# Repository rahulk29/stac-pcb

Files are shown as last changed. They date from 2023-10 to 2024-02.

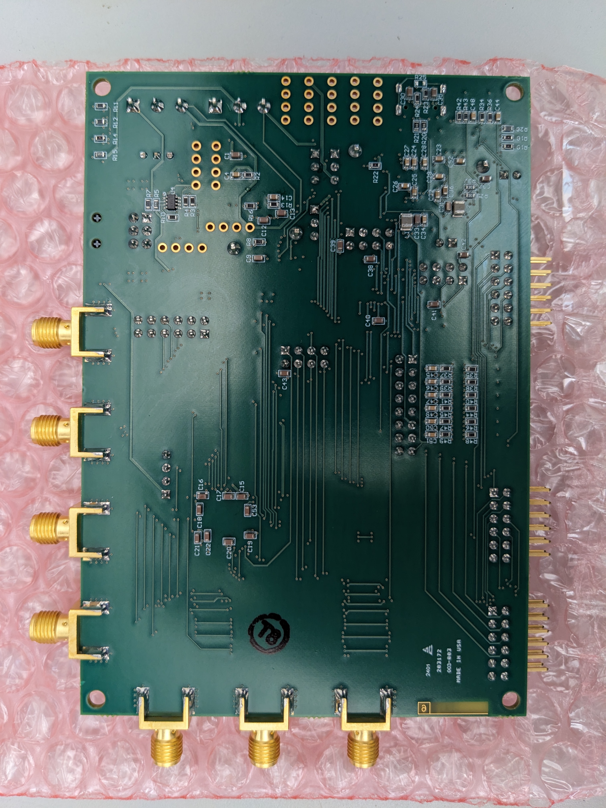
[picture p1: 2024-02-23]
photos/stac_back.jpg

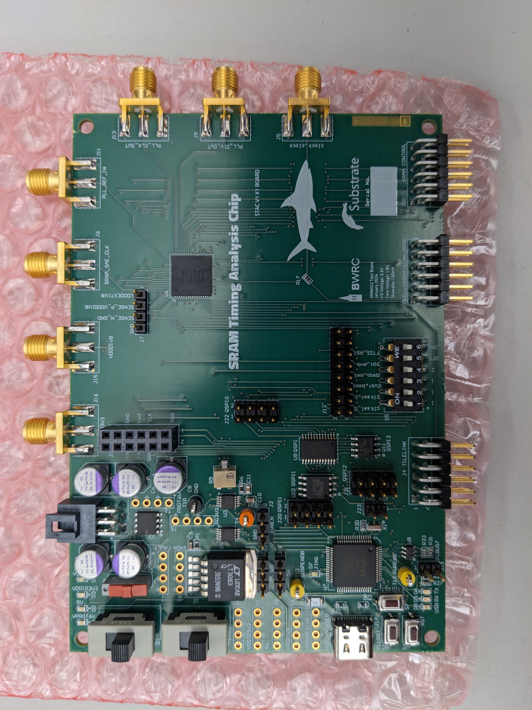
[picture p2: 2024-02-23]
photos/stac_front.jpg

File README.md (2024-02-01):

# STAC PCB

This repo contains the PCB for the SRAM Timing Analysis Chip (STAC).

See the [STAC repo](https://github.com/ucb-bar/stac-top) for more information on STAC.
In short: the STAC chip contains several test SRAM instances generated by SRAM22,
along with circuitry for measuring SRAM correctness and access time.

Also see the [STAC test plan](https://github.com/ucb-bar/stac-top/blob/stac-master/docs/test_plan.md).

## Contributing

Contributions can be submitted by opening a pull request against the `main` branch
of this repository.

Unless you explicitly state otherwise, any contribution intentionally submitted for inclusion
in the work by you shall be licensed under the BSD 3-Clause license, without any additional terms or conditions.

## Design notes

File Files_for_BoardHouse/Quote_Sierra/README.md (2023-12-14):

We received two quotes from Sierra:
* Q1594905-1.doc, which is for 5 day turnaround with blue soldermask.
* Q1594905-2.doc, which is for 10 day turnaround with green soldermask.

Switching to green + 10 days saves over $1,000.

To use an LPI soldermask process, the min pad to pad clearance / soldermask sliver is:
* 8 mils pad to pad (1.5 mil clearance min and 5 mil min web) if the color is not green
* 1.5 mil clearance and 4 mil min web so 7 mils if the color is green

If we are below these thresholds, the soldermask process gets bumped up to LDI-LPI.
Non-green soldermask is expensive because STAC/PROPEL's min soldermask sliver is 7.7 mils,
which requires LDI-LPI. Sierra also seems to charge more for colors other than green, even if
the soldermask process were to be LPI.

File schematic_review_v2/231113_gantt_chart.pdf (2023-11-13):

1 | Summary Test Board Design & Fab | 41 days? | 10/26/23 8:00 AM | 12/21/23 5:00 PM
2 | Create Test Plan doc | 0 days? | 10/26/23 8:00 AM | 10/26/23 8:00 AM
3 | Read wiki PCB Tool Ch01 | 0 days? | 10/26/23 8:00 AM | 10/26/23 8:00 AM
4 | Create new board repo, Test Plan folder | 0 days? | 10/26/23 8:00 AM | 10/26/23 8:00 AM
5 | Designate Chief & First Mate for board | 0 days? | 10/26/23 8:00 AM | 10/26/23 8:00 AM
6 | Create Altium schematic symbol for chip | 0 days? | 10/26/23 8:00 AM | 10/26/23 8:00 AM
7 | Paste chip/pkg schematic symbol into Test Plan doc | 0 days? | 10/26/23 8:00 AM | 10/26/23 8:00 AM
8 | Make decisions about #boards to fab/stuff | 0 days? | 10/26/23 8:00 AM | 10/26/23 8:00 AM
9 | Create Altium schematic for test board | 2 days? | 10/26/23 8:00 AM | 10/27/23 5:00 PM
10 | Make decisions on connector part numbers | 0 days | 10/26/23 8:00 AM | 10/26/23 8:00 AM
11 | Make decisions on reset switches, voltage domains | 0 days | 10/26/23 8:00 AM | 10/26/23 8:00 AM
12 | Add part records to PartSync if new parts | 0 days | 10/26/23 8:00 AM | 10/26/23 8:00 AM
13 | Create new Altium pcb project | 0 days | 10/26/23 8:00 AM | 10/26/23 8:00 AM
14 | Set Altium hierarchical project options | 0 days | 10/26/23 8:00 AM | 10/26/23 8:00 AM
15 | Make power domains global variables | 1 day? | 10/26/23 8:00 AM | 10/26/23 5:00 PM
16 | Put sheet symbols on top-level schematic | 0 days | 10/26/23 5:00 PM | 10/26/23 5:00 PM
17 | Place schematic symbols f/BWRC.SchLib not web | 0 days | 10/26/23 5:00 PM | 10/26/23 5:00 PM
18 | Add manufacturer's part number to all ICs, conns | 0 days? | 10/26/23 5:00 PM | 10/26/23 5:00 PM
19 | Check Altium project's Parameter Manager | 1 day | 10/27/23 8:00 AM | 10/27/23 5:00 PM
20 | Wire up schematic | 0 days | 10/27/23 5:00 PM | 10/27/23 5:00 PM
21 | Re-set reference designators and re-annotate | 0 days | 10/27/23 5:00 PM | 10/27/23 5:00 PM
22 | Compile Altium project, check erro Messages | 0 days | 10/27/23 5:00 PM | 10/27/23 5:00 PM
23 | Fill in title block for each schematic sheet | 0 days | 10/27/23 5:00 PM | 10/27/23 5:00 PM
24 | Create Altium output files for hand-off | 1 day? | 10/27/23 5:00 PM | 10/30/23 5:00 PM
25 | Read wiki PCB Tool Ch10d first half | 1 day | 10/30/23 8:00 AM | 10/30/23 5:00 PM
26 | Add Outjob file to Altium pcb project | 0 days | 10/27/23 5:00 PM | 10/27/23 5:00 PM
27 | Generate pick-and-place file from Outjob window | 1 day? | 10/30/23 8:00 AM | 10/30/23 5:00 PM
28 | Generate schematic pdf from Outjob window | 0 days | 10/30/23 5:00 PM | 10/30/23 5:00 PM
29 | Create folder in board repo for Schematics_pdf | 0 days | 10/30/23 5:00 PM | 10/30/23 5:00 PM
30 | Store latest pdf of schematics there with date/time | 0 days | 10/30/23 5:00 PM | 10/30/23 5:00 PM
31 | Create Bill of Materials in BOM Builder | 1 day? | 10/27/23 5:00 PM | 10/30/23 5:00 PM
32 | Read wiki Ch10d second half | 1 day? | 10/30/23 8:00 AM | 10/30/23 5:00 PM
33 | Configure BOM Builder options | 0 days | 10/27/23 5:00 PM | 10/27/23 5:00 PM
34 | Configure RefDesMapping file for BOM Builder | 0 days | 10/27/23 5:00 PM | 10/27/23 5:00 PM
Name | Duration | Start | Finish

Test Board Design - page1

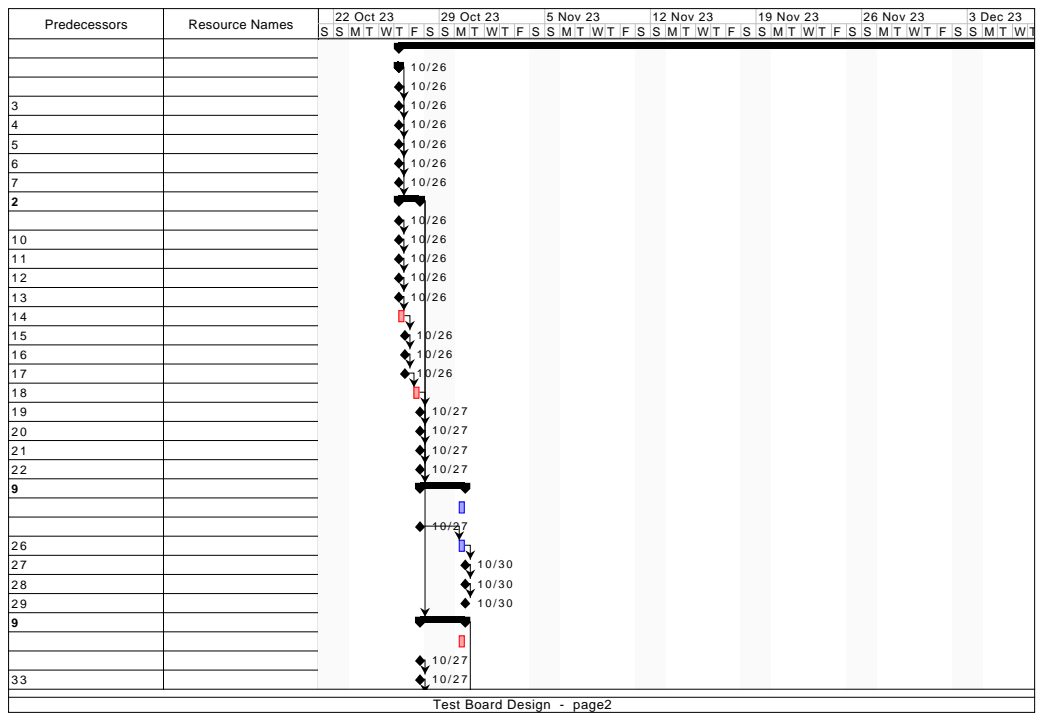
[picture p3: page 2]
22 Oct 23; 29 Oct 23; 5 Nov 23; 12 Nov 23; 19 Nov 23; 26 Nov 23; 3 Dec 23; Predecessors; Resource Names

7 Jan 24

14 Jan 24
M | T | W T | F | S

35 | Configure inpul list processor .dll for importing parts | 0 days | 10/27/23 5:00 PM | 10/27/23 5:00 PM
36 | Import Pick-and-Place file into BOM Builder | 0 days | 10/27/23 5:00 PM | 10/27/23 5:00 PM
37 | Match each line item to real PartSync part | 1 day? | 10/30/23 8:00 AM | 10/30/23 5:00 PM
38 | Create Job directory on G: shared drive for .bmb | 0 days | 10/30/23 5:00 PM | 10/30/23 5:00 PM
39 | Save .bmb file to Job directory | 0 days | 10/30/23 5:00 PM | 10/30/23 5:00 PM
40 | Add Bill of Materials to PartSync | 1 day? | 10/30/23 5:00 PM | 10/31/23 5:00 PM
41 | Read wiki Ch10e | 1 day? | 10/31/23 8:00 AM | 10/31/23 5:00 PM
42 | Import .bmb into PartSync as part list record | 0 days | 10/30/23 5:00 PM | 10/30/23 5:00 PM
43 | Create purchase lilst for build of desired number + spares | 1 day? | 10/31/23 8:00 AM | 10/31/23 5:00 PM
44 | Create folder in repo Files_for_AssemblyHouse | 0 days | 10/31/23 5:00 PM | 10/31/23 5:00 PM
45 | Save purchase list pdf to Files_for_AssemblyHouse | 0 days | 10/31/23 5:00 PM | 10/31/23 5:00 PM
46 | Check schematics & parts | 2 days | 11/1/23 8:00 AM | 11/2/23 5:00 PM
47 | Check schematic pdfs, parts list and fix errors | 1 day | 11/1/23 8:00 AM | 11/1/23 5:00 PM
48 | Iterate and communicate amongst designers | 1 day | 11/2/23 8:00 AM | 11/2/23 5:00 PM
49 | Update personal Gantt chart | 1 day? | 11/3/23 8:00 AM | 11/3/23 5:00 PM
50 | Estimate timelines for post Test Plan Review design changes | 1 day? | 11/3/23 8:00 AM | 11/3/23 5:00 PM
51 | Estimate timelines for ordering parts and/or pastemask stencils | 1 day? | 11/3/23 8:00 AM | 11/3/23 5:00 PM
52 | Estimate timelines for layout tasks post Test Plan Review | 1 day? | 11/3/23 8:00 AM | 11/3/23 5:00 PM
53 | Estimate timeline for checking layout for correctness | 1 day? | 11/3/23 8:00 AM | 11/3/23 5:00 PM
54 | Estimate timelines for comms with vendors | 1 day? | 11/3/23 8:00 AM | 11/3/23 5:00 PM
55 | Estimate timelines for BearBuy orders to vendors | 1 day? | 11/3/23 8:00 AM | 11/3/23 5:00 PM
56 | Estimate timelines for vendor manufacturing & shipping | 1 day? | 11/3/23 8:00 AM | 11/3/23 5:00 PM
57 | Add all steps for testing procedures | 1 day? | 11/3/23 8:00 AM | 11/3/23 5:00 PM
58 | Designers Review | 1 day? | 11/3/23 8:00 AM | 11/3/23 5:00 PM
59 | Chief and First mate and any other designers of the test board meet | 1 day? | 11/3/23 8:00 AM | 11/3/23 5:00 PM
60 | Compare each others Gantt charts and estimates | 1 day? | 11/3/23 8:00 AM | 11/3/23 5:00 PM
61 | Review schematics, test plan and final parts list together | 1 day? | 11/3/23 8:00 AM | 11/3/23 5:00 PM
62 | Correct any errors, make changes to hand-off docs | 1 day? | 11/3/23 8:00 AM | 11/3/23 5:00 PM
63 | Store corrected hand-off docs to git | 1 day? | 11/3/23 8:00 AM | 11/3/23 5:00 PM
64 | Test Plan Review | 2 days? | 11/6/23 8:00 AM | 11/7/23 5:00 PM
65 | Invite 2 outside students | 1 day? | 11/6/23 8:00 AM | 11/6/23 5:00 PM
66 | Send them schematics, parts list, Gantt chart & Test Plan doc 2 days ... | 0 days | 11/6/23 5:00 PM | 11/6/23 5:00 PM
67 | Meet in person or zoom, walk through test plan & these docs | 1 day? | 11/7/23 8:00 AM | 11/7/23 5:00 PM
68 | Post Test Plan Review updates | 1 day? | 11/7/23 5:00 PM | 11/8/23 5:00 PM
Name | Duration | Start | Finish

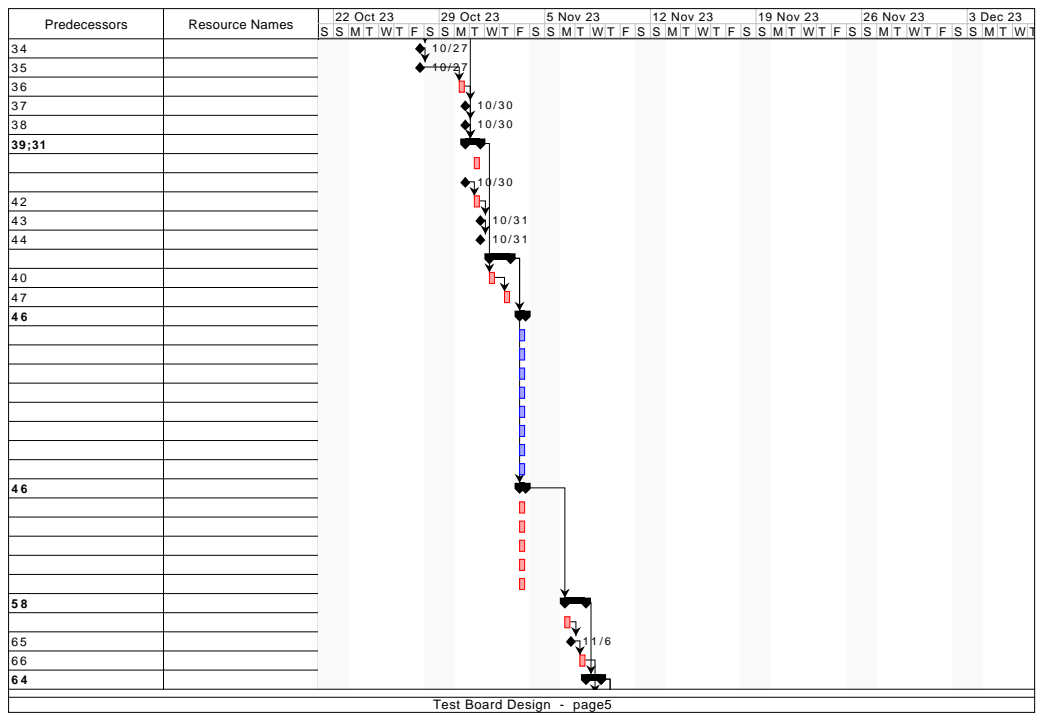
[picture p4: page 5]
22 Oct 23; 29 Oct 23; 5 Nov 23; 12 Nov 23; 19 Nov 23; 26 Nov 23; Predecessors; Resource Names

7 Jan 24

14 Jan 24
M | T | W T | F | S

69 | Update schematics, parts list, Gantt chart and Test Plan | 1 day? | 11/8/23 8:00 AM | 11/8/23 5:00 PM
70 | Add reviewer names & review date to Test Plan doc | 0 days | 11/7/23 5:00 PM | 11/7/23 5:00 PM
71 | Create final set of hand-off documents (for advisor, layout person) | 0 days | 11/8/23 5:00 PM | 11/8/23 5:00 PM
72 | Second schematic review | 1 day? | 11/8/23 8:00 AM | 11/8/23 5:00 PM
73 | Contact reviewers to schedule review time | 1 day? | 11/8/23 8:00 AM | 11/8/23 5:00 PM
74 | Send schematics, test plan, physical plan to reviewers | 1 day? | 11/8/23 8:00 AM | 11/8/23 5:00 PM
75 | Hold review | 1 day? | 11/8/23 8:00 AM | 11/8/23 5:00 PM
76 | Email advisor to notify re hand-off to layout person | 1 day? | 11/9/23 8:00 AM | 11/9/23 5:00 PM
77 | Send email to your advisor | 1 day? | 11/9/23 8:00 AM | 11/9/23 5:00 PM
78 | Attach Test Plan doc | 1 day? | 11/9/23 8:00 AM | 11/9/23 5:00 PM
79 | Attach pdf of schematics | 1 day? | 11/9/23 8:00 AM | 11/9/23 5:00 PM
80 | Attach pdf of Gantt chart | 1 day? | 11/9/23 8:00 AM | 11/9/23 5:00 PM
81 | Attach pdf of purchasing list | 1 day? | 11/9/23 8:00 AM | 11/9/23 5:00 PM
82 | Don't expect your advisor to read these. | 1 day? | 11/9/23 8:00 AM | 11/9/23 5:00 PM
83 | Simply ensure that he/she understands this is the time of handoff | 1 day? | 11/9/23 8:00 AM | 11/9/23 5:00 PM
84 | Email layout person to notify about hand-off to layout | 1 day? | 11/9/23 8:00 AM | 11/9/23 5:00 PM
85 | List in email where hand-off docs are (git etc.) | 1 day? | 11/9/23 8:00 AM | 11/9/23 5:00 PM
86 | Chief student orders parts | 3 days? | 11/9/23 8:00 AM | 11/13/23 5:00 PM
87 | If some boards will assembled in house, assembly house should not or... | 1 day? | 11/9/23 8:00 AM | 11/9/23 5:00 PM
88 | Parts should be ordered through BearBuy and shipped to BWRC | 1 day? | 11/10/23 8:00 AM | 11/10/23 5:00 PM
89 | Parts should be ordered early enough, checked for in stock | 1 day? | 11/9/23 8:00 AM | 11/9/23 5:00 PM
90 | Purchase list should be generated from PartSync part record | 1 day? | 11/9/23 8:00 AM | 11/9/23 5:00 PM
91 | Ensure that any non-board parts are added to part list, if needed (ca... | 1 day? | 11/9/23 8:00 AM | 11/9/23 5:00 PM
92 | Notify advisor of total cost | 1 day? | 11/10/23 8:00 AM | 11/10/23 5:00 PM
93 | Get advisor to tell Candy/Mikaela what chartstring to use | 1 day? | 11/13/23 8:00 AM | 11/13/23 5:00 PM
94 | Submit BearBuy requisition, mark as urgent, note shipping type | 1 day? | 11/13/23 8:00 AM | 11/13/23 5:00 PM
95 | Mouser can ship 2nd day, but Digikey screws up and ships ground | 1 day? | 11/13/23 8:00 AM | 11/13/23 5:00 PM
96 | Assign cart to Candy/Mikaela and talk to them personally to alert them | 1 day? | 11/13/23 8:00 AM | 11/13/23 5:00 PM
97 | After Candy/Mikaela push requisition, check your BearBuy for PO gene... | 1 day? | 11/13/23 8:00 AM | 11/13/23 5:00 PM
98 | Layout person kickoff | 1 day? | 11/9/23 8:00 AM | 11/9/23 5:00 PM
99 | Layout person checks Test Plan for completeness | 1 day? | 11/9/23 8:00 AM | 11/9/23 5:00 PM
100 | Notify designers of schematic errors, missing info. Iterate. | 1 day? | 11/9/23 8:00 AM | 11/9/23 5:00 PM
101 | Request prelimary stackup from board house | 1 day? | 11/9/23 8:00 AM | 11/9/23 5:00 PM
102 | Rough out board size | 8 days? | 11/10/23 8:00 AM | 11/21/23 5:00 PM
Name | Duration | Start | Finish

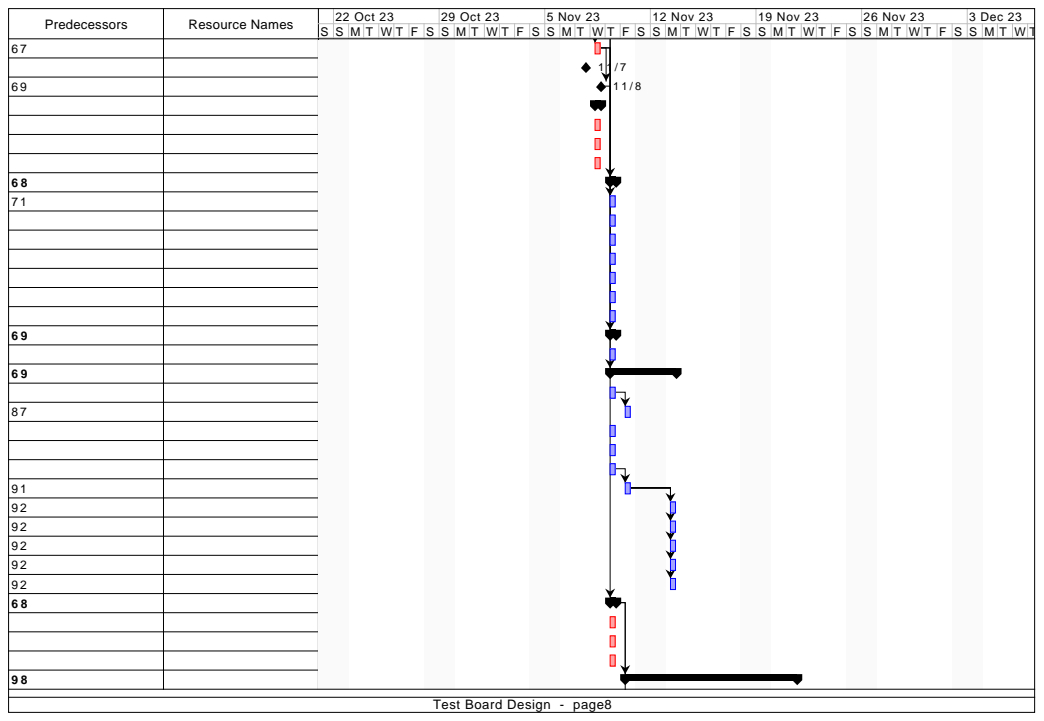
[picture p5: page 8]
22 Oct 23; 29 Oct 23; 5 Nov 23; 12 Nov 23; 19 Nov 23; 26 Nov 23; Predecessors; Resource Names

7 Jan 24

14 Jan 24
M | T | W T | F | S

103 | Get footprint names from PartSync | 1 day? | 11/10/23 8:00 AM | 11/10/23 5:00 PM
104 | Add footprint names to schematic sheets | 1 day? | 11/13/23 8:00 AM | 11/13/23 5:00 PM
105 | Compile schematic and push to PCB side | 1 day? | 11/14/23 8:00 AM | 11/14/23 5:00 PM
106 | Place connectors and large components roughly | 1 day? | 11/15/23 8:00 AM | 11/15/23 5:00 PM
107 | Learn SolidWorks basics | 1 day? | 11/16/23 8:00 AM | 11/16/23 5:00 PM
108 | Read wiki PCB Tool Ch08, overview & SMA spacing | 1 day? | 11/17/23 8:00 AM | 11/17/23 5:00 PM
109 | Look at panel in SolidWorks and determine # per panel | 1 day? | 11/20/23 8:00 AM | 11/20/23 5:00 PM
110 | Update Test Plan doc with screenshots of board & panel | 1 day? | 11/21/23 8:00 AM | 11/21/23 5:00 PM
111 | Board layout | 7 days? | 11/10/23 8:00 AM | 11/20/23 5:00 PM
112 | Add/create package models in PackEdit | 7 days | 11/10/23 8:00 AM | 11/20/23 5:00 PM
113 | Add/edit footprints to BWRC.PcbLib and/or schematics | 1 day | 11/10/23 8:00 AM | 11/10/23 5:00 PM
114 | Order a few parts if necessary to check parts to 1:1 printed footprints | 1 day | 11/10/23 8:00 AM | 11/10/23 5:00 PM
115 | Create board outline | 1 day | 11/10/23 8:00 AM | 11/10/23 5:00 PM
116 | Create board statckup as all signal layers | 1 day | 11/10/23 8:00 AM | 11/10/23 5:00 PM
117 | Create edge keepouts for polygon pours for pwd, gnd layers | 1 day | 11/10/23 8:00 AM | 11/10/23 5:00 PM
118 | Modify placement of parts | 1 day | 11/10/23 8:00 AM | 11/10/23 5:00 PM
119 | Create all DRC rules in Altium's rule editor | 1 day | 11/10/23 8:00 AM | 11/10/23 5:00 PM
120 | Set Altium project options for net colors, rooms, comparator | 1 day | 11/10/23 8:00 AM | 11/10/23 5:00 PM
121 | Update schematics with net names for every net | 1 day | 11/10/23 8:00 AM | 11/10/23 5:00 PM
122 | Update schematics with net classes for controlled impedance traces | 1 day | 11/10/23 8:00 AM | 11/10/23 5:00 PM
123 | Create mounting holes and keepouts for screw heads, standoffs | 1 day | 11/10/23 8:00 AM | 11/10/23 5:00 PM
124 | Create SolidWorks assembly of test setup | 1 day | 11/10/23 8:00 AM | 11/10/23 5:00 PM
125 | Set placement of board-to-board connectors | 1 day? | 11/10/23 8:00 AM | 11/10/23 5:00 PM
126 | Select mechanical parts & order from McMaster | 1 day? | 11/10/23 8:00 AM | 11/10/23 5:00 PM
127 | Buy new parts not previously used to check footprints | 1 day? | 11/10/23 8:00 AM | 11/10/23 5:00 PM
128 | Check vacation schedule for anyone in Bear Buy approval path | 1 day? | 11/10/23 8:00 AM | 11/10/23 5:00 PM
129 | Check with Purchasing if Digikey 2nd day is still screwed up | 1 day? | 11/10/23 8:00 AM | 11/10/23 5:00 PM
130 | Double-check all bypass caps and polarized caps | 1 day? | 11/10/23 8:00 AM | 11/10/23 5:00 PM
131 | Determine if board can fit within Beam On jig for in-house assembly | 1 day? | 11/10/23 8:00 AM | 11/10/23 5:00 PM
132 | Add ficucials for assembly | 1 day? | 11/10/23 8:00 AM | 11/10/23 5:00 PM
133 | Add layer numbering test structure | 1 day? | 11/10/23 8:00 AM | 11/10/23 5:00 PM
134 | Check tented vs. untented vias | 1 day? | 11/10/23 8:00 AM | 11/10/23 5:00 PM
135 | Remove internal pads | 1 day? | 11/10/23 8:00 AM | 11/10/23 5:00 PM
136 | Set line width for controlled impedance traces | 1 day? | 11/10/23 8:00 AM | 11/10/23 5:00 PM
Name | Duration | Start | Finish

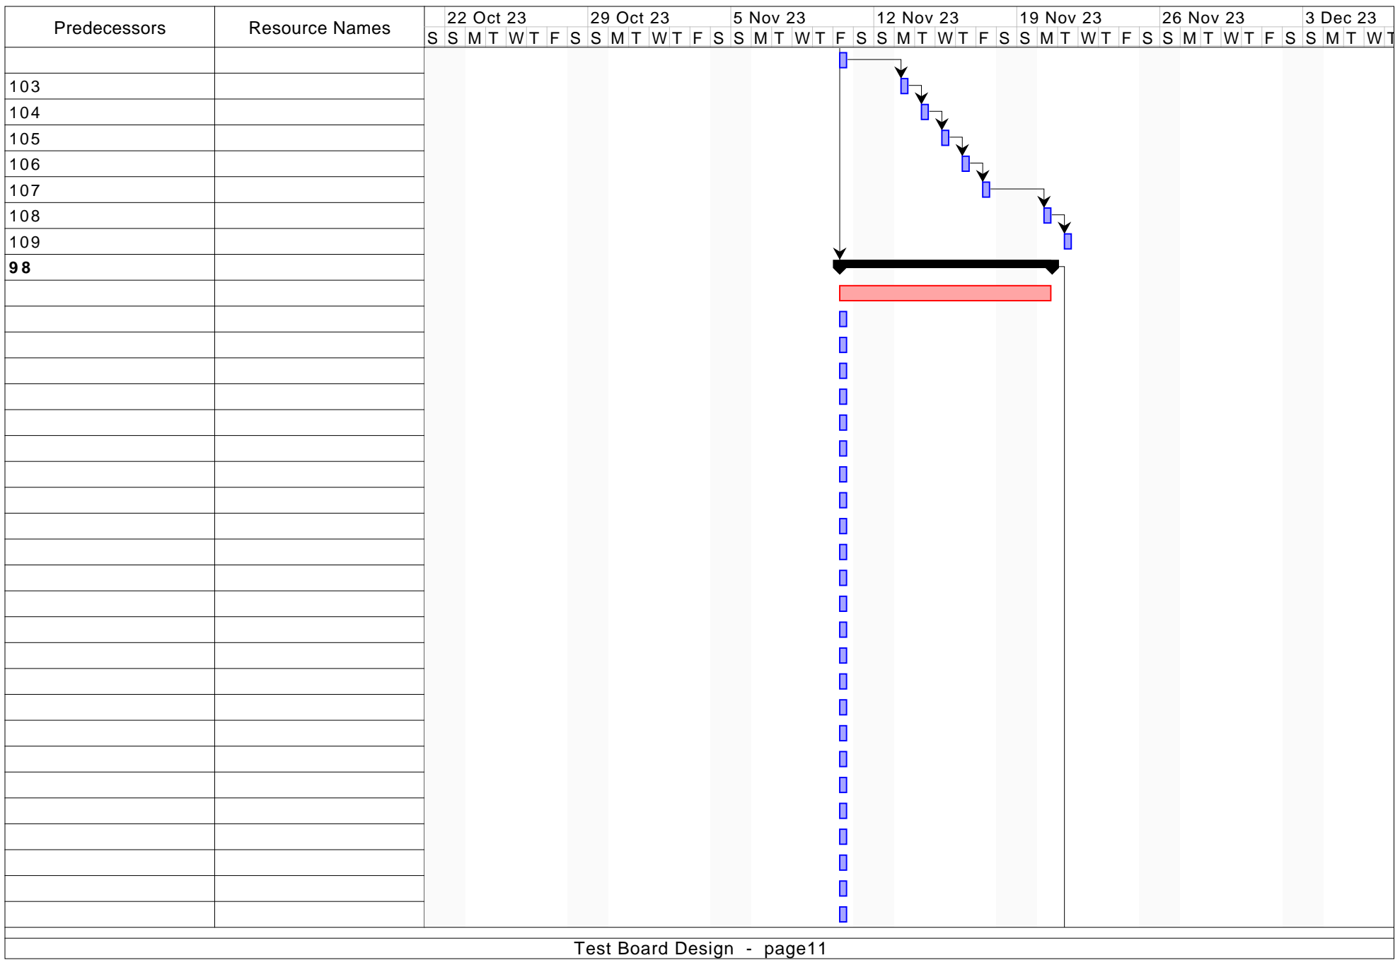
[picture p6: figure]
22 Oct 23; 29 Oct 23; 5 Nov 23; 12 Nov 23; 19 Nov 23; 26 Nov 23; Predecessors; Resource Names

7 Jan 24

14 Jan 24
M | T | W T | F | S

137 | Create fab drawing and add to Altium project | 1 day? | 11/10/23 8:00 AM | 11/10/23 5:00 PM
138 | Note controlled impedance trace widths in fab drawing | 1 day? | 11/10/23 8:00 AM | 11/10/23 5:00 PM
139 | Note mounted cross-sections on fab drawing | 1 day? | 11/10/23 8:00 AM | 11/10/23 5:00 PM
140 | Check fab drawing drill table for all hole tolerances | 1 day? | 11/10/23 8:00 AM | 11/10/23 5:00 PM
141 | Add free text to silkscreen layers | 1 day? | 11/10/23 8:00 AM | 11/10/23 5:00 PM
142 | Add BWRC logo, name, date and serial number block to silkscreen | 1 day? | 11/10/23 8:00 AM | 11/10/23 5:00 PM
143 | View bottom silkscreen from backside to check rotation of text | 1 day? | 11/10/23 8:00 AM | 11/10/23 5:00 PM
144 | Set up Outjob file for test point report, ODB, Gerbers, fab drawing | 1 day? | 11/10/23 8:00 AM | 11/10/23 5:00 PM
145 | Update the fab drawing with latest changes | 1 day? | 11/10/23 8:00 AM | 11/10/23 5:00 PM
146 | Check no stale via types are inadvertently added | 1 day? | 11/10/23 8:00 AM | 11/10/23 5:00 PM
147 | Add free ground vias for return currents crossing layers | 1 day? | 11/10/23 8:00 AM | 11/10/23 5:00 PM
148 | Create custom room on PCB side if needed. Adjust project options. | 1 day? | 11/10/23 8:00 AM | 11/10/23 5:00 PM
149 | Check necking and isolation settings in Polygon Manager | 1 day? | 11/10/23 8:00 AM | 11/10/23 5:00 PM
150 | Check thermal reliefs and via direct-connects | 1 day? | 11/10/23 8:00 AM | 11/10/23 5:00 PM
151 | In Rules editor, ensure all rules are enabled when DRC checking | 1 day? | 11/10/23 8:00 AM | 11/10/23 5:00 PM
152 | Set diff pair rules carefully | 1 day? | 11/10/23 8:00 AM | 11/10/23 5:00 PM
153 | Create polygon regions on pwer layers for voltage domains | 1 day? | 11/10/23 8:00 AM | 11/10/23 5:00 PM
154 | Layout out all traces after fanning out pwr, gnd | 1 day? | 11/10/23 8:00 AM | 11/10/23 5:00 PM
155 | Create board output files | 1 day? | 11/21/23 8:00 AM | 11/21/23 5:00 PM
156 | Generate Gerber files for BOM Builder checking | 1 day? | 11/21/23 8:00 AM | 11/21/23 5:00 PM
157 | Create folder in repo, Files_for_BoardHouse | 1 day? | 11/21/23 8:00 AM | 11/21/23 5:00 PM
158 | Generate ODB .zip file for board house | 1 day? | 11/21/23 8:00 AM | 11/21/23 5:00 PM
159 | Create pdf of fab drawing | 1 day? | 11/21/23 8:00 AM | 11/21/23 5:00 PM
160 | Create test point file for board house | 1 day? | 11/21/23 8:00 AM | 11/21/23 5:00 PM
161 | Save ODB, test pt repot, fab drawing to Files_for_BoardHouse | 1 day? | 11/21/23 8:00 AM | 11/21/23 5:00 PM
162 | Check package models to footprints with BOM Builder | 1 day? | 11/22/23 8:00 AM | 11/22/23 5:00 PM
163 | Use Outjob file to generate a new Pick-and-Place file after layout | 1 day? | 11/22/23 8:00 AM | 11/22/23 5:00 PM
164 | This generation of Pick-and-Place file now has XYRS layout info | 1 day? | 11/22/23 8:00 AM | 11/22/23 5:00 PM
165 | Import XYRS info into BOM Builder | 1 day? | 11/22/23 8:00 AM | 11/22/23 5:00 PM
166 | Import Gerber files of layout into BOM Builder | 1 day? | 11/22/23 8:00 AM | 11/22/23 5:00 PM
167 | Check each line item entry while zooming in Assembly view | 1 day? | 11/22/23 8:00 AM | 11/22/23 5:00 PM
168 | Ensure packages all match to footprints | 1 day? | 11/22/23 8:00 AM | 11/22/23 5:00 PM
169 | Ensure traces all exit footprints orthogonally | 1 day? | 11/22/23 8:00 AM | 11/22/23 5:00 PM
170 | Save out Smart PDF from BOM Builder | 1 day? | 11/22/23 8:00 AM | 11/22/23 5:00 PM
Name | Duration | Start | Finish

S S

22 Oct 23

29 Oct 23

5 Nov 23

12 Nov 23

19 Nov 23

26 Nov 23
M | T | W T

111

155

Predecessors | Resource Names

7 Jan 24

14 Jan 24
M | T | W T | F | S

171 | Save out Assembly BOM from BOM Builder | 1 day? | 11/22/23 8:00 AM | 11/22/23 5:00 PM
172 | In board repo, create Files_for_AssemblyHouse folder | 1 day? | 11/22/23 8:00 AM | 11/22/23 5:00 PM
173 | Prefix file names of Smart PDF and Assembly BOM with date | 1 day? | 11/22/23 8:00 AM | 11/22/23 5:00 PM
174 | Save both files to Files_for_AssemblyHouse folder | 1 day? | 11/22/23 8:00 AM | 11/22/23 5:00 PM
175 | Tell student designers to also do this check of package models to Ger... | 1 day? | 11/22/23 8:00 AM | 11/22/23 5:00 PM
176 | Prepare Request For Quote (RFQ) to board house | 1 day? | 11/22/23 8:00 AM | 11/22/23 5:00 PM
177 | Create RFQ sub-folder in Files_for_BoardHouse dir | 1 day? | 11/22/23 8:00 AM | 11/22/23 5:00 PM
178 | Check prev students' board repos for example RFQ pptx | 1 day? | 11/22/23 8:00 AM | 11/22/23 5:00 PM
179 | Make pptx file asking for what the quote should cover | 1 day? | 11/22/23 8:00 AM | 11/22/23 5:00 PM
180 | In pptx, ask for number of boards to be fabbed, dielectric mat & plati... | 1 day? | 11/22/23 8:00 AM | 11/22/23 5:00 PM
181 | In pptx, request quotes for both 5-day turn and 10-day turn | 1 day? | 11/22/23 8:00 AM | 11/22/23 5:00 PM
182 | In pptx, don't forget to ask for mounted cross-sections. | 1 day? | 11/22/23 8:00 AM | 11/22/23 5:00 PM
183 | Add dated ODB .zip file to this sub-folder | 1 day? | 11/22/23 8:00 AM | 11/22/23 5:00 PM
184 | Add preliminary stackup, fab drwg pdf, test point report, to this sub-f... | 1 day? | 11/22/23 8:00 AM | 11/22/23 5:00 PM
185 | Ensure to ask for specials: controlled impedance traces, vias in pads | 1 day? | 11/22/23 8:00 AM | 11/22/23 5:00 PM
186 | Organize & log communications with vendors | 1 day? | 11/23/23 8:00 AM | 11/23/23 5:00 PM
187 | Create communications_to_vendors txt file | 1 day? | 11/23/23 8:00 AM | 11/23/23 5:00 PM
188 | Look in prev students' repos' Test Plan folder for this txt file | 1 day? | 11/23/23 8:00 AM | 11/23/23 5:00 PM
189 | Format the text of an email to board house | 1 day? | 11/23/23 8:00 AM | 11/23/23 5:00 PM
190 | List the full name of each included file | 1 day? | 11/23/23 8:00 AM | 11/23/23 5:00 PM
191 | Make sure each file name starts with the date | 1 day? | 11/23/23 8:00 AM | 11/23/23 5:00 PM
192 | Save this communications_to_vendors.txt to Test Plan folder | 1 day? | 11/23/23 8:00 AM | 11/23/23 5:00 PM
193 | Chief student sends RFQ to board house | 1 day? | 11/24/23 8:00 AM | 11/24/23 5:00 PM
194 | Email designers to pull these files from the repo | 1 day? | 11/24/23 8:00 AM | 11/24/23 5:00 PM
195 | Have them double-check for errors | 1 day? | 11/24/23 8:00 AM | 11/24/23 5:00 PM
196 | Have them forward the email to the board house w/attachments | 1 day? | 11/24/23 8:00 AM | 11/24/23 5:00 PM
197 | Include attachments: prelim stackup, ODB, fab drwg, test point report... | 1 day? | 11/24/23 8:00 AM | 11/24/23 5:00 PM
198 | Tell students to cc layout person on this email to board house | 1 day? | 11/24/23 8:00 AM | 11/24/23 5:00 PM
199 | Tell students to alert advisor that quote is imminent | 1 day? | 11/24/23 8:00 AM | 11/24/23 5:00 PM
200 | Have students learn to how to create a BearBuy requisition | 1 day? | 11/24/23 8:00 AM | 11/24/23 5:00 PM
201 | Have students notify Candy/Mikaela that this requisition will come to th... | 1 day? | 11/24/23 8:00 AM | 11/24/23 5:00 PM
202 | Chief student submits BearBuy requisition after board quote arrives | 1 day? | 11/27/23 8:00 AM | 11/27/23 5:00 PM
203 | Notify advisor re amount of quote | 1 day? | 11/27/23 8:00 AM | 11/27/23 5:00 PM
204 | Get advisor to tell Candy/Mikaela what chartstring to use | 1 day? | 11/27/23 8:00 AM | 11/27/23 5:00 PM
Name | Duration | Start | Finish

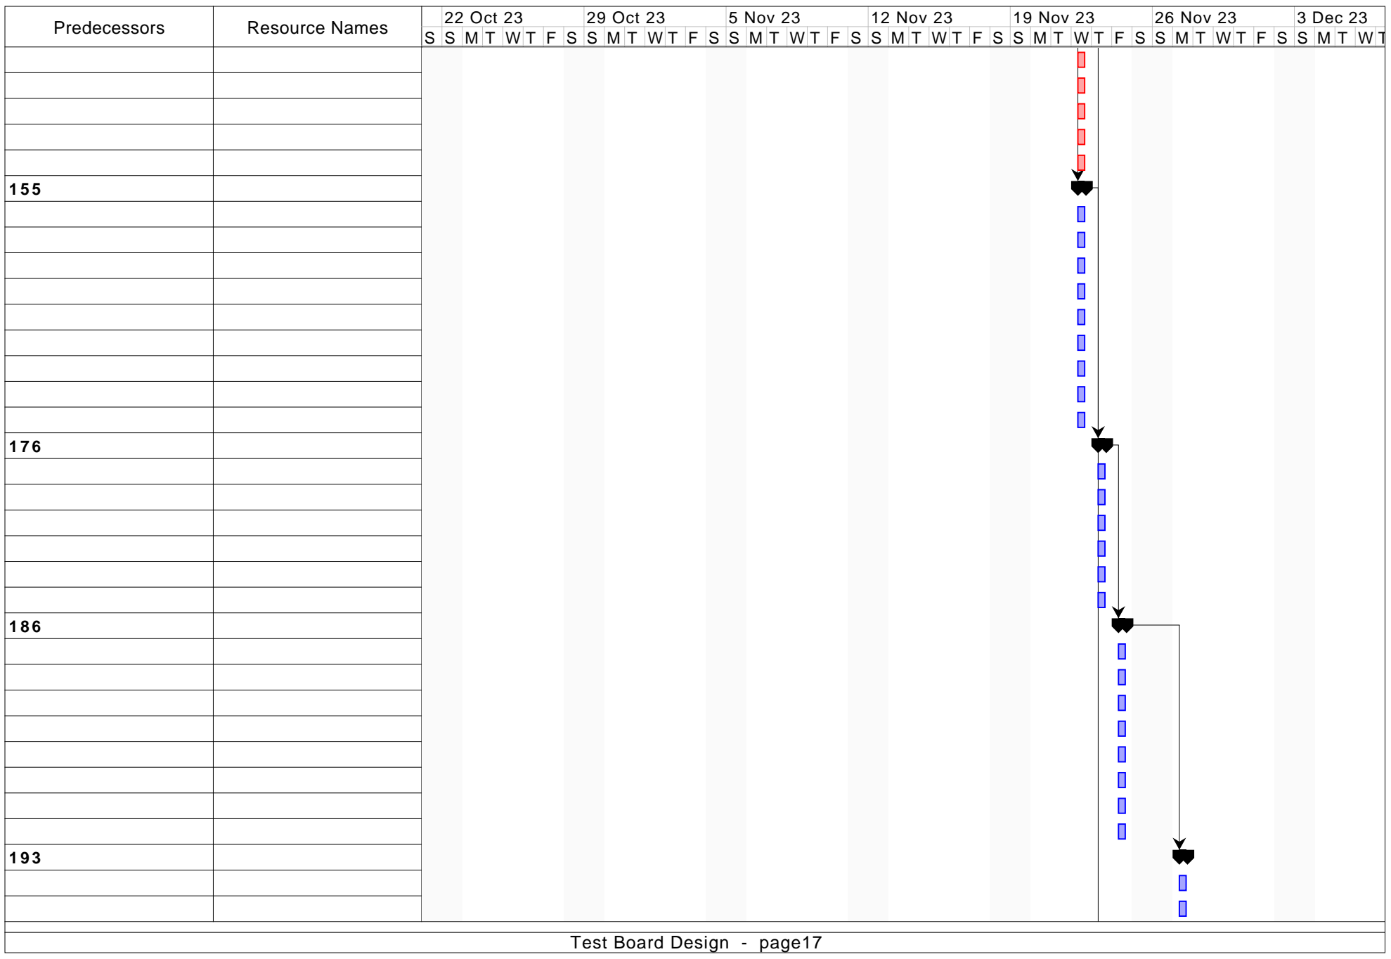
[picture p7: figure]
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

7 Jan 24

14 Jan 24
M | T | W T | F | S

205 | Submit BearBuy requisition, mark as urgent, note shipping type | 1 day? | 11/27/23 8:00 AM | 11/27/23 5:00 PM
206 | Shipping type: will you drive to pick up, or have boards sent to BWRC? | 1 day? | 11/27/23 8:00 AM | 11/27/23 5:00 PM
207 | Assign cart to Candy/Mikaela and talk to them personally to alert them | 1 day? | 11/27/23 8:00 AM | 11/27/23 5:00 PM
208 | Email board house that PO is in process | 1 day? | 11/27/23 8:00 AM | 11/27/23 5:00 PM
209 | Email board house if board house CAM shop should wait for updated f... | 1 day? | 11/27/23 8:00 AM | 11/27/23 5:00 PM
210 | After Candy/Mikaela push requisition, check your BearBuy for PO gene... | 1 day? | 11/27/23 8:00 AM | 11/27/23 5:00 PM
211 | Check ODB files with Viewmate Deluxe & EMS Magician | 1 day? | 11/23/23 8:00 AM | 11/23/23 5:00 PM
212 | Set up Viewmate Deluxe and read in ODB files | 1 day? | 11/23/23 8:00 AM | 11/23/23 5:00 PM
213 | Create rules to check in EMS Magician | 1 day? | 11/23/23 8:00 AM | 11/23/23 5:00 PM
214 | If errors, update design and re-generate all output files | 1 day? | 11/23/23 8:00 AM | 11/23/23 5:00 PM
215 | Tell student designers to also do this checking | 1 day? | 11/23/23 8:00 AM | 11/23/23 5:00 PM
216 | Chief student works with board house CAM shop | 1 day? | 11/24/23 8:00 AM | 11/24/23 5:00 PM
217 | Chief student monitors BearBuy for PO sent to board house | 1 day? | 11/24/23 8:00 AM | 11/24/23 5:00 PM
218 | Make any last minute changes, re-generate all output files | 1 day? | 11/24/23 8:00 AM | 11/24/23 5:00 PM
219 | If changes, create folder in repo, Final_files_to_BoardHouse | 1 day? | 11/24/23 8:00 AM | 11/24/23 5:00 PM
220 | Prefix all files with date and save complete set to that directory | 1 day? | 11/24/23 8:00 AM | 11/24/23 5:00 PM
221 | Compose text of email to board house, listing these files | 1 day? | 11/24/23 8:00 AM | 11/24/23 5:00 PM
222 | Save text to communications_to_vendors.txt, with date | 1 day? | 11/24/23 8:00 AM | 11/24/23 5:00 PM
223 | CAM shop at board house will create a ticket portal at their web site | 1 day? | 11/24/23 8:00 AM | 11/24/23 5:00 PM
224 | Fix any errors that the CAM shop requires | 1 day? | 11/24/23 8:00 AM | 11/24/23 5:00 PM
225 | Re-generate all files, prefix with date and save to folder | 1 day? | 11/24/23 8:00 AM | 11/24/23 5:00 PM
226 | Update communications_to_vendors.txt with any updates, for the record | 1 day? | 11/24/23 8:00 AM | 11/24/23 5:00 PM
227 | The 5-day or 10-day turn clock starts AFTER CAM agrees to go ahead | 1 day? | 11/24/23 8:00 AM | 11/24/23 5:00 PM
228 | Make sure to tell CAM shop how to ship or if you will pick up | 1 day? | 11/24/23 8:00 AM | 11/24/23 5:00 PM
229 | Prepare RFQ to stencil house for pastemask stencil & Durostone ho... | 1 day? | 11/24/23 8:00 AM | 11/24/23 5:00 PM
230 | Create folder in repo, Files_for_StencilHouse | 1 day? | 11/24/23 8:00 AM | 11/24/23 5:00 PM
231 | Store ODB file and fab drawing, with date prefixed to this folder | 1 day? | 11/24/23 8:00 AM | 11/24/23 5:00 PM
232 | Board size must be less than 5" x 3.5" for this in-house assembly | 1 day? | 11/24/23 8:00 AM | 11/24/23 5:00 PM
233 | Format text of email to Beam On for RFQ, store in comms_to_vendors | 1 day? | 11/24/23 8:00 AM | 11/24/23 5:00 PM
234 | Chief student sends RFQ to stencil house | 1 day? | 11/27/23 8:00 AM | 11/27/23 5:00 PM
235 | Have student forward the email w/attachments to stencil house, cc lay... | 1 day? | 11/27/23 8:00 AM | 11/27/23 5:00 PM
236 | Chief student submits BearBuy requisition after stencil quote arrives | 1 day? | 11/28/23 8:00 AM | 11/28/23 5:00 PM
237 | Notify advisor re amount of quote | 1 day? | 11/28/23 8:00 AM | 11/28/23 5:00 PM
238 | Get advisor to tell Candy/Mikaela what chartstring to use | 1 day? | 11/28/23 8:00 AM | 11/28/23 5:00 PM
Name | Duration | Start | Finish

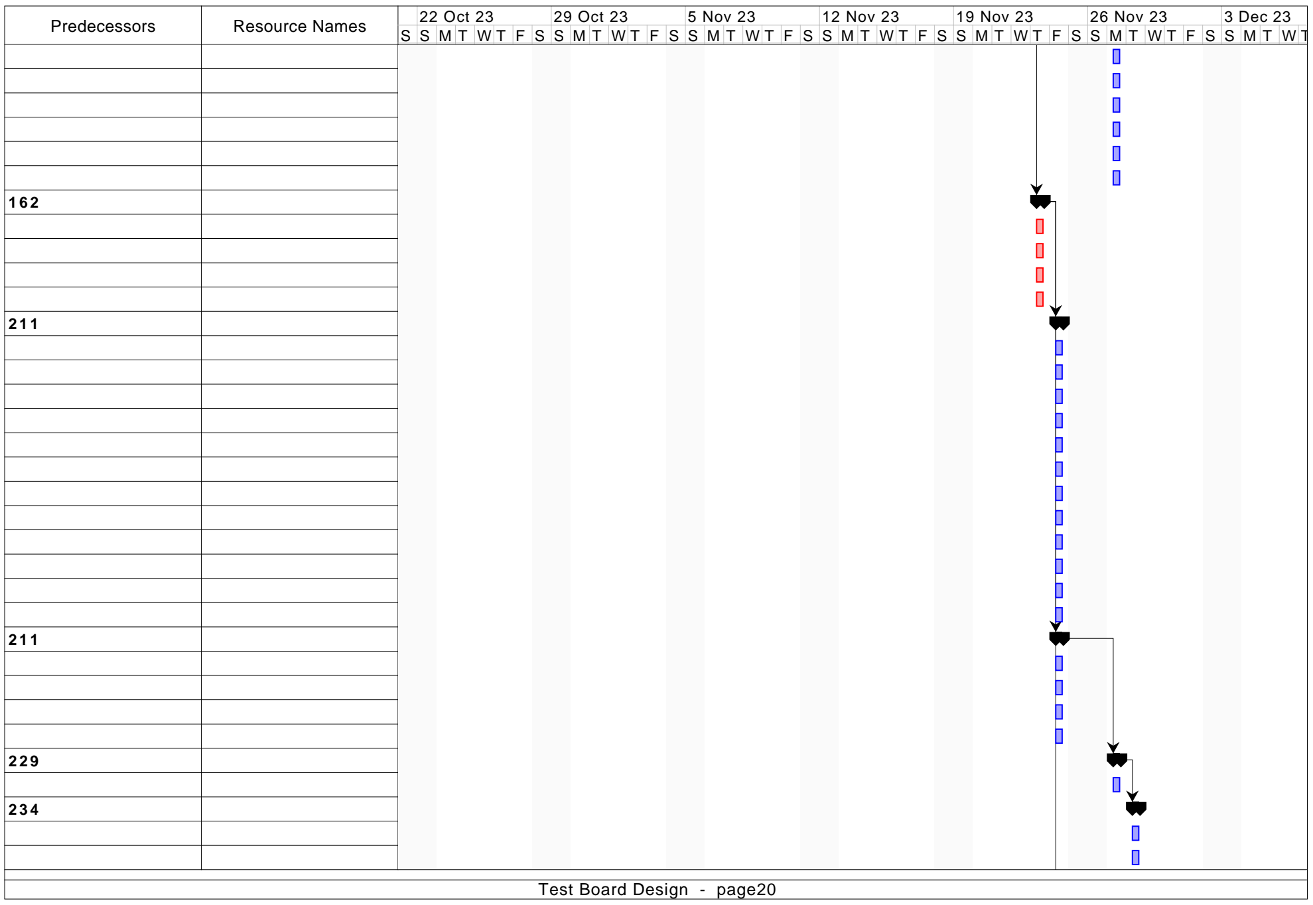
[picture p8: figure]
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

7 Jan 24

14 Jan 24
M | T | W T | F | S

239 | Submit BearBuy requisition, mark as urgent, note shipping type | 1 day? | 11/28/23 8:00 AM | 11/28/23 5:00 PM
240 | Email stencil house that PO is in process | 1 day? | 11/28/23 8:00 AM | 11/28/23 5:00 PM
241 | Watch BearBuy to see when PO goes through | 1 day? | 11/28/23 8:00 AM | 11/28/23 5:00 PM
242 | Beam On usually makes the stencil in one day and then ships it overnig... | 1 day? | 11/28/23 8:00 AM | 11/28/23 5:00 PM
243 | Prepare RFQ to assembly house | 1 day? | 11/24/23 8:00 AM | 11/24/23 5:00 PM
244 | Create sub-folder for RFQ_to_AssemblyHouse within Files_for_Assembl... | 1 day? | 11/24/23 8:00 AM | 11/24/23 5:00 PM
245 | Create pptx RFQ asking for # to stuff, instructions re SMA heat sinks, v... | 1 day? | 11/24/23 8:00 AM | 11/24/23 5:00 PM
246 | Specifiy parts you will supply, number of bare boards you will supply | 1 day? | 11/24/23 8:00 AM | 11/24/23 5:00 PM
247 | Specify number of SMA heat sinks you will supply, and if stencil jig and... | 1 day? | 11/24/23 8:00 AM | 11/24/23 5:00 PM
248 | Prefix with date, and store ODB, fab drwg, Smart PDF, Assembly BOM,... | 1 day? | 11/24/23 8:00 AM | 11/24/23 5:00 PM
249 | Prepare text of email to assembly house for RFQ, store in comms_to_v... | 1 day? | 11/24/23 8:00 AM | 11/24/23 5:00 PM
250 | Chief student sends RFQ to assembly house | 1 day? | 11/27/23 8:00 AM | 11/27/23 5:00 PM
251 | Have student forward the email w/attachments to assembly house, cc l... | 1 day? | 11/27/23 8:00 AM | 11/27/23 5:00 PM
252 | Chief student submits BearBuy requisition after assembly quote ar... | 1 day? | 11/28/23 8:00 AM | 11/28/23 5:00 PM
253 | Notify advisor re amount of quote | 1 day? | 11/28/23 8:00 AM | 11/28/23 5:00 PM
254 | Get advisor to tell Candy/Mikaela what chartstring to use | 1 day? | 11/28/23 8:00 AM | 11/28/23 5:00 PM
255 | Submit BearBuy requisition, note shipping type or if you will pick up | 1 day? | 11/28/23 8:00 AM | 11/28/23 5:00 PM
256 | Email assembly house that PO is in process | 1 day? | 11/28/23 8:00 AM | 11/28/23 5:00 PM
257 | Watch BearBuy to see when PO goes through | 1 day? | 11/28/23 8:00 AM | 11/28/23 5:00 PM
258 | Communicate with assembly house if boards should be sent to BWRC o... | 1 day? | 11/28/23 8:00 AM | 11/28/23 5:00 PM
259 | Board Sent for fabrication | 8 days? | 11/27/23 8:00 AM | 12/6/23 5:00 PM
260 | Fabrication | 7 days? | 11/27/23 8:00 AM | 12/5/23 5:00 PM
261 | Check boards upon return | 1 day? | 12/6/23 8:00 AM | 12/6/23 5:00 PM
262 | Chips Arrive at BWRC | 1 day? | 10/30/23 7:00 AM | 10/30/23 5:00 PM
263 | Board Sent for assembly | 7 days? | 12/7/23 8:00 AM | 12/15/23 5:00 PM
264 | Bringup | 18 days? | 11/28/23 8:00 AM | 12/21/23 5:00 PM
265 | Collect equipment | 1 day? | 11/28/23 8:00 AM | 11/28/23 5:00 PM
266 | Program Arty A7-100T | 7 days? | 11/28/23 8:00 AM | 12/6/23 5:00 PM
267 | Bring up scan chain | 7 days? | 11/28/23 8:00 AM | 12/6/23 5:00 PM
268 | Bring up Rocket | 7 days? | 12/7/23 8:00 AM | 12/15/23 5:00 PM
269 | Program SRAM BIST | 2 days? | 12/18/23 8:00 AM | 12/19/23 5:00 PM
270 | Prepare SRAM BIST patterns | 2 days? | 12/20/23 8:00 AM | 12/21/23 5:00 PM
271 | Test SRAMs with BIST, varying frequency and pattern | 4 days? | 11/28/23 8:00 AM | 12/1/23 5:00 PM
272 | Test SRAMs with varying supply voltage | 1 day? | 11/28/23 8:00 AM | 11/28/23 5:00 PM
Name | Duration | Start | Finish

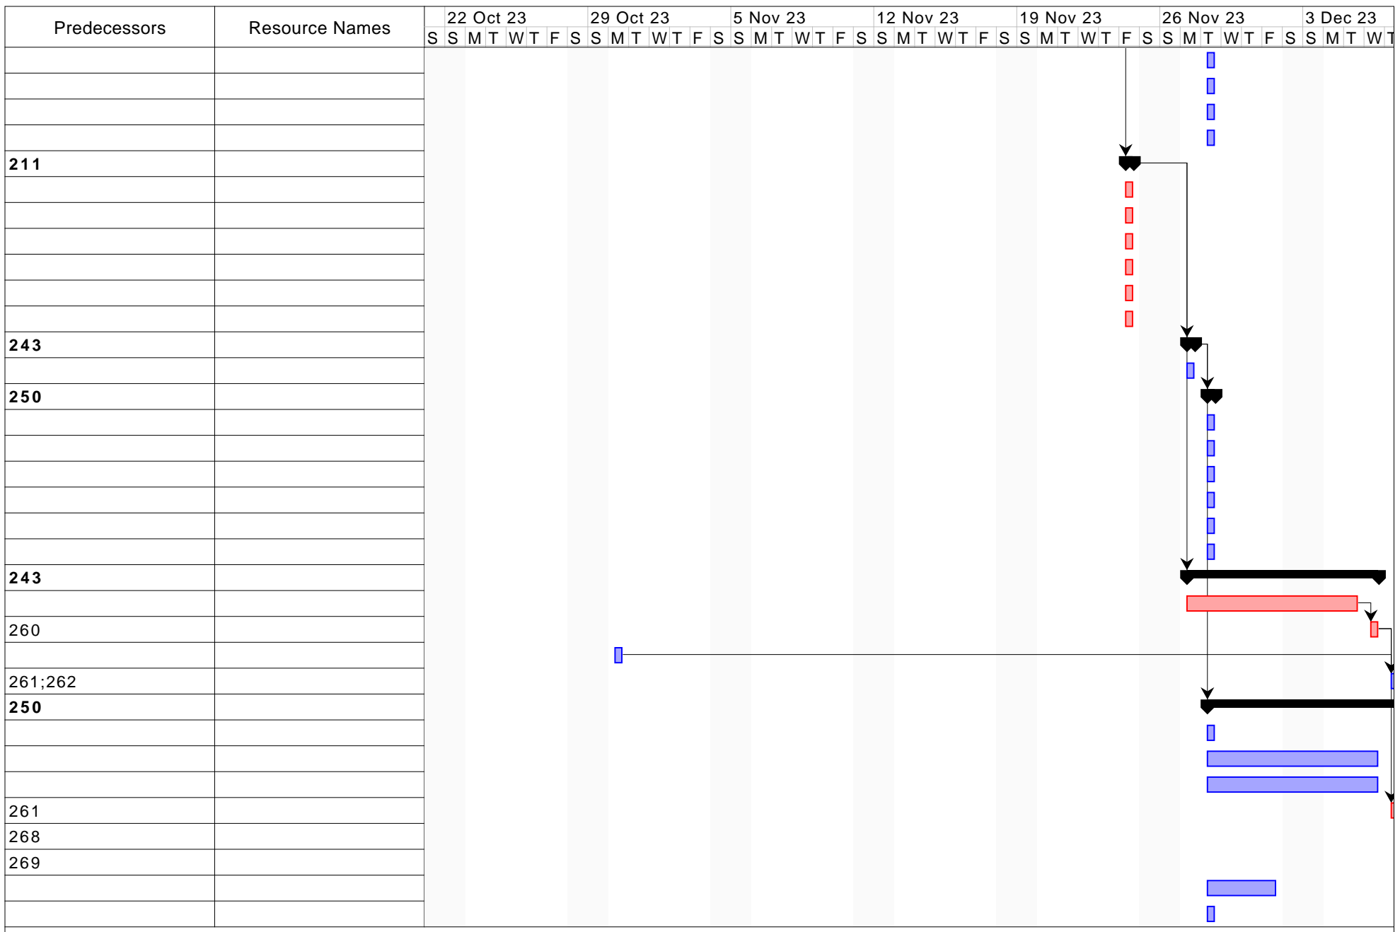
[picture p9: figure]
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

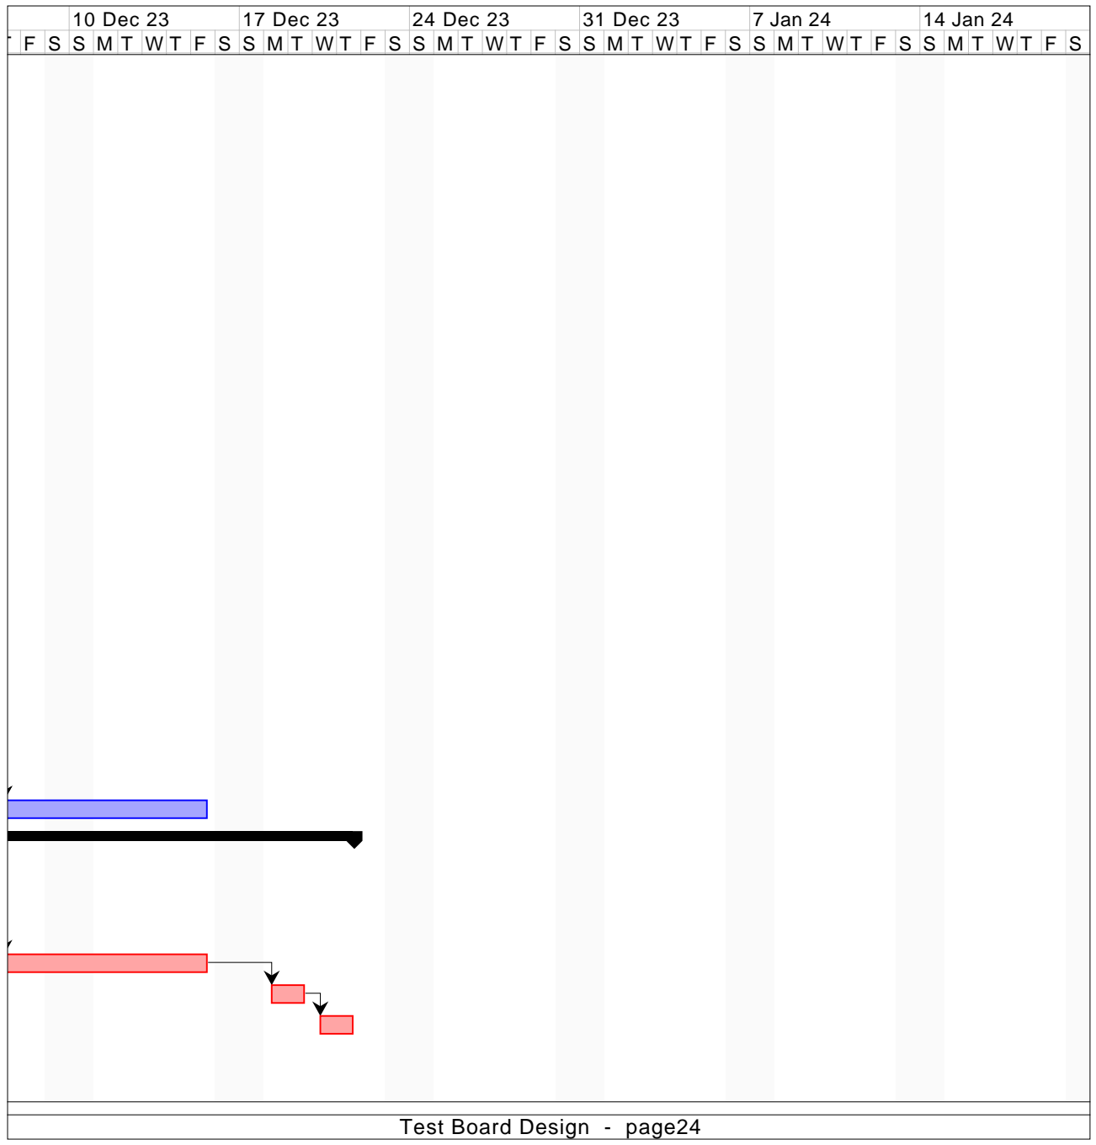
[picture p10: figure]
7 Jan 24; 14 Jan 24

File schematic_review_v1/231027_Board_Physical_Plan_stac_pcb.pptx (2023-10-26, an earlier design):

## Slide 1

10/24/23

Board Physical Plan
STAC-v1

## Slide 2

Fill in the following tables:

| Name | Email | Cell Number
Chief: | Rahul Kumar | rahulkumar@berkeley.edu | 408-702-5845

Test Board name(s): | STAC Test Board v1
Board repo name in bwrcrepo.eecs.berkeley.edu “BWRC Boards” group | stac-pcb
Will there be more than 1 board design per panel? | no
Chip name: | STAC V1
Is the chip package a BGA? QFN? | QFN-64
Does the package have a corner mark? | Yes
Will a socket be used for the packaged die? Describe on a later page. | No
How many packaged die to be assembled onto the board? | 1
BGA ball or QFN pin pitch? | QFN (0.5mm)

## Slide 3

How many boards to be fabricated? | 8
Do you want mounted cross-sections of your board? | yes
Surface finish required? ENIG, etc.? | ENIG
Preferred board house: | Sierra
How many boards do you want stuffed? | 7
Preferred assembly house: | Digicom
Do you want the assembly house to buy the parts? | No, purchase ourselves
Do you want the assembly house to buy the pastemask stencil? | Yes
Do you need a pastemask stencil for the BWRC custom jig? | No
Do you need any mechanical fixtures designed/machined? | No
Will you need to fit your test board on a probe station’s platen? | No

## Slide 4

What dielectric laminate do you want for your board? | Rogers RO4350B on top, other layers FR4
Do you have edge-launch SMAs? What size fixed wrench? | Yes, 3/8”
Do you want the assembly house to use SMA heat sinks? | Yes
Do you have controlled impedance traces? SE? Diff pairs? | Yes, single-ended
Do you require vias-in-pads? | No
How many power domains? Please list: | 2 supplies on chip (VDDD1V8, VDDIO3V3)
For testing, do you require test pads for active scope probes? | yes
Do you require test pads for scope probe springy loops? | yes
Do you want test loops for attaching passive probes? | Test loops for ohming resistance
Do you need coax connectors to measure noise on power domains? | Yes

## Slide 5

Please list/describe any other requirements for the test board:
Voltage Domains:
6V input
--> pass through power protection
-->pass through LDO (1st stage LDO, 4.66V output)
--> goes to 2 separate LDOs (2nd stage LDOs) , 1 for VDDD1V8, 1 for VDDIO3V3
Also have 2 points where we can bypass supplies directly to the chip (nets named *EXT*).
Switching controlled by jumper across two adjacent header pins.
No separate analog/digital supply voltages.

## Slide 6

Drawing of package: QFN-64 w/exposed pad, 9mm x 9mm, 0.5mm pitch

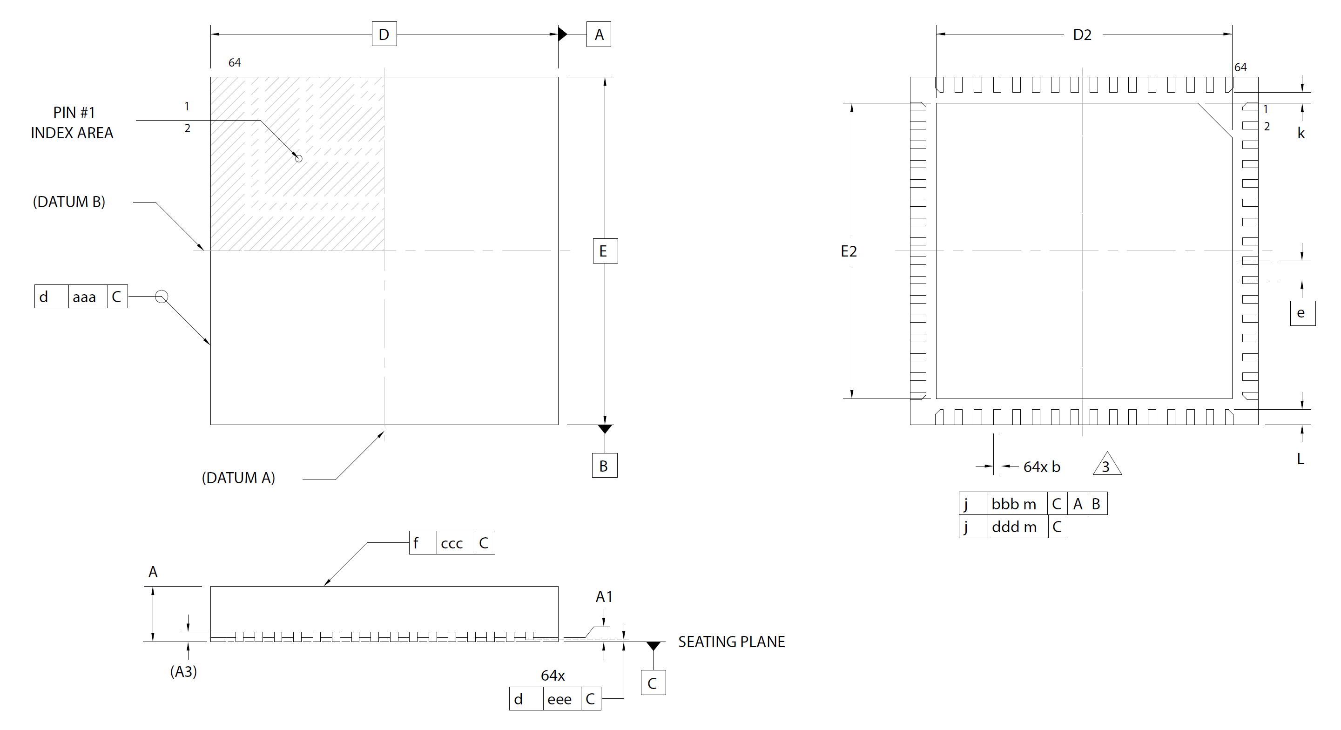
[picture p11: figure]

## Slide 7

Please paste a screenshot of the Altium schematic symbol you created for you die and saved to BWRC.SchLib:

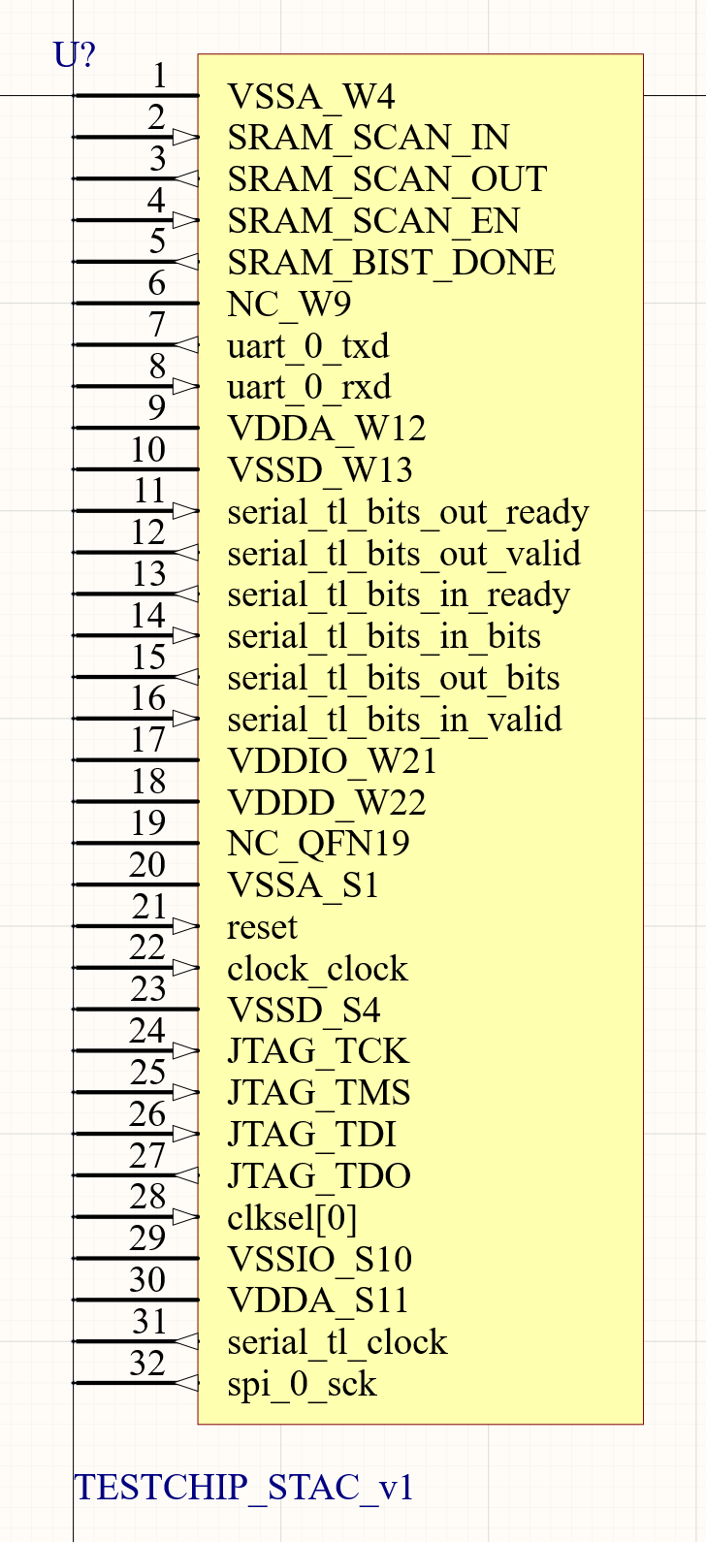
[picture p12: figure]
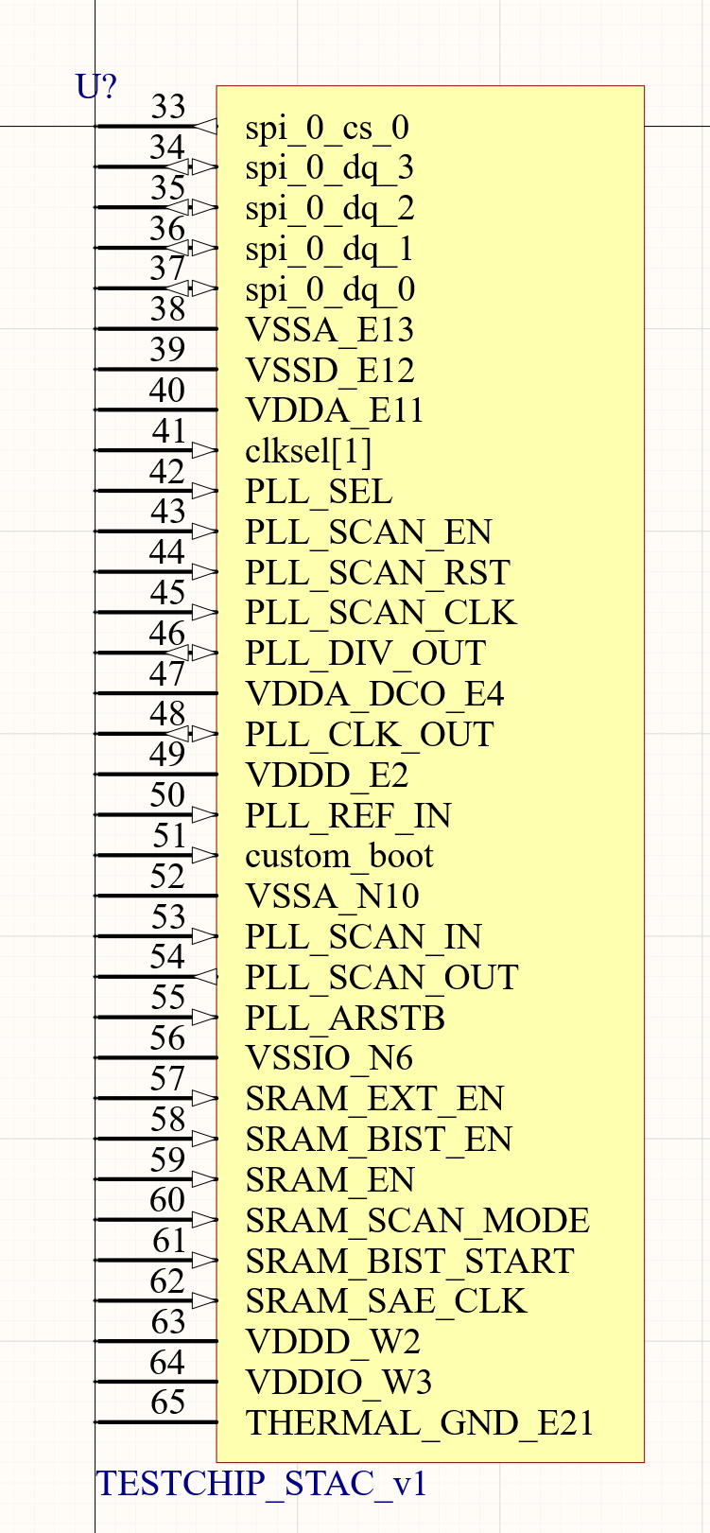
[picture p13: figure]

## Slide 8

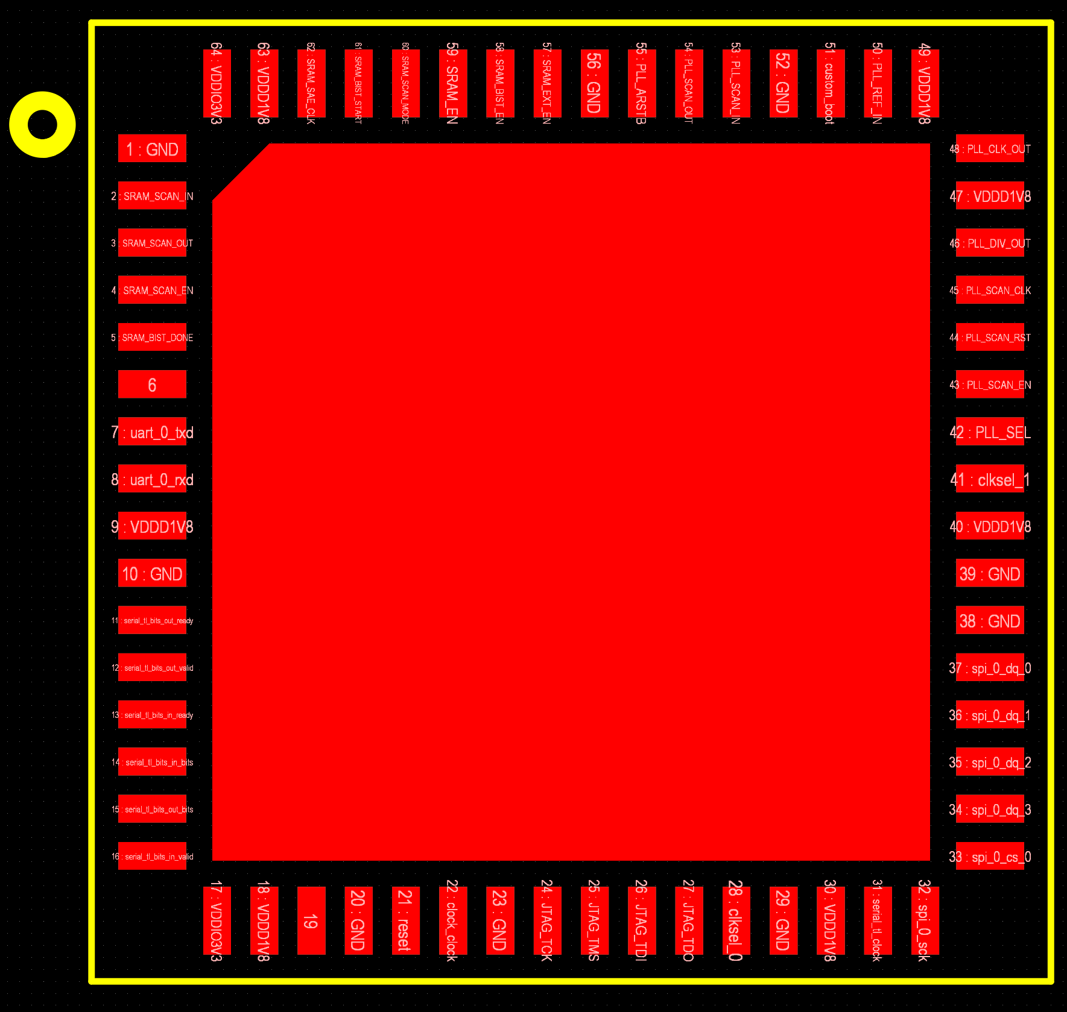
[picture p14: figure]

Pin 1

SRAM

PLL

Digital

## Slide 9

Physical constraints:

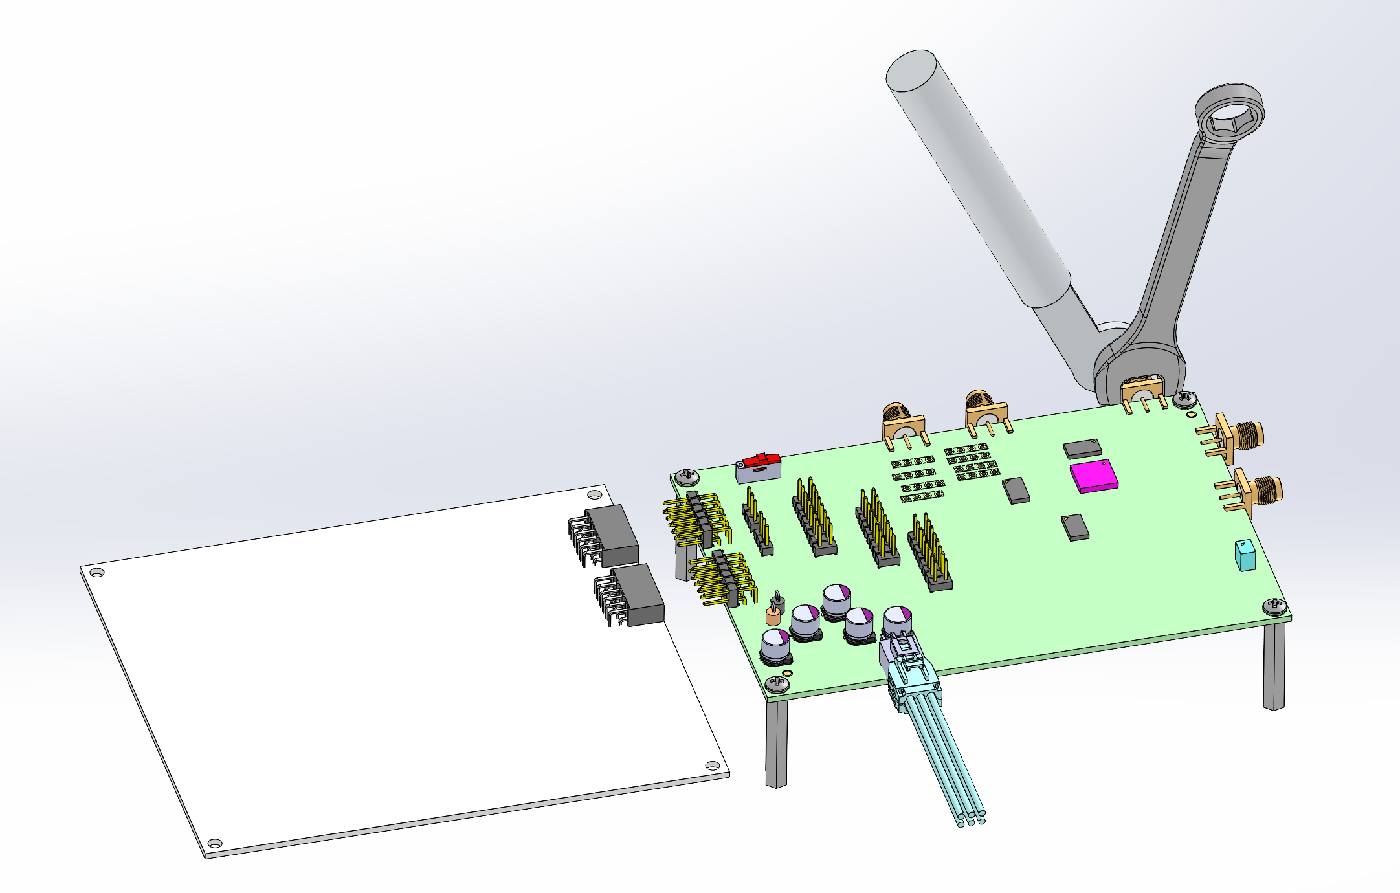
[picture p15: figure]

All controlled impedance traces can route on the top layer.

Main physical constraint: Have 2 PMOD headers (6x2 pins each) with a center-to-center pitch of 0.9”. These must be on one edge of the board and will directly plug in to an Arty A7-100T FPGA. First PMOD header is 9/16” from the Arty top edge.

Also have several SMA connectors.

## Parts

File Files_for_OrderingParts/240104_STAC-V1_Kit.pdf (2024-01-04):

Kit List: ASMPCB-STAC-V1 | Printed : 1/4/2024 10:48:41 AM

# ASMPCB-STAC-V1

ASMPCB-STAC-V1

Quantity to Build: | 7
Part List Revision: Kit Release Date: | A
| 12/15/2023
C:\Users\Rahul Kumar\Documents\work\partsync\BWRC.mdb | Kit Release Number: | 002
Item | Qty | Part Number | Description | Reference
Vendor Name | Vendor Part Number | Manf Name | Manf Part Number
Loc | Sort Code
300 | BW-663-053 | Cap ceramic 0.1uF 16V 5% X7R 0603 Kemet C0603C104J4RACTU

C4 C23 C24 C25 C26 C27 C28 C29 C32 C34 C44 C45 C46
CAPC-0603 0.1uF 16V D3 | C47 C48 C49 C50 C51 C52
Digi-Key 399-C0603C104J4RAC7867TR-ND | Kemet C0603C104J4RACTU

1

100 | BW-367-353 | Cap ceramic 0.47uF 10V 10% X7R 0603 Yageo CC0603KRX7R6BB474

C11 C14

| CAPC-0603 0.47uF 10V R5
| Digi-Key 311-1798-1-ND | Yageo CC0603KRX7R6BB474

2

100 | BW-183-150 | Cap ceramic 3.3uF 10V 10% X5R 0603 Samsung CL10A335KP8NNNC

C36

| CAPC-0603 3.3uF 10V H8
| Digi-Key 1276-1892-1-ND | Samsung CL10A335KP8NNNC

3

100 | BW-171-235 | Cap ceramic 4.7uF 35V 10% X5R 0603 Murata GRM188R6YA75KE15D

C9 C10 C12 C13 C31 C33

| CAPC-0603 4.7uF 35V L2
| Digi-Key 490-7205-1-ND | Murata GRM188R6YA75KE15D

4

140 | BW-224-068 | Cap ceramic 10uF 25V 20% X5R 0603 Murata GRM188R61E106MA73D

C1 C3 C15 C16 C17 C18 C19
C20 C21 C22 C30 C35 C37
CAPC-0603 10uF 25V U8 | C38 C39 C40 C41 C42 C43
| Digi-Key 490-7202-1-ND | Murata GRM188R61E106MA73D

5

35 | BW-998-821 | Cap aluminum polymer 220uF 16V 20% SMD, 6.3mm dia. Panasonic 16SVPK220M

C2 C5 C6 C7 C8

CAPE-AL-GP 220uF 16V W1

| Digi-Key P124158CT-ND | Panasonic 16SVPK220M

6

14 | BW-038-636 | Con 2 pin 100 mil pitch 1x2 TSW str male thru 0.230" post height Samtec TSW-102-07-G-S

J19 J23

| CON-100 TSW 2 A5
| Digi-Key SAM1029-02-ND | Samtec TSW-102-07-G-S

7

21 | BW-517-054 | Con 3 pin 100 mil pitch 1x3 TSW str male thru 0.230" post height Samtec TSW-103-07-G-S

J2 J3 J18

| CON-100 TSW 3 K6
| Digi-Key SAM1029-03-ND | Samtec TSW-103-07-G-S

8

7 | BW-491-171 | Con 4 pin 100 mil pitch 1x4 TSW str male thru 0.230" post height Samtec TSW-104-07-G-S

J7

| CON-100 TSW 4 K5
| Digi-Key SAM1029-04-ND | Samtec TSW-104-07-G-S

9

21 | BW-623-913 | Con 8 pin 100 mil pitch 2x4 TSW str male thru 0.230" post height Samtec TSW-104-07-L-D

J20 J21 J22

| CON-100 TSW 8 V2
| Digi-Key SAM1030-04-ND | Samtec TSW-104-07-L-D

10

21 | BW-220-198 | Con 12 pin 100 mil pitch 2x6 TSW RA male thru 0.230" post height Samtec TSW-106-08-L-D-RA J4 J8 J10
| CON-100 TSW 12 F3
| Digi-Key SAM1041-06-ND | Samtec TSW-106-08-L-D-RA

11

My Company www.myurl.com
123 Main Street MyTown MyState MyCntry 123-456-7890

ASMPCB-STAC-V1

Item | Qty | Part Number | Description | Reference
Vendor Name | Vendor Part Number | Manf Name | Manf Part Number
Loc | Sort Code
7 | BW-137-712 | Con 12 pin 100 mil pitch 2x6 SSW socket female thru 0.230" post height Samtec SSW-106-01-G-D J14
| CON-100 SSW 12 E6
| Digi-Key SAM1208-06-ND | Samtec SSW-106-01-G-D

12

7 | BW-510-530 | Con 16 pin 100 mil pitch 2x8 TSW str male thru Samtec TSW-108-07-L-D

J12

| CON-100 TSW 16 T5
| Digi-Key SAM1030-08-ND | Samtec TSW-108-07-L-D

13

7 | BW-350-204 | Con 6 pin 2.5mm pitch 2x3 Nano Fit RA male thru shrouded Molex 1053141106

J1

| CON-2.5MM Nano Fit 6 H7
| Digi-Key WM16908-ND | Molex 1053141106

14

49 | BW-867-891 | Con SMA female jack end launch 50 ohm 18GHz PCB long pin (f/62mil board) Cinch 142-0701-801 J5 J6 J9 J11 J13 J15 J16
| CON-RF SMA edge mnt D4
| Digi-Key J502-ND | Cinch 142-0701-801

15

7 | BW-536-719 | Con USB-C 2.0 recp R/A SMT Amphenol 12402012E212A

J17

| CON-USB C R1
Digi-Key 664-12402012E212ACT-ND | Amphenol Comme 12402012E212A

16

7 | BW-479-949 | Osc 12MHz with capacitors 3-pin Murata CSTNE12M0GH5L000R0

X1

| CRY-OSC 12MHz J3
| Digi-Key 490-17947-1-ND | Murata CSTNE12M0GH5L000R0

17

7 | BW-023-157 | IC custom STAC-V1 die 64 pins 0.5mm pitch QFN-64 w/EP BWRC

U6

### 18 DIE-CUSTOM STAC-V1 D1

100 | BW-633-217 | Fuse PTC reset 6V 1.5A 1206 Eaton PTSLR12066V150

F1

| FUSE 1.5A M7
Digi-Key 283-PTSLR12066V150CT-ND | Eaton PTSLR12066V150

19

7 | BW-674-698 | IC TS3A27518EPWR 6-ch analog mux TSSOP-24 TI TS3A27518EPWR

U9

| IC TS3A27518EPWR U7
| Digi-Key 296-24570-1-ND | Texas Instrume TS3A27518EPWR

20

7 | BW-250-920 | IC IS25LP128-JBLE 128Mbit QSPI flash SOIC-8 ISSI IS25LP128-JBLE

U10

| IC IS25LP128-JBLE K2
| Digi-Key 706-1341-ND | ISSI IS25LP128-JBLE

21

7 | BW-913-765 | IC 93LC56BT-I/OT 2K I2C EEPROM SOT23-6 Microchip 93LC56BT-I/OT

U8

| IC 93LC56BT-I/OT B2
Digi-Key 93LC56BT-I/OTCT-ND | Microchip 93LC56BT-I/OT

22

7 | BW-157-496 | IC FT2232HL USB to UART/FIFO LQFP-64 FTDI FT2232HL

U7

| IC FT2232HL M3
| Digi-Key 768-1024-1-ND | FTDI FT2232HL-REEL

23

14 | BW-746-991 | IC LT3042 adj LDO regulator 200mA MSOP-EP-10 Analog Devices LT3042IMSE#TRPBF

U3 U5

| IC LT3042 U8
Digi-Key LT3042IMSE#TRPBFCT-ND | Analog Devices LT3042IMSE#TRPBF

24

My Company www.myurl.com
ASMPCB-STAC-V1

Vendor Name | Vendor Part Number | Manf Name | Manf Part Number
Loc | Sort Code
7 | BW-849-997 | IC LT3083 LDO regulator 3A TAB pkg Analog Devices LT3083EQ#PBF

U1

| IC LT3083 D7
Digi-Key 505-LT3083EQ#PBF-ND | Analog Devices LT3083EQ#PBF

25

7 | BW-843-693 | IC LTC4365CTS8#TRMPBF Analog Devices LTC4365 Surge Surpressor

U4

IC LTC4365CTS8#TRMPBF H7

Digi-Key 505-LTC4365CTS8#TRMPBFCT-ND Analog Devices LTC4365CTS8#TRMPBF

26

7 | BW-818-101 | IC APS6404L-3SQR-SN PseudoSRAM PSRAM 8Mx8bits SPI/QSPI SOP-8 AP Memory APS6404L-3SQR-SN U11
| IC APS6404L-3SQR-SN G4
Mouser 878-APS6404L-3SQR-SN | AP Memory APS6404L-3SQR-SN

27

100 | BW-227-124 | Inductor 1uH 3.3A shielded 1008 pkg Murata DFE252012F-1R0M=P2

L1 L2

| IND-1008 1uH 3.3A K4
| Digi-Key 490-13053-1-ND | Murata DFE252012F-1R0M=P2

28

100 | BW-885-747 | LED 470nm (blue) 2.65V 2mA 0603 SMT Kingbright APT1608LVBC/D

D3 D5 D6

| LED blue P4
| Digi-Key 754-1933-1-ND | Kingbright APT1608LVBC/D

29

100 | BW-747-432 | LED 565nm (green) 2.2V 0603 surface-mount Lumex SML-LX0603GW-TR

D1 D2 D8

| LED green R5
| Digi-Key 67-1549-1-ND | Lumex SML-LX0603GW-TR

30

100 | BW-219-501 | LED 660nm (red) 1.7V 0603 SMT VCC 7017X1

D4

| LED red N8
| Digi-Key 7017X1CT-ND | VCC 7017X1

31

100 | BW-087-782 | LED 631nm (red) 2V 5mA 0603 SMT Lite-On LTST-C193KRKT-5A

D7

| LED red B8
| Digi-Key 160-1830-1-ND | Liteon LTST-C193KRKT-5A

32

7 | BW-471-924 | MOSFET N-CH dual 60V 35A SOT-1205 Nexperia BUK9K12-60EX

U2

| Q-NMOS BUK9K12-60EX J7
| Digi-Key 1727-1897-1-ND | Nexperia BUK9K12-60EX

33

100 | BW-528-389 | Res 12K 0.5% 1/10W 0603 Panasonic

R30

| R.5%-0603 12K D5
| Digi-Key P123739CT-ND | Panasonic ERA-3AED123V

34

100 | BW-708-683 | Res 10 1% 1/10W 0603 Stackpole RMCF0603FT10R0

R20 R21

| R1%-0603 10 C6
Digi-Key RMCF0603FT10R0CT-ND | Stackpole RMCF0603FT10R0

35

100 | BW-146-387 | Res 75 1% 1/10W 0603 Stackpole RMCF0603FT75R0

R15

| R1%-0603 75 V7
Digi-Key RMCF0603FT75R0CT-ND | Stackpole RMCF0603FT75R0

36

100 | BW-784-622 | Res 250 0.1% 1/10W 0603 Yageo RT0603BRE07250RL

R12 R28

| R1%-0603 250 K1
Digi-Key 13-RT0603BRE07250RLCT-ND | Yageo RT0603BRE07250RL

37

My Company www.myurl.com
ASMPCB-STAC-V1

Vendor Name | Vendor Part Number | Manf Name | Manf Part Number
Loc | Sort Code
100 | BW-354-763 | Res 301 1% 1/10W 0603 Panasonic ERA-3AEB3010V

R8 R11 R16

| R1%-0603 301 T8
| Digi-Key P301DBCT-ND | Panasonic ERA-3AEB3010V

38

100 | BW-457-217 | Res 330 1% 1/10W 0603 Panasonic ERJ-U03F3300V

R14 R18 R19 R22

| R1%-0603 330 R3
Digi-Key 10-ERJ-U03F3300VCT-ND | Panasonic ERJ-U03F3300V

39

100 | BW-812-714 | Res 909 1% 1/10W 0603 Panasonic ERJ-3EKF9090V

R1

| R1%-0603 909 E3
| Digi-Key P909HCT-ND | Panasonic ERJ-3EKF9090V

40

100 | BW-005-683 | Res 2.2K 1% 1/10W 0603 Yageo RC0603FR-132K2L

R33

| R1%-0603 2.2K P4
Digi-Key 13-RC0603FR-132K2LCT-ND | Yageo RC0603FR-132K2L

41

100 | BW-725-833 | Res 4.7K 1% 1/10W 0603 Panasonic ERJ-3EKF4701V

R26

| R1%-0603 4.7K W1
| Digi-Key P4.70KHCT-ND | Panasonic ERJ-3EKF4701V

42

126 | BW-200-113 | Res 5.1K 1% 1/10W 0603 Panasonic ERJ-3EKF5101V

R23 R24 R34 R35 R36 R37 R38 R39 R40 R41 R42 R43 R44 R45
R1%-0603 5.1K B6 | R46 R47 R48 R49
| Digi-Key P5.10KHCT-ND | Panasonic ERJ-3EKF5101V

43

100 | BW-038-468 | Res 10K 1% 1/10W 0603 Yageo RC0603FR-0710KL

R27 R29 R31 R32

| R1%-0603 10K C1
Digi-Key 311-10.0KHRCT-ND | Yageo RC0603FR-0710KL

44

100 | BW-446-612 | Res 15K 1% 1/10W 0603 Panasonic

R6

| R1%-0603 15K P8
| Digi-Key P15.0KHCT-ND | Panasonic ERJ-3EKF1502V

45

100 | BW-628-791 | Res 33.2K 1% 1/10W 0603 Panasonic ERJ-3EKF3322V

R13

| R1%-0603 33.2K R6
| Digi-Key P33.2KHCT-ND | Panasonic ERJ-3EKF3322V

46

100 | BW-131-959 | Res 82.5K 1% 1/10W 0603 Panasonic ERJ-3EKF8252V

R7

| R1%-0603 82.5K H6
| Digi-Key P82.5KHCT-ND | Panasonic ERJ-3EKF8252V

47

100 | BW-303-795 | Res 100K 1% 1/10W 0603 Panasonic ERJ-3EKF1003V

R2

| R1%-0603 100K N3
| Digi-Key P100KHCT-ND | Panasonic ERJ-3EKF1003V

48

100 | BW-760-287 | Res 200K 1% 1/10W 0603 Panasonic ERJ-3EKF2003V

R3

| R1%-0603 200K M2
| Digi-Key P200KHCT-ND | Panasonic ERJ-3EKF2003V

49

100 | BW-560-201 | Res 215K 1% 1/10W 0603 Panasonic ERJ-3EKF2153V

R10

| R1%-0603 215K K4
| Digi-Key P215KHCT-ND | Panasonic ERJ-3EKF2153V

50

My Company www.myurl.com
ASMPCB-STAC-V1

Vendor Name | Vendor Part Number | Manf Name | Manf Part Number
Loc | Sort Code
100 | BW-514-032 | Res 510K 1% 1/10W 0603 Panasonic ERJ-3EKF5103V

R4

| R1%-0603 510K N6
| Digi-Key P510KHCT-ND | Panasonic ERJ-3EKF5103V

51

100 | BW-421-162 | Res 2.7M 5% 1/10W 0603 Panasonic ERJ-3GEYJ275V

R5

| R5%-0603 2.7M C5
| Digi-Key P2.7MGCT-ND | Panasonic ERJ-3GEYJ275V

52

100 | BW-532-263 | Res 0 1/10W 0603 Panasonic ERJ-3GEY0R00V

R17

| RES 0 L1
Digi-Key P0.0GCT-ND | Panasonic ERJ-3GEY0R00V

53

7 | BW-257-784 | Res var trimmer pot 5K 1/4W 3-pin SMT Bourns 3214X-1-502E

R9

| RVAR 5K R3
Digi-Key 3214X-1-502ECT-ND | Bourns 3214X-1-502E

54

14 | BW-522-992 | Switch slide SPDT 3A 125V ST thru NKK CS12ANW03

S1 S2

| SW SPDT H6
| Digi-Key 360-2131-ND | NKK CS12ANW03

55

7 | BW-431-238 | Switch slide SPDT ST thru Wurth 450301014042

S3

| SW SPDT U7
| Digi-Key 450301014042-ND | Wurth 450301014042

56

21 | BW-591-967 | Switch momentary SPST-NO tactile 2 pin J-lead low-profile 2.5mm SMT C&K PTS636 SK25J SMTR LFS S4 S6 S7
| SW SPST-NO A6
| Digi-Key CKN12326-1-ND | C&K PTS636 SK25J SMTR LFS

57

7 | BW-977-175 | Switch DIP 6 position, 12 pin, SMT Wurth 418121270806

S5

| SW DIP-6 N2
| Digi-Key 732-6964-1-ND | Wurth 418121270806

58

100 | BW-697-885 | Diode TVS 24VWM 150VC 0603 Littelfuse PGB1010603MR

E1 E2

TASIL-BI PGB1010603MR K7

| Digi-Key F2594CT-ND | Littlefuse PGB1010603MR

59

7 | BW-602-053 | Test point loop 63mil dia hole orange Keystone 5008

T4

| TEST-PT 1 E6
| Digi-Key 36-5008-ND | Keystone 5008

60

7 | BW-966-768 | Test point loop 63mil dia hole black Keystone 5006

T10

| TEST-PT 1 M8
| Digi-Key 36-5006-ND | Keystone 5006

61

14 | BW-067-710 | Test point loop 63mil dia hole yellow Keystone 5009

T12 T13

| TEST-PT 1 V7
| Digi-Key 36-5009-ND | Keystone 5009

62

My Company www.myurl.com
ASMPCB-STAC-V1

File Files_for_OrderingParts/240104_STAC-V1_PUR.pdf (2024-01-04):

Purchase List: ASMPCB-STAC-V1 | Printed : 1/4/2024 10:48:27 AM

# ASMPCB-STAC-V1

ASMPCB-STAC-V1

Quantity to Build: | 7
Part List Revision: List Release Date: | A
| 12/15/2023
C:\Users\Rahul Kumar\Documents\work\partsync\BWRC.mdb | Purchase List Number: | 002
Item | Qty | Part Number | Description | Reference
Vendor Name | Vendor Part Number | Manf Name | Manf Part Number
Loc | Sort Code
1 | 7 | BW-023-157 | IC custom STAC-V1 die 64 pins 0.5mm pitch QFN-64 w/EP BWRC

U6

| | DIE-CUSTOM STAC-V1
| | None

*C2

2 | 300 | BW-663-053 | Cap ceramic 0.1uF 16V 5% X7R 0603 Kemet C0603C104J4RACTU

C4 C23 C24 C25 C26 C27 C28 C29 C32 C34 C44 C45 C46
C47 C48 C49 C50 C51 C52 CAPC-0603 0.1uF 16V
Digi-Key 399-C0603C104J4RAC7867TR-ND | Kemet C0603C104J4RACTU

*A1

3 | 100 | BW-367-353 | Cap ceramic 0.47uF 10V 10% X7R 0603 Yageo CC0603KRX7R6BB474

C11 C14

| | CAPC-0603 0.47uF 10V
| | Digi-Key 311-1798-1-ND | Yageo CC0603KRX7R6BB474

*A2

4 | 100 | BW-183-150 | Cap ceramic 3.3uF 10V 10% X5R 0603 Samsung CL10A335KP8NNNC

C36

| | CAPC-0603 3.3uF 10V
| | Digi-Key 1276-1892-1-ND | Samsung CL10A335KP8NNNC

*A3

5 | 100 | BW-171-235 | Cap ceramic 4.7uF 35V 10% X5R 0603 Murata GRM188R6YA75KE15D

C9 C10 C12 C13 C31 C33

| | CAPC-0603 4.7uF 35V
| | Digi-Key 490-7205-1-ND | Murata GRM188R6YA75KE15D

*A4

6 | 140 | BW-224-068 | Cap ceramic 10uF 25V 20% X5R 0603 Murata GRM188R61E106MA73D

C1 C3 C15 C16 C17 C18 C19
C20 C21 C22 C30 C35 C37
C38 C39 C40 C41 C42 C43 CAPC-0603 10uF 25V
| | Digi-Key 490-7202-1-ND | Murata GRM188R61E106MA73D

*A5

7 | 35 | BW-998-821 | Cap aluminum polymer 220uF 16V 20% SMD, 6.3mm dia. Panasonic 16SVPK220M

C2 C5 C6 C7 C8

| | CAPE-AL-GP 220uF 16V
| | Digi-Key P124158CT-ND | Panasonic 16SVPK220M

*A6

My Company www.myurl.com
123 Main Street MyTown MyState MyCntry 123-456-7890

### ASMPCB-STAC-V1

Item | Qty | Part Number | Description | Reference
Vendor Name | Vendor Part Number | Manf Name | Manf Part Number
| Loc | Sort Code
8 | 14 | BW-038-636 | Con 2 pin 100 mil pitch 1x2 TSW str male thru 0.230" post height Samtec TSW-102-07-G-S

J19 J23

| | CON-100 TSW 2
| | Digi-Key SAM1029-02-ND | Samtec TSW-102-07-G-S

*A7

9 | 21 | BW-517-054 | Con 3 pin 100 mil pitch 1x3 TSW str male thru 0.230" post height Samtec TSW-103-07-G-S

J2 J3 J18

| | CON-100 TSW 3
| | Digi-Key SAM1029-03-ND | Samtec TSW-103-07-G-S

*A8

10 | 7 | BW-491-171 | Con 4 pin 100 mil pitch 1x4 TSW str male thru 0.230" post height Samtec TSW-104-07-G-S

J7

| | CON-100 TSW 4
| | Digi-Key SAM1029-04-ND | Samtec TSW-104-07-G-S

*B1

11 | 21 | BW-623-913 | Con 8 pin 100 mil pitch 2x4 TSW str male thru 0.230" post height Samtec TSW-104-07-L-D

J20 J21 J22

| | CON-100 TSW 8
| | Digi-Key SAM1030-04-ND | Samtec TSW-104-07-L-D

*B2

12 | 21 | BW-220-198 | Con 12 pin 100 mil pitch 2x6 TSW RA male thru 0.230" post height Samtec TSW-106-08-L-D-RA J4 J8 J10
| | CON-100 TSW 12
| | Digi-Key SAM1041-06-ND | Samtec TSW-106-08-L-D-RA

*B3

13 | 7 | BW-137-712 | Con 12 pin 100 mil pitch 2x6 SSW socket female thru 0.230" post height Samtec SSW-106-01-G-D J14
| | CON-100 SSW 12
| | Digi-Key SAM1208-06-ND | Samtec SSW-106-01-G-D

*B4

14 | 7 | BW-510-530 | Con 16 pin 100 mil pitch 2x8 TSW str male thru Samtec TSW-108-07-L-D

J12

| | CON-100 TSW 16
| | Digi-Key SAM1030-08-ND | Samtec TSW-108-07-L-D

*B5

My Company www.myurl.com

### ASMPCB-STAC-V1

Vendor Name | Vendor Part Number | Manf Name | Manf Part Number
Loc | Sort Code
15 | 7 | BW-350-204 | Con 6 pin 2.5mm pitch 2x3 Nano Fit RA male thru shrouded Molex 1053141106

J1

| | CON-2.5MM Nano Fit 6
| | Digi-Key WM16908-ND | Molex 1053141106

*B6

16 | 49 | BW-867-891 | Con SMA female jack end launch 50 ohm 18GHz PCB long pin (f/62mil board) Cinch 142-0701-801 J5 J6 J9 J11 J13 J15 J16
| | CON-RF SMA edge mnt
| | Digi-Key J502-ND | Cinch 142-0701-801

*B7

17 | 7 | BW-536-719 | Con USB-C 2.0 recp R/A SMT Amphenol 12402012E212A

J17

| | CON-USB C
Digi-Key 664-12402012E212ACT-ND | Amphenol Comme 12402012E212A

*B8

18 | 7 | BW-479-949 | Osc 12MHz with capacitors 3-pin Murata CSTNE12M0GH5L000R0

X1

| | CRY-OSC 12MHz
| | Digi-Key 490-17947-1-ND | Murata CSTNE12M0GH5L000R0

*C1

19 | 100 | BW-633-217 | Fuse PTC reset 6V 1.5A 1206 Eaton PTSLR12066V150

F1

| | FUSE 1.5A
Digi-Key 283-PTSLR12066V150CT-ND | Eaton PTSLR12066V150

*C3

20 | 7 | BW-674-698 | IC TS3A27518EPWR 6-ch analog mux TSSOP-24 TI TS3A27518EPWR

U9

| | IC TS3A27518EPWR
| | Digi-Key 296-24570-1-ND | Texas Instrume TS3A27518EPWR

*C4

21 | 7 | BW-250-920 | IC IS25LP128-JBLE 128Mbit QSPI flash SOIC-8 ISSI IS25LP128-JBLE

U10

| | IC IS25LP128-JBLE
| | Digi-Key 706-1341-ND | ISSI IS25LP128-JBLE

*C5

My Company www.myurl.com

### ASMPCB-STAC-V1

Vendor Name | Vendor Part Number | Manf Name | Manf Part Number
Loc | Sort Code
22 | 7 | BW-913-765 | IC 93LC56BT-I/OT 2K I2C EEPROM SOT23-6 Microchip 93LC56BT-I/OT

U8

| | IC 93LC56BT-I/OT
Digi-Key 93LC56BT-I/OTCT-ND | Microchip 93LC56BT-I/OT

*C6

23 | 7 | BW-157-496 | IC FT2232HL USB to UART/FIFO LQFP-64 FTDI FT2232HL

U7

| | IC FT2232HL
| | Digi-Key 768-1024-1-ND | FTDI FT2232HL-REEL

*C7

24 | 14 | BW-746-991 | IC LT3042 adj LDO regulator 200mA MSOP-EP-10 Analog Devices LT3042IMSE#TRPBF

U3 U5

| | IC LT3042
Digi-Key LT3042IMSE#TRPBFCT-ND | Analog Devices LT3042IMSE#TRPBF

*C8

25 | 7 | BW-849-997 | IC LT3083 LDO regulator 3A TAB pkg Analog Devices LT3083EQ#PBF

U1

| | IC LT3083
Digi-Key 505-LT3083EQ#PBF-ND | Analog Devices LT3083EQ#PBF

*D1

26 | 7 | BW-843-693 | IC LTC4365CTS8#TRMPBF Analog Devices LTC4365 Surge Surpressor

U4

| | IC LTC4365CTS8#TRMPBF
Digi-Key 505-LTC4365CTS8#TRMPBFCT-ND | Analog Devices LTC4365CTS8#TRMPBF

*D2

27 | 100 | BW-227-124 | Inductor 1uH 3.3A shielded 1008 pkg Murata DFE252012F-1R0M=P2

L1 L2

| | IND-1008 1uH 3.3A
| | Digi-Key 490-13053-1-ND | Murata DFE252012F-1R0M=P2

*D4

28 | 100 | BW-885-747 | LED 470nm (blue) 2.65V 2mA 0603 SMT Kingbright APT1608LVBC/D

D3 D5 D6

| | LED blue
| | Digi-Key 754-1933-1-ND | Kingbright APT1608LVBC/D

*D5

My Company www.myurl.com

### ASMPCB-STAC-V1

Vendor Name | Vendor Part Number | Manf Name | Manf Part Number
| Loc | Sort Code
29 | 100 | BW-747-432 | LED 565nm (green) 2.2V 0603 surface-mount Lumex SML-LX0603GW-TR

D1 D2 D8

| | LED green
| | Digi-Key 67-1549-1-ND | Lumex SML-LX0603GW-TR

*D6

30 | 100 | BW-219-501 | LED 660nm (red) 1.7V 0603 SMT VCC 7017X1

D4

| | LED red
| | Digi-Key 7017X1CT-ND | VCC 7017X1

*D7

31 | 100 | BW-087-782 | LED 631nm (red) 2V 5mA 0603 SMT Lite-On LTST-C193KRKT-5A

D7

| | LED red
| | Digi-Key 160-1830-1-ND | Liteon LTST-C193KRKT-5A

*D8

32 | 7 | BW-471-924 | MOSFET N-CH dual 60V 35A SOT-1205 Nexperia BUK9K12-60EX

U2

| | Q-NMOS BUK9K12-60EX
| | Digi-Key 1727-1897-1-ND | Nexperia BUK9K12-60EX

*E1

33 | 100 | BW-528-389 | Res 12K 0.5% 1/10W 0603 Panasonic

R30

| | R.5%-0603 12K
| | Digi-Key P123739CT-ND | Panasonic ERA-3AED123V

*E2

34 | 100 | BW-708-683 | Res 10 1% 1/10W 0603 Stackpole RMCF0603FT10R0

R20 R21

| | R1%-0603 10
Digi-Key RMCF0603FT10R0CT-ND | Stackpole RMCF0603FT10R0

*E3

35 | 100 | BW-146-387 | Res 75 1% 1/10W 0603 Stackpole RMCF0603FT75R0

R15

| | R1%-0603 75
Digi-Key RMCF0603FT75R0CT-ND | Stackpole RMCF0603FT75R0

*E4

My Company www.myurl.com

### ASMPCB-STAC-V1

Vendor Name | Vendor Part Number | Manf Name | Manf Part Number
| Loc | Sort Code
36 | 100 | BW-784-622 | Res 250 0.1% 1/10W 0603 Yageo RT0603BRE07250RL

R12 R28

| | R1%-0603 250
Digi-Key 13-RT0603BRE07250RLCT-ND | Yageo RT0603BRE07250RL

*E5

37 | 100 | BW-354-763 | Res 301 1% 1/10W 0603 Panasonic ERA-3AEB3010V

R8 R11 R16

| | R1%-0603 301
| | Digi-Key P301DBCT-ND | Panasonic ERA-3AEB3010V

*E6

38 | 100 | BW-457-217 | Res 330 1% 1/10W 0603 Panasonic ERJ-U03F3300V

R14 R18 R19 R22

| | R1%-0603 330
Digi-Key 10-ERJ-U03F3300VCT-ND | Panasonic ERJ-U03F3300V

*E7

39 | 100 | BW-812-714 | Res 909 1% 1/10W 0603 Panasonic ERJ-3EKF9090V

R1

| | R1%-0603 909
| | Digi-Key P909HCT-ND | Panasonic ERJ-3EKF9090V

*E8

40 | 100 | BW-005-683 | Res 2.2K 1% 1/10W 0603 Yageo RC0603FR-132K2L

R33

| | R1%-0603 2.2K
Digi-Key 13-RC0603FR-132K2LCT-ND | Yageo RC0603FR-132K2L

*F1

41 | 100 | BW-725-833 | Res 4.7K 1% 1/10W 0603 Panasonic ERJ-3EKF4701V

R26

| | R1%-0603 4.7K
| | Digi-Key P4.70KHCT-ND | Panasonic ERJ-3EKF4701V

*F2

42 | 126 | BW-200-113 | Res 5.1K 1% 1/10W 0603 Panasonic ERJ-3EKF5101V

R23 R24 R34 R35 R36 R37 R38 R39 R40 R41 R42 R43 R44 R45 R46 R47 R48 R49 R1%-0603 5.1K

| | Digi-Key P5.10KHCT-ND | Panasonic ERJ-3EKF5101V

*F3

My Company www.myurl.com

### ASMPCB-STAC-V1

Vendor Name | Vendor Part Number | Manf Name | Manf Part Number
| Loc | Sort Code
43 | 100 | BW-038-468 | Res 10K 1% 1/10W 0603 Yageo RC0603FR-0710KL

R27 R29 R31 R32

| | R1%-0603 10K
Digi-Key 311-10.0KHRCT-ND | Yageo RC0603FR-0710KL

*F4

44 | 100 | BW-446-612 | Res 15K 1% 1/10W 0603 Panasonic

R6

| | R1%-0603 15K
| | Digi-Key P15.0KHCT-ND | Panasonic ERJ-3EKF1502V

*F5

45 | 100 | BW-628-791 | Res 33.2K 1% 1/10W 0603 Panasonic ERJ-3EKF3322V

R13

| | R1%-0603 33.2K
| | Digi-Key P33.2KHCT-ND | Panasonic ERJ-3EKF3322V

*F6

46 | 100 | BW-131-959 | Res 82.5K 1% 1/10W 0603 Panasonic ERJ-3EKF8252V

R7

| | R1%-0603 82.5K
| | Digi-Key P82.5KHCT-ND | Panasonic ERJ-3EKF8252V

*F7

47 | 100 | BW-303-795 | Res 100K 1% 1/10W 0603 Panasonic ERJ-3EKF1003V

R2

| | R1%-0603 100K
| | Digi-Key P100KHCT-ND | Panasonic ERJ-3EKF1003V

*F8

48 | 100 | BW-760-287 | Res 200K 1% 1/10W 0603 Panasonic ERJ-3EKF2003V

R3

| | R1%-0603 200K
| | Digi-Key P200KHCT-ND | Panasonic ERJ-3EKF2003V

*G1

49 | 100 | BW-560-201 | Res 215K 1% 1/10W 0603 Panasonic ERJ-3EKF2153V

R10

| | R1%-0603 215K
| | Digi-Key P215KHCT-ND | Panasonic ERJ-3EKF2153V

*G2

My Company www.myurl.com

### ASMPCB-STAC-V1

Vendor Name | Vendor Part Number | Manf Name | Manf Part Number
| Loc | Sort Code
50 | 100 | BW-514-032 | Res 510K 1% 1/10W 0603 Panasonic ERJ-3EKF5103V

R4

| | R1%-0603 510K
| | Digi-Key P510KHCT-ND | Panasonic ERJ-3EKF5103V

*G3

51 | 100 | BW-421-162 | Res 2.7M 5% 1/10W 0603 Panasonic ERJ-3GEYJ275V

R5

| | R5%-0603 2.7M
| | Digi-Key P2.7MGCT-ND | Panasonic ERJ-3GEYJ275V

*G4

52 | 100 | BW-532-263 | Res 0 1/10W 0603 Panasonic ERJ-3GEY0R00V

R17

| | RES 0
Digi-Key P0.0GCT-ND | Panasonic ERJ-3GEY0R00V

*G5

53 | 7 | BW-257-784 | Res var trimmer pot 5K 1/4W 3-pin SMT Bourns 3214X-1-502E

R9

| | RVAR 5K
Digi-Key 3214X-1-502ECT-ND | Bourns 3214X-1-502E

*G6

54 | 14 | BW-522-992 | Switch slide SPDT 3A 125V ST thru NKK CS12ANW03

S1 S2

| | SW SPDT
| | Digi-Key 360-2131-ND | NKK CS12ANW03

*G7

55 | 7 | BW-431-238 | Switch slide SPDT ST thru Wurth 450301014042

S3

| | SW SPDT
Digi-Key 450301014042-ND | Wurth 450301014042

*G8

56 | 21 | BW-591-967 | Switch momentary SPST-NO tactile 2 pin J-lead low-profile 2.5mm SMT C&K PTS636 SK25J SMTR LFS S4 S6 S7
| | SW SPST-NO
| | Digi-Key CKN12326-1-ND | C&K PTS636 SK25J SMTR LFS

*H1

My Company www.myurl.com

### ASMPCB-STAC-V1

Vendor Name | Vendor Part Number | Manf Name | Manf Part Number
Loc | Sort Code
57 | 7 | BW-977-175 | Switch DIP 6 position, 12 pin, SMT Wurth 418121270806

S5

| | SW DIP-6
| | Digi-Key 732-6964-1-ND | Wurth 418121270806

*H2

58 | 100 | BW-697-885 | Diode TVS 24VWM 150VC 0603 Littelfuse PGB1010603MR

E1 E2

| | TASIL-BI PGB1010603MR
| | Digi-Key F2594CT-ND | Littlefuse PGB1010603MR

*H3

59 | 7 | BW-602-053 | Test point loop 63mil dia hole orange Keystone 5008

T4

| | TEST-PT 1
| | Digi-Key 36-5008-ND | Keystone 5008

*H4

60 | 7 | BW-966-768 | Test point loop 63mil dia hole black Keystone 5006

T10

| | TEST-PT 1
| | Digi-Key 36-5006-ND | Keystone 5006

*H5

61 | 14 | BW-067-710 | Test point loop 63mil dia hole yellow Keystone 5009

T12 T13

| | TEST-PT 1
| | Digi-Key 36-5009-ND | Keystone 5009

*H6

62 | 7 | BW-818-101 | IC APS6404L-3SQR-SN PseudoSRAM PSRAM 8Mx8bits SPI/QSPI SOP-8 AP Memory APS6404L-3SQR-SN U11
| | IC APS6404L-3SQR-SN
Mouser 878-APS6404L-3SQR-SN | AP Memory APS6404L-3SQR-SN

*D3

My Company www.myurl.com

### ASMPCB-STAC-V1

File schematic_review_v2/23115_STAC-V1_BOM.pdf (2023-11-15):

BOM List: ASMPCB-STAC-V1 | Printed : 11/15/2023 8:37:50 AM

# ASMPCB-STAC-V1

ASMPCB-STAC-V1

Quantity to Build: | 1
Part List Revision: BOM Date: | A
| 11/15/2023

C:\Users\aflynn\data\PS_stuff\BWRC.mdb

Item | Qty | Part Number | Description | Reference
Vendor Name | Vendor Part Number | Manf Name | Manf Part Number
1 | 15 | BW-224-068 | Cap ceramic 10uF 25V 20% X5R 0603
Murata GRM188R61E106MA73D
| | | | C1 C3 C15 C16 C17 C18 C19 C20 C21 C22 C33 C34 C35

C36 C37

| | Digi-Key 490-7202-1-ND | Murata GRM188R61E106MA73D
2 | 5 | BW-998-821 | Cap aluminum polymer 220uF 16V 20% SMD, 6.3mm dia.
Panasonic 16SVPK220M
| | | | C2 C5 C6 C7 C8
| | Digi-Key P124158CT-ND | Panasonic 16SVPK220M
3 | 15 | BW-663-053 | Cap ceramic 0.1uF 16V 5% X7R 0603 Kemet C0603C104J4RACTU

C4 C25 C26 C27 C28 C29 C30 C31 C38 C39 C40 C41 C42
C43 C44
| | Digi-Key 399-1097-1-ND | Kemet C0603C104J4RACTU
4 | 6 | BW-171-235 | Cap ceramic 4.7uF 35V 10% X5R 0603 Murata GRM188R6YA75KE15D

C9 C10 C12 C13 C23 C24

| | Digi-Key 490-7205-1-ND | Murata GRM188R6YA75KE15D
5 | 2 | BW-367-353 | Cap ceramic 0.47uF 10V 10% X7R 0603 Yageo CC0603KRX7R6BB474

C11 C14

| | Digi-Key 311-1798-1-ND | Yageo CC0603KRX7R6BB474
6 | 1 | BW-183-150 | Cap ceramic 3.3uF 10V 10% X5R 0603 Samsung CL10A335KP8NNNC

C32

| | Digi-Key 1276-1892-1-ND | Samsung CL10A335KP8NNNC
7 | 1 | BW-747-432 | LED 565nm (green) 2.2V 0603 surface-mount Lumex SML-LX0603GW-TR

D1

| | Digi-Key 67-1549-1-ND | Lumex SML-LX0603GW-TR
8 | 2 | BW-885-747 | LED 470nm (blue) 2.65V 2mA 0603 SMT Kingbright APT1608LVBC/D

D2 D3

| | Digi-Key 754-1933-1-ND | Kingbright APT1608LVBC/D
9 | 1 | BW-087-782 | LED 631nm (red) 2V 5mA 0603 SMT Lite-On LTST-C193KRKT-5A

D4

| | Digi-Key 160-1830-1-ND | Liteon LTST-C193KRKT-5A
10 | 3 | BW-491-171 | Con 4 pin 100 mil pitch 1x4 TSW str male thru 0.230" post height Samtec TSW-104-07-G-S

J1 J3 J9

| | Digi-Key SAM1029-04-ND | Samtec TSW-104-07-G-S
11 | 1 | BW-350-204 | Con 6 pin 2.5mm pitch 2x3 Nano Fit RA male thru shrouded Molex 1053141106

J2

Digi-Key WM16908-ND | Molex 1053141106

ASMPCB-STAC-V1

Item | Qty | Part Number | Description | Reference
Vendor Name | Vendor Part Number | Manf Name | Manf Part Number
12 | 2 | BW-517-054 | Con 3 pin 100 mil pitch 1x3 TSW str male thru 0.230" post height
Samtec TSW-103-07-G-S

J4 J5

| | Digi-Key SAM1029-03-ND | Samtec TSW-103-07-G-S
13 | 3 | BW-220-198 | Con 12 pin 100 mil pitch 2x5 TSW RA male thru 0.230" post height Samtec TSW-106-08-L-D-RA J6 J10 J12
| | Digi-Key SAM1041-06-ND | Samtec TSW-106-08-L-D-RA
14 | 7 | BW-867-891 | Con SMA female jack end launch 50 ohm 18GHz PCB long pin (f/62mil board) Cinch 142-0701-801 J7 J8 J11 J13 J15 J17 J18
| | Digi-Key J502-ND | Cinch 142-0701-801
15 | 2 | BW-510-530 | Con 16 pin 100 mil pitch 2x8 TSW str male thru Samtec TSW-108-07-L-D

J14 J16

| | Digi-Key SAM1030-08-ND | Samtec TSW-108-07-L-D
16 | 1 | BW-536-719 | Con USB-C 2.0 recp R/A SMT Amphenol 12402012E212A

J19

Digi-Key 664-12402012E212ACT-ND | Amphenol Comme 12402012E212A
17 | 1 | BW-038-636 | Con 2 pin 100 mil pitch 1x2 TSW str male thru 0.230" post height Samtec TSW-102-07-G-S

J20

| | Digi-Key SAM1029-02-ND | Samtec TSW-102-07-G-S
18 | 1 | BW-812-714 | Res 909 1% 1/10W 0603 Panasonic ERJ-3EKF9090V

R1

| | Digi-Key P909HCT-ND | Panasonic ERJ-3EKF9090V
19 | 1 | BW-606-753 | Res 93.1K 1% 1/10W 0603 Panasonic ERJ-3EKF9312V

R2

| | Digi-Key P93.1KHCT-ND | Panasonic ERJ-3EKF9312V
20 | 1 | BW-760-287 | Res 200K 1% 1/10W 0603 Panasonic ERJ-3EKF2003V

R3

| | Digi-Key P200KHCT-ND | Panasonic ERJ-3EKF2003V
21 | 1 | BW-514-032 | Res 510K 1% 1/10W 0603 Panasonic ERJ-3EKF5103V

R4

| | Digi-Key P510KHCT-ND | Panasonic ERJ-3EKF5103V
22 | 1 | BW-421-162 | Res 2.7M 5% 1/10W 0603 Panasonic ERJ-3GEYJ275V

R5

| | Digi-Key P2.7MGCT-ND | Panasonic ERJ-3GEYJ275V
23 | 1 | BW-446-612 | Res 15K 1% 1/10W 0603 Panasonic

R6

| | Digi-Key P15.0KHCT-ND | Panasonic ERJ-3EKF1502V
24 | 1 | BW-131-959 | Res 82.5K 1% 1/10W 0603 Panasonic ERJ-3EKF8252V

R7

Digi-Key P82.5KHCT-ND | Panasonic ERJ-3EKF8252V

ASMPCB-STAC-V1

Vendor Name | Vendor Part Number | Manf Name | Manf Part Number
25 | 3 | BW-354-763 | Res 301 1% 1/10W 0603
Panasonic ERA-3AEB3010V

R8 R11 R13

| | Digi-Key P301DBCT-ND | Panasonic ERA-3AEB3010V
26 | 1 | BW-257-784 | Res var trimmer pot 5K 1/4W 3-pin SMT Bourns 3214X-1-502E

R9

Digi-Key 3214X-1-502ECT-ND | Bourns 3214X-1-502E
27 | 1 | BW-560-201 | Res 215K 1% 1/10W 0603 Panasonic ERJ-3EKF2153V

R10

| | Digi-Key P215KHCT-ND | Panasonic ERJ-3EKF2153V
28 | 1 | BW-628-791 | Res 33.2K 1% 1/10W 0603 Panasonic ERJ-3EKF3322V

R12

Digi-Key P33.2KHCT-ND | Panasonic ERJ-3EKF3322V
29 | 1 | BW-764-694 | Res 0 1/10W 0603 Yageo RC0603JR-070RL

R14

| | Digi-Key 311-0.0GRCT-ND | Yageo RC0603JR-070RL
30 | 3 | BW-796-398 | Res 330 5% 1/10W 0603 Panasonic ERJ-3GEYJ331V

R15 R16 R17

| | Digi-Key P330GCT-ND | Panasonic ERJ-3GEYJ331V
31 | 2 | BW-592-449 | Res 27 1% 1/10W 0603 Panasonic ERJ-3EKF27R0V

R18 R19

| | Digi-Key P27.0HCT-ND | Panasonic ERJ-3EKF27R0V
32 | 13 | BW-200-113 | Res 5.1K 1% 1/10W 0603 Panasonic ERJ-3EKF5101V

R20 R21 R27 R28 R29 R30 R32 R34 R36 R37 R38 R40 R41

| | Digi-Key P5.10KHCT-ND | Panasonic ERJ-3EKF5101V
33 | 7 | BW-038-468 | Res 10K 1% 1/10W 0603 Yageo RC0603FR-0710KL

R23 R24 R25 R31 R33 R35 R39

Digi-Key 311-10.0KHRCT-ND | Yageo RC0603FR-0710KL
34 | 1 | BW-528-389 | Res 12K 0.5% 1/10W 0603 Panasonic

R26

| | Digi-Key P123739CT-ND | Panasonic ERA-3AED123V
35 | 1 | BW-431-238 | Switch slide SPDT ST thru Wurth 450301014042

S1

| | Digi-Key 450301014042-ND | Wurth 450301014042
36 | 3 | BW-591-967 | Switch momentary SPST-NO tactile 2 pin J-lead low-profile 2.5mm SMT C&K PTS636 SK25J SMTR LFS S2 S4 S5
| | Digi-Key CKN12326-1-ND | C&K PTS636 SK25J SMTR LFS
37 | 1 | BW-020-728 | Switch DIP 4 position, 8 pin, SPST SMT Wurth 418121270804

S3

Digi-Key 732-6963-1-ND | Wurth 418121270804

ASMPCB-STAC-V1

Vendor Name | Vendor Part Number | Manf Name | Manf Part Number
38 | 1 | BW-602-053 | Test point loop 63mil dia hole orange
Keystone 5008

T4

| | Digi-Key 36-5008-ND | Keystone 5008
39 | 1 | BW-966-768 | Test point loop 63mil dia hole black Keystone 5006

T10

| | Digi-Key 36-5006-ND | Keystone 5006
40 | 2 | BW-067-710 | Test point loop 63mil dia hole yellow Keystone 5009

T11 T12

| | Digi-Key 36-5009-ND | Keystone 5009
41 | 1 | BW-849-997 | IC LT3083 LDO regulator 3A DDPAK-5 Analog Devices LT3083EQ#PBF

U1

Digi-Key 505-LT3083EQ#PBF-ND | Analog Devices LT3083EQ#PBF
42 | 1 | BW-471-924 | MOSFET N-CH dual 60V 35A SOT-1205 Nexperia BUK9K12-60EX

U2

| | Digi-Key 1727-1897-1-ND | Nexperia BUK9K12-60EX
43 | 2 | BW-746-991 | IC LT3042 adj LDO regulator 200mA MSOP-EP-10 Analog Devices LT3042IMSE#TRPBF

U3 U5

Digi-Key LT3042IMSE#TRPBFCT-ND | Analog Devices LT3042IMSE#TRPBF
44 | 1 | BW-843-693 | IC LTC4365CTS8#TRMPBF Analog Devices LTC4365 Surge Surpressor

U4

Digi-Key 505-LTC4365CTS8#TRMPBFCT-ND | Analog Devices LTC4365CTS8#TRMPBF
45 | 1 | BW-023-157 | IC custom STAC-V1 die 64 pins 0.5mm pitch QFN-64 w/EP BWRC

U6

46 | 1 | BW-157-496 | IC FT2232HL USB to UART/FIFO LQFP-64 FTDI FT2232HL

U7

| | Digi-Key 768-1024-1-ND | FTDI FT2232HL-REEL
47 | 1 | BW-674-698 | IC TS3A27518EPWR 6-ch analog mux TSSOP-24 TI TS3A27518EPWR

U8

| | Digi-Key 296-24570-1-ND | Texas Instrume TS3A27518EPWR
48 | 1 | BW-250-920 | IC IS25LP128-JBLE 128Mbit QSPI flash SOIC-8 ISSI IS25LP128-JBLE

U9

| | Digi-Key 706-1341-ND | ISSI IS25LP128-JBLE
49 | 1 | BW-818-101 | IC APS6404L-3SQR-SN PseudoSRAM PSRAM 8Mx8bits SPI/QSPI SOP-8 AP Memory APS6404L-3SQR-SN U10
Mouser 878-APS6404L-3SQR-SN | AP Memory APS6404L-3SQR-SN
50 | 1 | BW-479-949 | Osc 12MHz with capacitors 3-pin Murata CSTNE12M0GH5L000R0

X1

Digi-Key 490-17947-1-ND | Murata CSTNE12M0GH5L000R0

ASMPCB-STAC-V1

Vendor Name | Vendor Part Number | Manf Name | Manf Part Number

ASMPCB-STAC-V1

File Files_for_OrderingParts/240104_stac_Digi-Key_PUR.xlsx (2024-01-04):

Qty | PartNumber | ID_Number | Manf | Manf PN | Description
300 | 399-C0603C104J4RAC7867TR-ND | P1627900868 | Kemet | C0603C104J4RACTU | Cap ceramic 0.1uF 16V 5% X7R 0603 Kemet C0603C104J4RACTU
100 | 311-1798-1-ND | P2087539935 | Yageo | CC0603KRX7R6BB474 | Cap ceramic 0.47uF 10V 10% X7R 0603 Yageo CC0603KRX7R6BB474
100 | 1276-1892-1-ND | P2096016483 | Samsung | CL10A335KP8NNNC | Cap ceramic 3.3uF 10V 10% X5R 0603 Samsung CL10A335KP8NNNC
100 | 490-7205-1-ND | P0280605691 | Murata | GRM188R6YA75KE15D | Cap ceramic 4.7uF 35V 10% X5R 0603 Murata GRM188R6YA75KE15D
140 | 490-7202-1-ND | P0340685804 | Murata | GRM188R61E106MA73D | Cap ceramic 10uF 25V 20% X5R 0603 Murata GRM188R61E106MA73D
35 | P124158CT-ND | P1555183005 | Panasonic | 16SVPK220M | Cap aluminum polymer 220uF 16V 20% SMD, 6.3mm dia. Panasonic 16SVPK220M
14 | SAM1029-02-ND | P1478035482 | Samtec | TSW-102-07-G-S | Con 2 pin 100 mil pitch 1x2 TSW str male thru 0.230" post height Samtec TSW-102-07-G-S
21 | SAM1029-03-ND | P1032279689 | Samtec | TSW-103-07-G-S | Con 3 pin 100 mil pitch 1x3 TSW str male thru 0.230" post height Samtec TSW-103-07-G-S
7 | SAM1029-04-ND | P0009689266 | Samtec | TSW-104-07-G-S | Con 4 pin 100 mil pitch 1x4 TSW str male thru 0.230" post height Samtec TSW-104-07-G-S
21 | SAM1030-04-ND | P0406013308 | Samtec | TSW-104-07-L-D | Con 8 pin 100 mil pitch 2x4 TSW str male thru 0.230" post height Samtec TSW-104-07-L-D
21 | SAM1041-06-ND | P2092748655 | Samtec | TSW-106-08-L-D-RA | Con 12 pin 100 mil pitch 2x6 TSW RA male thru 0.230" post height Samtec TSW-106-08-L-D-RA
7 | SAM1208-06-ND | P1379046198 | Samtec | SSW-106-01-G-D | Con 12 pin 100 mil pitch 2x6 SSW socket female thru 0.230" post height Samtec SSW-106-01-G-D
7 | SAM1030-08-ND | P0145080344 | Samtec | TSW-108-07-L-D | Con 16 pin 100 mil pitch 2x8 TSW str male thru Samtec TSW-108-07-L-D
7 | WM16908-ND | P1728930425 | Molex | 1053141106 | Con 6 pin 2.5mm pitch 2x3 Nano Fit RA male thru shrouded Molex 1053141106
49 | J502-ND | P1440897126 | Cinch | 142-0701-801 | Con SMA female jack end launch 50 ohm 18GHz PCB long pin (f/62mil board) Cinch 142-0701-801
7 | 664-12402012E212ACT-ND | P1648171012 | Amphenol Commerical | 12402012E212A | Con USB-C 2.0 recp R/A SMT Amphenol 12402012E212A
7 | 490-17947-1-ND | P1539608605 | Murata | CSTNE12M0GH5L000R0 | Osc 12MHz with capacitors 3-pin Murata CSTNE12M0GH5L000R0
100 | 283-PTSLR12066V150CT-ND | P1321441532 | Eaton | PTSLR12066V150 | Fuse PTC reset 6V 1.5A 1206 Eaton PTSLR12066V150
7 | 296-24570-1-ND | P0413184755 | Texas Instruments | TS3A27518EPWR | IC TS3A27518EPWR 6-ch analog mux TSSOP-24 TI TS3A27518EPWR
7 | 706-1341-ND | P0252268228 | ISSI | IS25LP128-JBLE | IC IS25LP128-JBLE 128Mbit QSPI flash SOIC-8 ISSI IS25LP128-JBLE
7 | 93LC56BT-I/OTCT-ND | P0837802966 | Microchip | 93LC56BT-I/OT | IC 93LC56BT-I/OT 2K I2C EEPROM SOT23-6 Microchip 93LC56BT-I/OT
7 | 768-1024-1-ND | P1036134194 | FTDI | FT2232HL-REEL | IC FT2232HL USB to UART/FIFO LQFP-64 FTDI FT2232HL
14 | LT3042IMSE#TRPBFCT-ND | P0647844353 | Analog Devices | LT3042IMSE#TRPBF | IC LT3042 adj LDO regulator 200mA MSOP-EP-10 Analog Devices LT3042IMSE#TRPBF
7 | 505-LT3083EQ#PBF-ND | P2137760264 | Analog Devices | LT3083EQ#PBF | IC LT3083 LDO regulator 3A TAB pkg Analog Devices LT3083EQ#PBF
7 | 505-LTC4365CTS8#TRMPBFCT-ND | P1627100211 | Analog Devices | LTC4365CTS8#TRMPBF | IC LTC4365CTS8#TRMPBF Analog Devices LTC4365 Surge Surpressor
100 | 490-13053-1-ND | P0682033967 | Murata | DFE252012F-1R0M=P2 | Inductor 1uH 3.3A shielded 1008 pkg Murata DFE252012F-1R0M=P2
100 | 754-1933-1-ND | P0040357872 | Kingbright | APT1608LVBC/D | LED 470nm (blue) 2.65V 2mA 0603 SMT Kingbright APT1608LVBC/D
100 | 67-1549-1-ND | P0381882802 | Lumex | SML-LX0603GW-TR | LED 565nm (green) 2.2V 0603 surface-mount Lumex SML-LX0603GW-TR
100 | 7017X1CT-ND | P0747086974 | VCC | 7017X1 | LED 660nm (red) 1.7V 0603 SMT VCC 7017X1
100 | 160-1830-1-ND | P1869870204 | Liteon | LTST-C193KRKT-5A | LED 631nm (red) 2V 5mA 0603 SMT Lite-On LTST-C193KRKT-5A
7 | 1727-1897-1-ND | P0189054582 | Nexperia | BUK9K12-60EX | MOSFET N-CH dual 60V 35A SOT-1205 Nexperia BUK9K12-60EX
100 | P123739CT-ND | P1379979855 | Panasonic | ERA-3AED123V | Res 12K 0.5% 1/10W 0603 Panasonic
100 | RMCF0603FT10R0CT-ND | P0574480276 | Stackpole | RMCF0603FT10R0 | Res 10 1% 1/10W 0603 Stackpole RMCF0603FT10R0
100 | RMCF0603FT75R0CT-ND | P0992637931 | Stackpole | RMCF0603FT75R0 | Res 75 1% 1/10W 0603 Stackpole RMCF0603FT75R0
100 | 13-RT0603BRE07250RLCT-ND | P0184152988 | Yageo | RT0603BRE07250RL | Res 250 0.1% 1/10W 0603 Yageo RT0603BRE07250RL
100 | P301DBCT-ND | P0425882638 | Panasonic | ERA-3AEB3010V | Res 301 1% 1/10W 0603 Panasonic ERA-3AEB3010V
100 | 10-ERJ-U03F3300VCT-ND | P1530658890 | Panasonic | ERJ-U03F3300V | Res 330 1% 1/10W 0603 Panasonic ERJ-U03F3300V
100 | P909HCT-ND | P0380563321 | Panasonic | ERJ-3EKF9090V | Res 909 1% 1/10W 0603 Panasonic ERJ-3EKF9090V
100 | 13-RC0603FR-132K2LCT-ND | P1890948448 | Yageo | RC0603FR-132K2L | Res 2.2K 1% 1/10W 0603 Yageo RC0603FR-132K2L
100 | P4.70KHCT-ND | P0329692396 | Panasonic | ERJ-3EKF4701V | Res 4.7K 1% 1/10W 0603 Panasonic ERJ-3EKF4701V
126 | P5.10KHCT-ND | P1727249567 | Panasonic | ERJ-3EKF5101V | Res 5.1K 1% 1/10W 0603 Panasonic ERJ-3EKF5101V
100 | 311-10.0KHRCT-ND | P0554824999 | Yageo | RC0603FR-0710KL | Res 10K 1% 1/10W 0603 Yageo RC0603FR-0710KL
100 | P15.0KHCT-ND | P1359112647 | Panasonic | ERJ-3EKF1502V | Res 15K 1% 1/10W 0603 Panasonic
100 | P33.2KHCT-ND | P1708880617 | Panasonic | ERJ-3EKF3322V | Res 33.2K 1% 1/10W 0603 Panasonic ERJ-3EKF3322V
100 | P82.5KHCT-ND | P0333605527 | Panasonic | ERJ-3EKF8252V | Res 82.5K 1% 1/10W 0603 Panasonic ERJ-3EKF8252V
100 | P100KHCT-ND | P0857617141 | Panasonic | ERJ-3EKF1003V | Res 100K 1% 1/10W 0603 Panasonic ERJ-3EKF1003V
100 | P200KHCT-ND | P1502467789 | Panasonic | ERJ-3EKF2003V | Res 200K 1% 1/10W 0603 Panasonic ERJ-3EKF2003V
100 | P215KHCT-ND | P0217820168 | Panasonic | ERJ-3EKF2153V | Res 215K 1% 1/10W 0603 Panasonic ERJ-3EKF2153V
100 | P510KHCT-ND | P0770113580 | Panasonic | ERJ-3EKF5103V | Res 510K 1% 1/10W 0603 Panasonic ERJ-3EKF5103V
100 | P2.7MGCT-ND | P1862694626 | Panasonic | ERJ-3GEYJ275V | Res 2.7M 5% 1/10W 0603 Panasonic ERJ-3GEYJ275V
100 | P0.0GCT-ND | P1468916339 | Panasonic | ERJ-3GEY0R00V | Res 0 1/10W 0603 Panasonic ERJ-3GEY0R00V
7 | 3214X-1-502ECT-ND | P0372080198 | Bourns | 3214X-1-502E | Res var trimmer pot 5K 1/4W 3-pin SMT Bourns 3214X-1-502E
14 | 360-2131-ND | P0238556003 | NKK | CS12ANW03 | Switch slide SPDT 3A 125V ST thru NKK CS12ANW03
7 | 450301014042-ND | P1748217584 | Wurth | 450301014042 | Switch slide SPDT ST thru Wurth 450301014042
21 | CKN12326-1-ND | P0919024313 | C&K | PTS636 SK25J SMTR LFS | Switch momentary SPST-NO tactile 2 pin J-lead low-profile 2.5mm SMT C&K PTS636 SK25J SMTR LFS
7 | 732-6964-1-ND | P0836773796 | Wurth | 418121270806 | Switch DIP 6 position, 12 pin, SMT Wurth 418121270806
100 | F2594CT-ND | P1928976951 | Littlefuse | PGB1010603MR | Diode TVS 24VWM 150VC 0603 Littelfuse PGB1010603MR
7 | 36-5008-ND | P0825420063 | Keystone | 5008 | Test point loop 63mil dia hole orange Keystone 5008
7 | 36-5006-ND | P2134052254 | Keystone | 5006 | Test point loop 63mil dia hole black Keystone 5006
14 | 36-5009-ND | P1074398753 | Keystone | 5009 | Test point loop 63mil dia hole yellow Keystone 5009

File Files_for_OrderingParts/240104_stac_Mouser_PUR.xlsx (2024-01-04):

Qty | PartNumber | ID_Number | Manf | Manf PN | Description
7 | 878-APS6404L-3SQR-SN | P1727871239 | AP Memory | APS6404L-3SQR-SN | IC APS6404L-3SQR-SN PseudoSRAM PSRAM 8Mx8bits SPI/QSPI SOP-8 AP Memory APS6404L-3SQR-SN

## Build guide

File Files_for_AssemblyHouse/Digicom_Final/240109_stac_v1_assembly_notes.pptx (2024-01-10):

## Digicom Assembly Notes

STAC v1 PCB Revision 1
Rahul Kumar (rahulkumar@berkeley.edu), Anita Flynn (aflynn@berkeley.edu)
January 2024

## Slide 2

XTAL (Murata CSTNE12M0GH5L000R0)

The crystal looks symmetric, but according to the datasheet, pins 1 and 3 are not interchangeable. Need to make sure this gets assembled in the correct orientation.
The datasheet specifies the orientation of the crystal when it is packaged. Our PCB footprint indicates the pin numbers. Please make sure the crystal pins match the footprint pins when placed (ie. be careful not to rotate 180 degrees).
Links:
Digikey (https://www.digikey.com/en/products/detail/murata-electronics/CSTNE12M0GH5L000R0/8747728)
Datasheet (https://www.murata.com/en/products/productdata/8801162133534/SPEC-CSTNE12M0GH5L000R0.pdf)

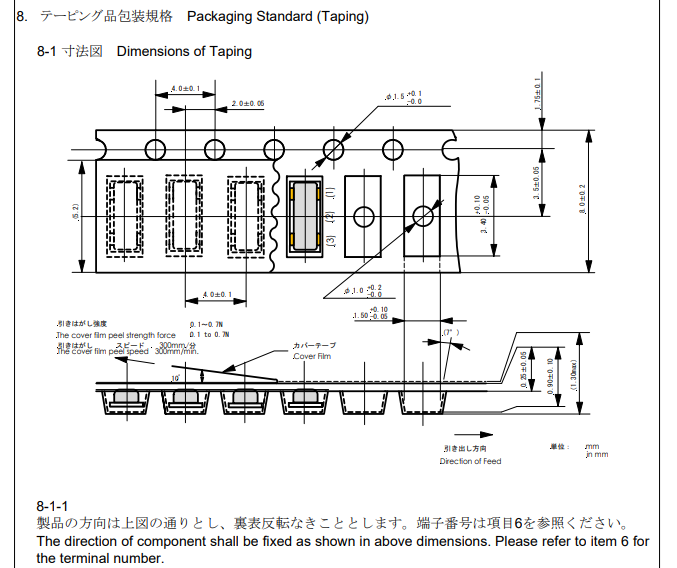
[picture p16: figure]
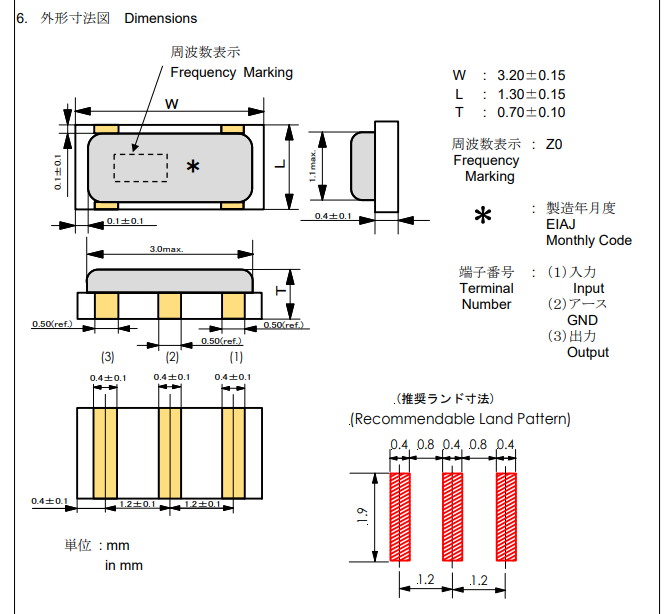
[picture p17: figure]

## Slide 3

Power Switch (Wurth 450301014042)

This switch has an unconventional pin numbering: pin 1 is in the middle.
Our footprint indicates the locations of pins 2 and 3. Please make sure the switch is assembled matching the pin specification (ie. be careful not to rotate 180 degrees).
The switch has a circular dimple that indicates the location of pin 3 (see blue arrow).
Links:
Digikey (https://www.digikey.com/en/products/detail/w%C3%BCrth-elektronik/450301014042/5209104)
Datasheet (https://www.we-online.com/components/products/datasheet/450301014042.pdf)

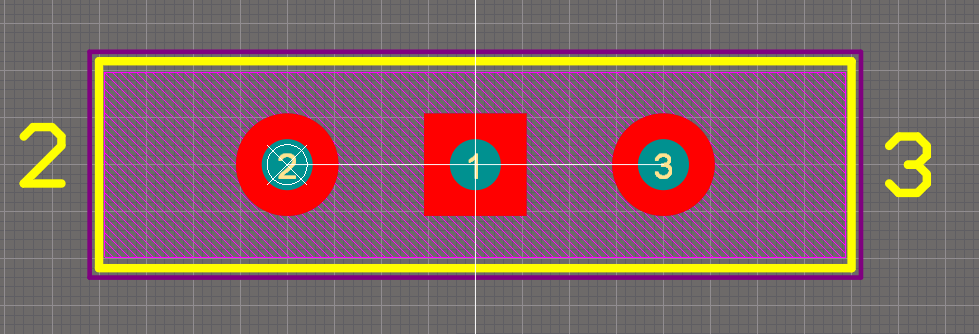
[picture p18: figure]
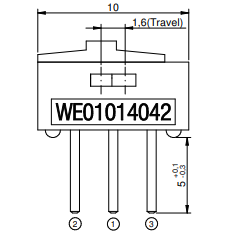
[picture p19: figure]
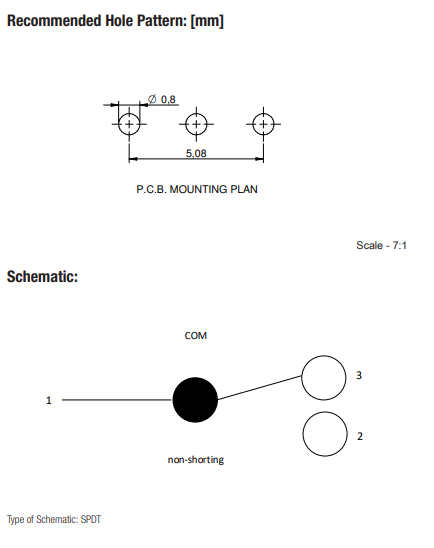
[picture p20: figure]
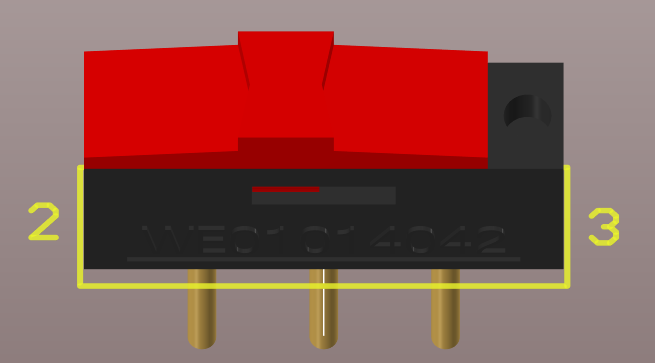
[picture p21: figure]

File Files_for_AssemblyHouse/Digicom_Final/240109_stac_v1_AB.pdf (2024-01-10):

Find-TC Count | Ref_Des | Part_Number | Description
Job Name: | stac-v1.bmb

Date: 1/9/2024

Page:
Build Count: | 1
Build SIdes: | Parts Not Stuffed
| | | | Time: 18:33
| | | Sort Code
1 | 1 R25 | BW-532-263 | L1 RES 0 | Res 0 1/10W 0603 Panasonic ERJ-3GEY0R00V

Find-TC Count | Ref_Des | Part_Number | Description

Date: 1/9/2024

## Build SIdes: SMT Hand Parts RED = Top

Time: 18:33
Sort Code
2 | 1 J17 | BW-536-719 | R1 CON-USB C | Con USB-C 2.0 recp R/A SMT Amphenol 12402012E212A
3 | 7 J5, J6, J9, J11, J13, | BW-867-891
| J15, J16 | | | Con SMA female jack end launch 50 ohm 18GHz PCB long pin f/62mil board Cinch 1

D4 CON-RF SMA edge mnt

Find-TC Count | Ref_Des | Part_Number | Description

Date: 1/9/2024

## Build SIdes: Thru Hole Hand Parts RED = Top

Time: 18:33
Sort Code
4 | 2 J19, J23 | BW-038-636 | Con 2 pin 100 mil pitch 1x2 TSW str male thru 0.230" post height
Samtec TSW-102-

A5 CON-100 TSW 2

5 | 2 T12, T13 | BW-067-710 | V7 TEST-PT 1 | Test point loop 63mil dia hole yellow Keystone 5009
6 | 1 J14 | BW-137-712 | | Con 12 pin 100 mil pitch 2x6 SSW socket female thru 0.230" post height Samtec SS

E6 CON-100 SSW 12

7 | 3 J4, J8, J10 | BW-220-198 | Con 12 pin 100 mil pitch 2x6 TSW RA male thru 0.230" post height Samtec TSW-106-

F3 CON-100 TSW 12

8 | 1 J1 | BW-350-204 | Con 6 pin 2.5mm pitch 2x3 Nano Fit RA male thru shrouded Molex 1053141106

H7 CON-2.5MM Nano Fit 6

9 | 1 S3 | BW-431-238 | U7 SW SPDT | Switch slide SPDT ST thru Wurth 450301014042
10 | 1 J7 | BW-491-171 | | Con 4 pin 100 mil pitch 1x4 TSW str male thru 0.230" post height Samtec TSW-104-

K5 CON-100 TSW 4

11 | 1 J12 | BW-510-530 | Con 16 pin 100 mil pitch 2x8 TSW str male thru Samtec TSW- 108-07-L-D

T5 CON-100 TSW 16

12 | 3 J2, J3, J18 | BW-517-054 | Con 3 pin 100 mil pitch 1x3 TSW str male thru 0.230" post height Samtec TSW-103-

K6 CON-100 TSW 3

13 | 2 S1, S2 | BW-522-992 | H6 SW SPDT | Switch slide SPDT 3A 125V ST thru NKK CS12ANW03
14 | 1 T4 | BW-602-053 | E6 TEST-PT 1 | Test point loop 63mil dia hole orange Keystone 5008
15 | 3 J20, J21, J22 | BW-623-913 | | Con 8 pin 100 mil pitch 2x4 TSW str male thru 0.230" post height Samtec TSW-104-

V2 CON-100 TSW 8

16 | 1 T10 | BW-966-768 | M8 TEST-PT 1 | Test point loop 63mil dia hole black Keystone 5006

Find-TC Count | Ref_Des | Part_Number | Description

Date: 1/9/2024

## Build SIdes: SMT Machine Parts

Time: 18:33
Sort Code
17 | 1 R33 | BW-005-683 | P4 R1%-0603 2.2K | Res 2.2K 1% 1/10W 0603 Yageo RC0603FR-132K2L
18 | 1 U6 | BW-023-157 | | IC custom STAC-V1 die 64 pins 0.5mm pitch QFN-64 w/EP BWRC

D1 DIE-CUSTOM STAC-V1

19 | 4 R27, R29, R31, R32 | BW-038-468 | C1 R1%-0603 10K | Res 10K 1% 1/10W 0603 Yageo RC0603FR-0710KL
20 | 1 D7 | BW-087-782 | | LED 631nm red 2V 5mA 0603 SMT Lite-On LTST-C193KRKT- 5A

B8 LED red

21 | 1 R7 | BW-131-959 | H6 R1%-0603 82.5K | Res 82.5K 1% 1/10W 0603 Panasonic ERJ-3EKF8252V
22 | 1 R15 | BW-146-387 | V7 R1%-0603 75 | Res 75 1% 1/10W 0603 Stackpole RMCF0603FT75R0
23 | 1 U7 | BW-157-496 | M3 IC FT2232HL | IC FT2232HL USB to UART/FIFO LQFP-64 FTDI FT2232HL
24 | 6 C9, C10, C12, C13, | BW-171-235
| C31, C33 | | | Cap ceramic 4.7uF 35V 10% X5R 0603 Murata GRM188R6YA75KE15D

L2 CAPC-0603 4.7uF 35V

25 | 1 C36 | BW-183-150 | Cap ceramic 3.3uF 10V 10% X5R 0603 Samsung CL10A335KP8NNNC

H8 CAPC-0603 3.3uF 10V

26 | 18 R23, R24, R34, R35, | BW-200-113
| R36, R37, R38, R39, R40, R41, R42, R43, R44, R45, R46, R47, R48, R49
B6 R1%-0603 5.1K | Res 5.1K 1% 1/10W 0603 Panasonic ERJ-3EKF5101V
27 | 1 D4 | BW-219-501 | N8 LED red | LED 660nm red 1.7V 0603 SMT VCC 7017X1
28 | 20 C1, C3, C15, C16, | BW-224-068
| C17, C18, C19, C20, C21, C22, C30, C35, C37, C38, C39, C40, C41, C42, C43, C53 | | | Cap ceramic 10uF 25V 20% X5R 0603 Murata GRM188R61E106MA73D

U8 CAPC-0603 10uF 25V

29 | 2 L1, L2 | BW-227-124 | Inductor 1uH 3.3A shielded 1008 pkg Murata DFE252012F- 1R0M=P2

K4 IND-1008 1uH 3.3A

30 | 1 U10 | BW-250-920 | IC IS25LP128-JBLE 128Mbit QSPI flash SOIC-8 ISSI IS25LP128-JBLE

K2 IC IS25LP128-JBLE

31 | 1 R9 | BW-257-784 | R3 RVAR 5K | Res var trimmer pot 5K 1/4W 3-pin SMT Bourns 3214X-1-502E
32 | 1 R2 | BW-303-795 | N3 R1%-0603 100K | Res 100K 1% 1/10W 0603 Panasonic ERJ-3EKF1003V
33 | 3 R8, R11, R16 | BW-354-763 | T8 R1%-0603 301 | Res 301 1% 1/10W 0603 Panasonic ERA-3AEB3010V
34 | 2 C11, C14 | BW-367-353 | | Cap ceramic 0.47uF 10V 10% X7R 0603 Yageo CC0603KRX7R6BB474

R5 CAPC-0603 0.47uF 10V

35 | 1 R5 | BW-421-162 | C5 R5%-0603 2.7M | Res 2.7M 5% 1/10W 0603 Panasonic ERJ-3GEYJ275V
36 | 1 R6 | BW-446-612 | P8 R1%-0603 15K | Res 15K 1% 1/10W 0603 Panasonic
37 | 4 R14, R18, R19, R22 | BW-457-217 | R3 R1%-0603 330 | Res 330 1% 1/10W 0603 Panasonic ERJ-U03F3300V
38 | 1 U2 | BW-471-924 | | MOSFET N-CH dual 60V 35A SOT-1205 Nexperia BUK9K12- 60EX

J7 Q-NMOS BUK9K12-
60EX
39 | 1 X1 | BW-479-949 | Osc 12MHz with capacitors 3-pin Murata CSTNE12M0GH5L000R0

J3 CRY-OSC 12MHz

40 | 1 R4 | BW-514-032 | N6 R1%-0603 510K | Res 510K 1% 1/10W 0603 Panasonic ERJ-3EKF5103V
41 | 1 R30 | BW-528-389 | D5 R.5%-0603 12K | Res 12K 0.5% 1/10W 0603 Panasonic
42 | 1 R17 | BW-532-263 | L1 RES 0 | Res 0 1/10W 0603 Panasonic ERJ-3GEY0R00V

Find-TC Count | Ref_Des | Part_Number | Description

Date: 1/9/2024

## Build SIdes: SMT Machine Parts

Time: 18:33
Sort Code
43 | 1 R10 | BW-560-201 | K4 R1%-0603 215K | Res 215K 1% 1/10W 0603 Panasonic ERJ-3EKF2153V
44 | 3 S4, S6, S7 | BW-591-967 | | Switch momentary SPST-NO tactile 2 pin J-lead low-profile 2.5mm SMT C K PTS636 S

A6 SW SPST-NO

45 | 1 R13 | BW-628-791 | R6 R1%-0603 33.2K | Res 33.2K 1% 1/10W 0603 Panasonic ERJ-3EKF3322V
46 | 1 F1 | BW-633-217 | M7 FUSE 1.5A | Fuse PTC reset 6V 1.5A 1206 Eaton PTSLR12066V150
47 | 19 C4, C23, C24, C25, | BW-663-053
| C26, C27, C28, C29, C32, C34, C44, C45, C46, C47, C48, C49, C50, C51, C52 | | | Cap ceramic 0.1uF 16V 5% X7R 0603 Kemet C0603C104J4RACTU

D3 CAPC-0603 0.1uF 16V

48 | 1 U9 | BW-674-698 | IC TS3A27518EPWR 6-ch analog mux TSSOP-24 TI TS3A27518EPWR

U7 IC TS3A27518EPWR

49 | 2 E1, E2 | BW-697-885 | K7 TASIL-BI | Diode TVS 24VWM 150VC 0603 Littelfuse PGB1010603MR
| | | PGB1010603MR
50 | 2 R20, R21 | BW-708-683 | C6 R1%-0603 10 | Res 10 1% 1/10W 0603 Stackpole RMCF0603FT10R0
51 | 1 R26 | BW-725-833 | W1 R1%-0603 4.7K | Res 4.7K 1% 1/10W 0603 Panasonic ERJ-3EKF4701V
52 | 2 U3, U5 | BW-746-991 | | IC LT3042 adj LDO regulator 200mA MSOP-EP-10 Analog Devices LT3042IMSE#TRPBF

U8 IC LT3042

53 | 3 D1, D2, D8 | BW-747-432 | LED 565nm green 2.2V 0603 surface-mount Lumex SML- LX0603GW-TR

R5 LED green

54 | 1 R3 | BW-760-287 | M2 R1%-0603 200K | Res 200K 1% 1/10W 0603 Panasonic ERJ-3EKF2003V
55 | 2 R12, R28 | BW-784-622 | K1 R1%-0603 250 | Res 250 0.1% 1/10W 0603 Yageo RT0603BRE07250RL
56 | 1 R1 | BW-812-714 | E3 R1%-0603 909 | Res 909 1% 1/10W 0603 Panasonic ERJ-3EKF9090V
57 | 1 U11 | BW-818-101 | | IC APS6404L-3SQR-SN PseudoSRAM PSRAM 8Mx8bits SPI/QSPI SOP-8 AP Memory APS6404L-

G4 IC APS6404L-3SQR-SN

58 | 1 U4 | BW-843-693 | IC LTC4365CTS8#TRMPBF Analog Devices LTC4365 Surge Surpressor

H7 IC
LTC4365CTS8#TRMPBF
59 | 1 U1 | BW-849-997 | IC LT3083 LDO regulator 3A TAB pkg Analog Devices LT3083EQ#PBF

D7 IC LT3083

60 | 3 D3, D5, D6 | BW-885-747 | LED 470nm blue 2.65V 2mA 0603 SMT Kingbright APT1608LVBC/D

P4 LED blue

61 | 1 U8 | BW-913-765 | IC 93LC56BT-I/OT 2K I2C EEPROM SOT23-6 Microchip 93LC56BT-I/OT

B2 IC 93LC56BT-I/OT

62 | 1 S5 | BW-977-175 | N2 SW DIP-6 | Switch DIP 6 position, 12 pin, SMT Wurth 418121270806
63 | 5 C2, C5, C6, C7, C8 | BW-998-821 | | Cap aluminum polymer 220uF 16V 20% SMD, 6.3mm dia. Panasonic 16SVPK220M

W1 CAPE-AL-GP 220uF
16V

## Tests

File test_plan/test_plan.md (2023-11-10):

# STAC Test Plan

See the test plan in [stac-top](https://github.com/ucb-bar/stac-top/blob/stac-master/docs/test_plan.md).

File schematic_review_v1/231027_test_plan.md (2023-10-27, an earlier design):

# STAC Test Plan

See the [chip docs](./test_chip.md) for information on what's on the chip
and the modes of testing the SRAMs, including a high-level description of
possible test sequences.
This document will focus on board-level testing concerns.

## Power

A 6V external power supply is fed to an over/under voltage protection IC.
A power on button is fed to this IC. The IC debounces the button
and turns on the output power when the button is pressed.

A first stage LDO regulates the 6V supply to 5V.
One second stage LDO regulates the 5V LDO output to 3.3V for VDDIO;
another LDO regulates the 5V output to 1.8V for VDDD.

If we wish to bypass the LDOs or test the chip under different voltages,
power can also be supplied via a dedicated header. Two independent switches
(one for VDDD, one for VDDIO)
select between the on-board regulated power and the external power header.

## Clocking

The digital clock (`clock_clock`) and the SRAM sense amp clock (`SRAM_SAE_CLK`)
are provided to the board using SMA connectors.
The SKY130 GPIOs claim to have a maximum frequency of ~66 MHz, so if the on-chip
PLL does not work, the maximum testable clock frequency will be 66 MHz.

## Digital signals

All SRAM and Rocket digital signals will be broken out to 0.1" headers
compatible with the Arty A7-100T FPGA platform.

The 7 serial TileLink signals will be routed to a 12-pin PMOD connector,
which can also plug in the one of the PMOD slots on the Arty A7-100T.

The FPGA will be used for all digital testing, including application
of test stimuli. The Arty PLL can generate at least an 800MHz clock,
which should be sufficiently oversampled for our < 100 MHz expected test frequency.

In the event that the our on-chip PLL works and we are able to run
SRAM test sequences at higher frequencies,
we can still use the FPGA to read out the BIST checksum via the scan chain.
This scan chain readout need not be particularly fast.

## Equipment Needed

* Power supply
* Square wave function generator for clock
* Multiphase clock generator
* Arty A7-100T

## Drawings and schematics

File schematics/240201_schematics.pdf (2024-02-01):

# 0 clock_clock clock_clock_isolated

# SRAM Timing Analysis Chip (STAC) Test Board

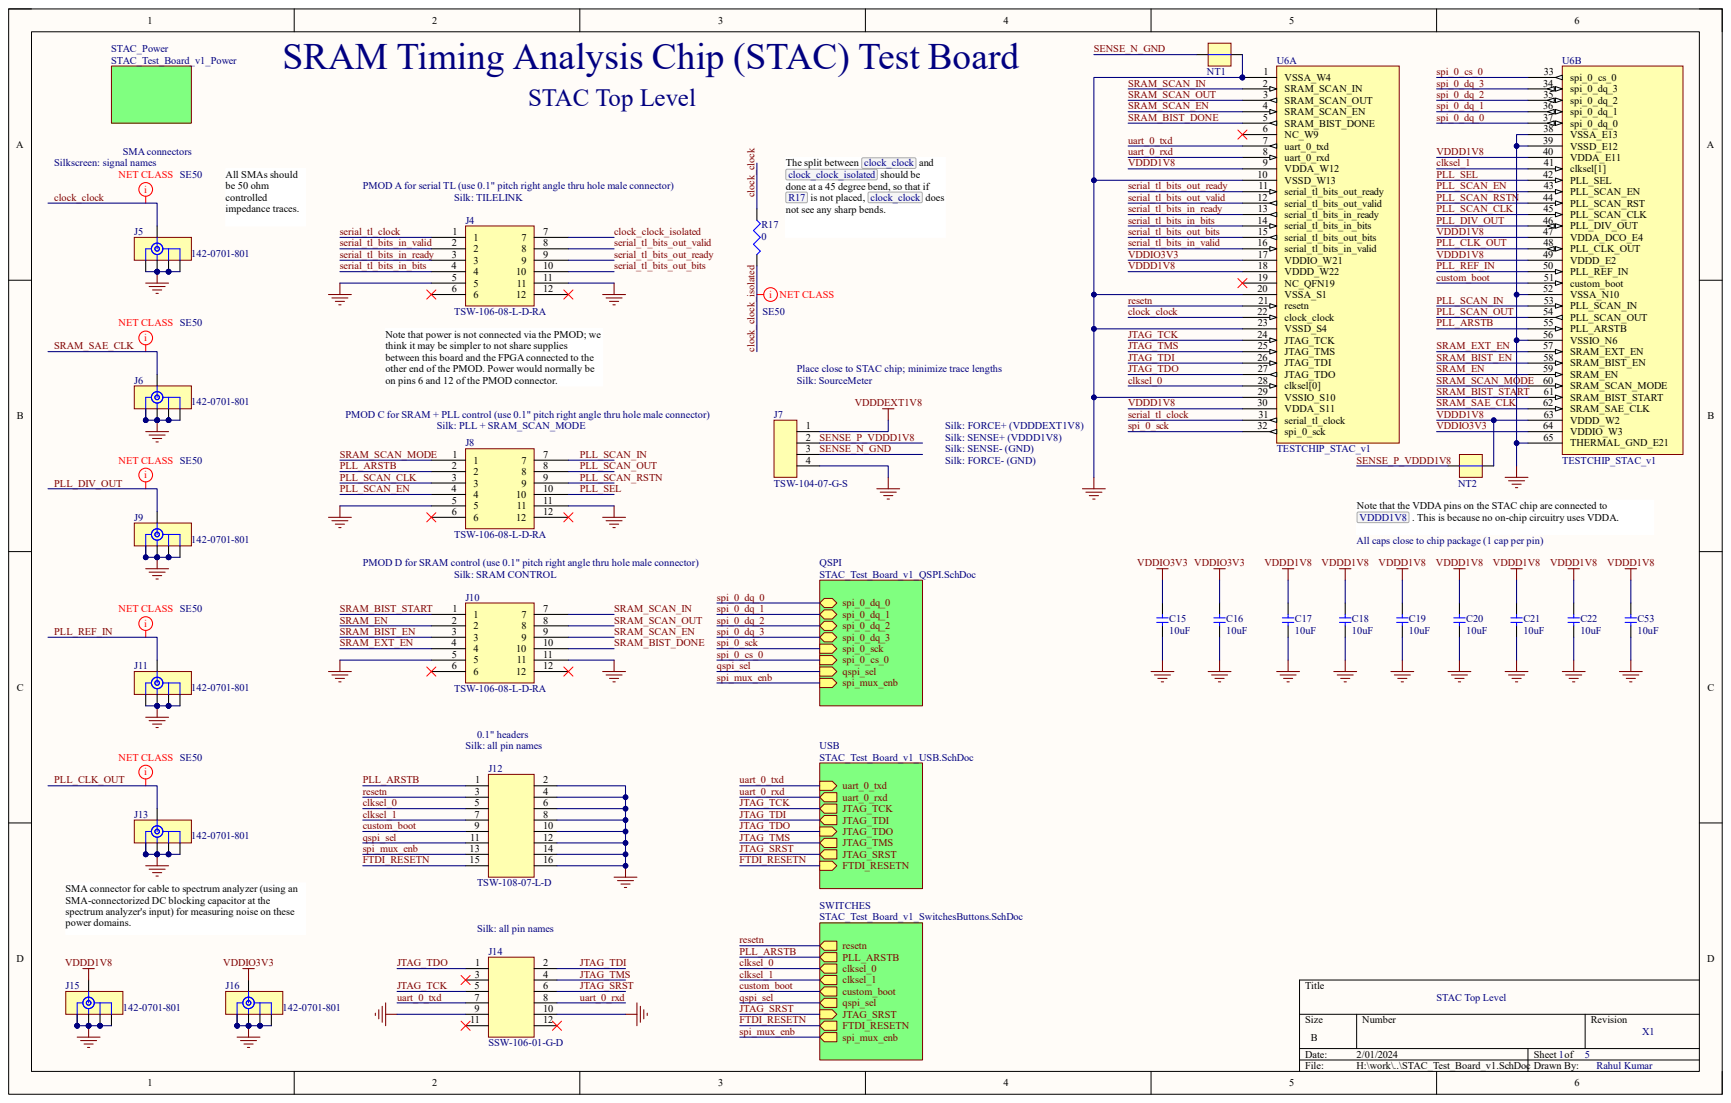
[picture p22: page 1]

The split between clock_clock and
clock_clock_isolated should be
done at a 45 degree bend, so that if
R17 is not placed, clock_clock does
not see any sharp bends.

PMOD A for serial TL (use 0.1" pitch right angle thru hole male connector)

Note that power is not connected via the PMOD; we
think it may be simpler to not share supplies
between this board and the FPGA connected to the
other end of the PMOD. Power would normally be
on pins 6 and 12 of the PMOD connector.

Place close to STAC chip; minimize trace lengths
Silk: SourceMeter

PMOD C for SRAM + PLL control (use 0.1" pitch right angle thru hole male connector)

Note that the VDDA pins on the STAC chip are connected to
VDDD1V8 . This is because no on-chip circuitry uses VDDA.

All caps close to chip package (1 cap per pin)

0.1" headers
Silk: all pin names

SMA connector for cable to spectrum analyzer (using an
SMA-connectorized DC blocking capacitor at the
spectrum analyzer's input) for measuring noise on these
power domains.

## 1st stage LDO (6V->5V)

## Silk: 5V

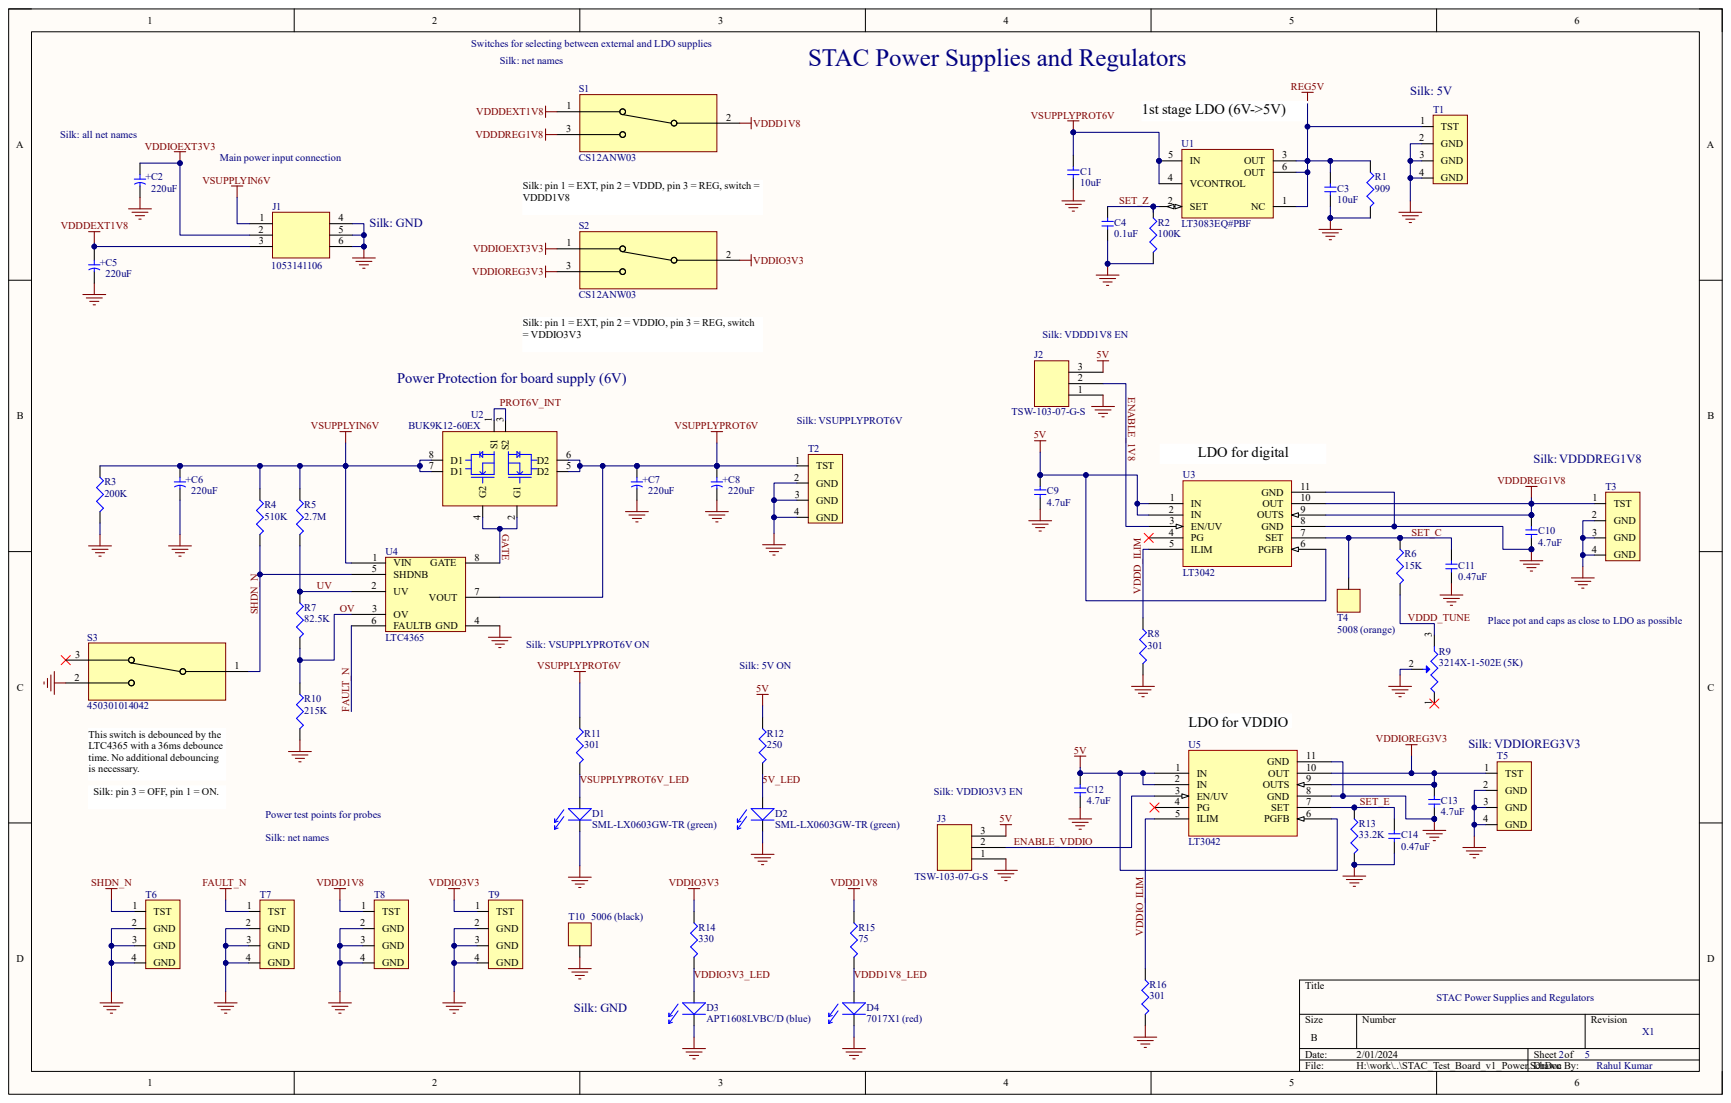
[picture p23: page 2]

Switches for selecting between external and LDO supplies
Silk: net names

STAC Power Supplies and Regulators

Silk: all net names

Silk: pin 1 = EXT, pin 2 = VDDD, pin 3 = REG, switch =
VDDD1V8

Silk: pin 1 = EXT, pin 2 = VDDIO, pin 3 = REG, switch
= VDDIO3V3

Power Protection for board supply (6V)

Place pot and caps as close to LDO as possible

This switch is debounced by the
LTC4365 with a 36ms debounce
time. No additional debouncing
is necessary.

Silk: pin 3 = OFF, pin 1 = ON.

Power test points for probes

# VDDIO3V3 TXLED

# VDDIO3V3 RXLED

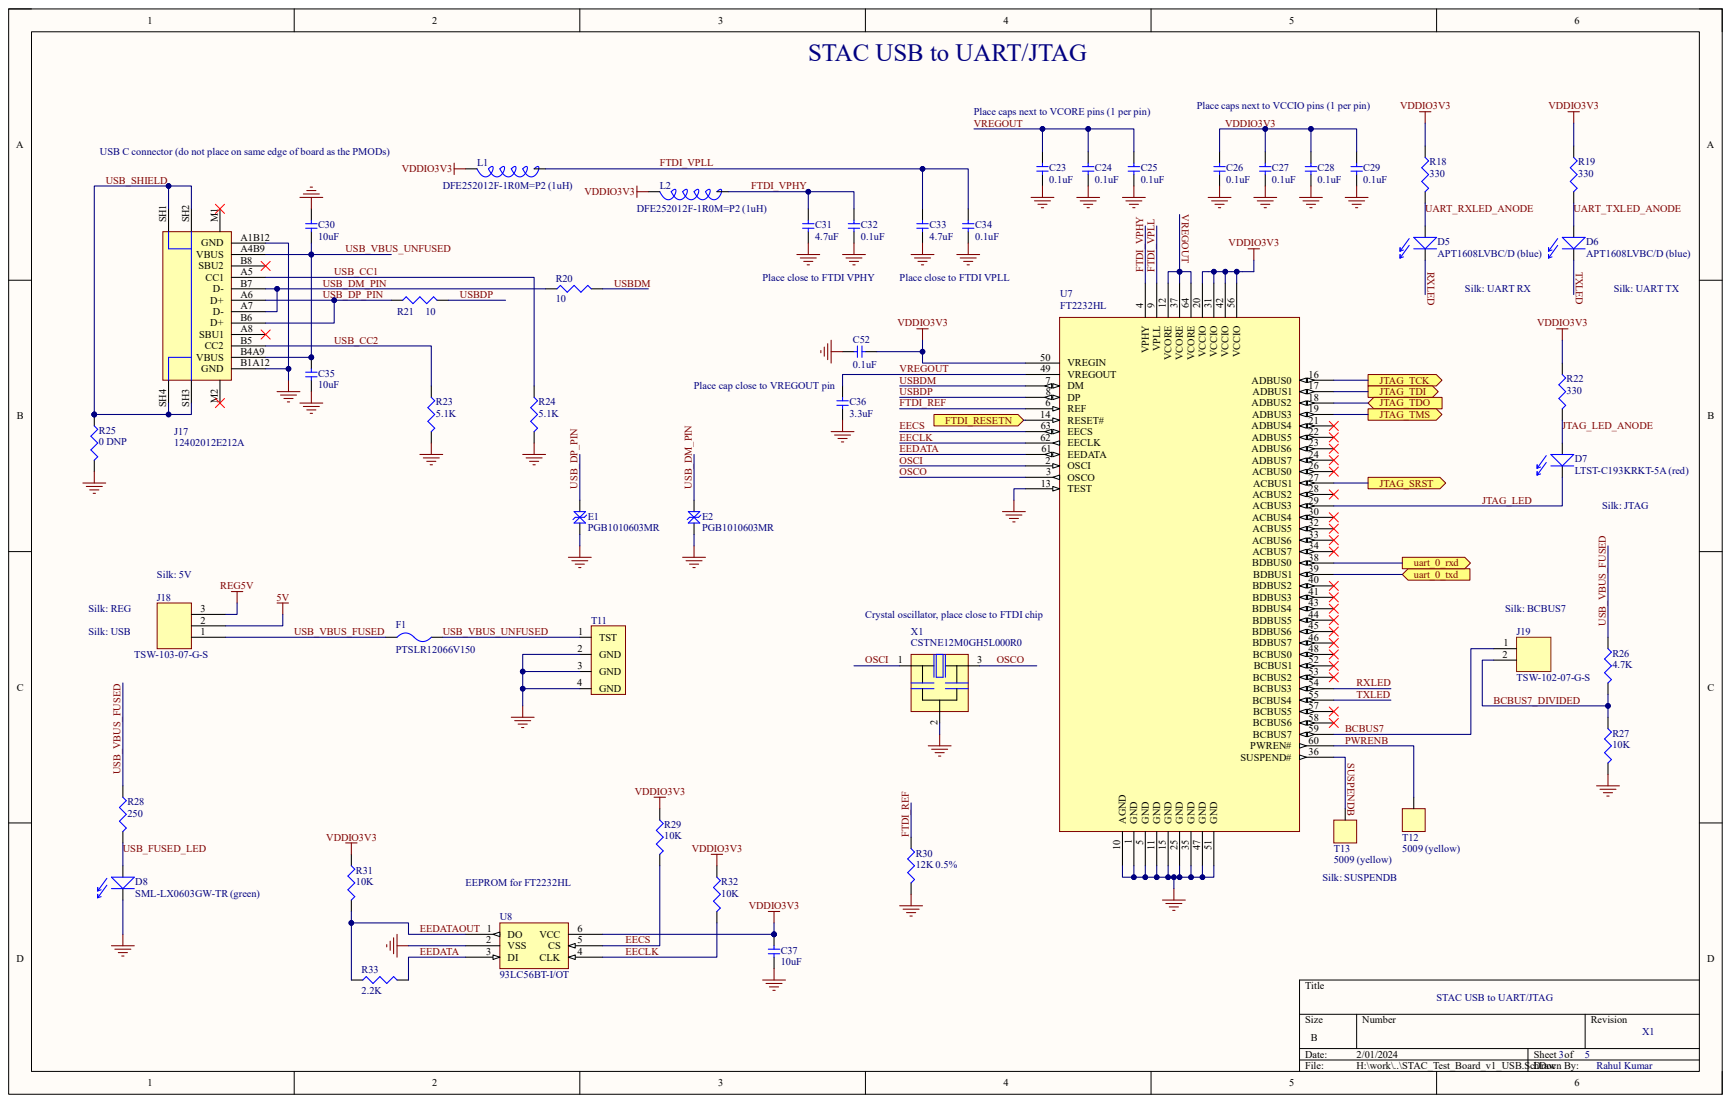
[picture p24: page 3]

STAC USB to UART/JTAG

Place caps next to VCORE pins (1 per pin)
VREGOUT

Place caps next to VCCIO pins (1 per pin)
VDDIO3V3

USB C connector (do not place on same edge of board as the PMODs)

Place cap close to VREGOUT pin

Crystal oscillator, place close to FTDI chip

5 GND 11 GND 15 GND 25 GND 35 GND 47 GND 51

# STAC Quad-SPI Peripherals

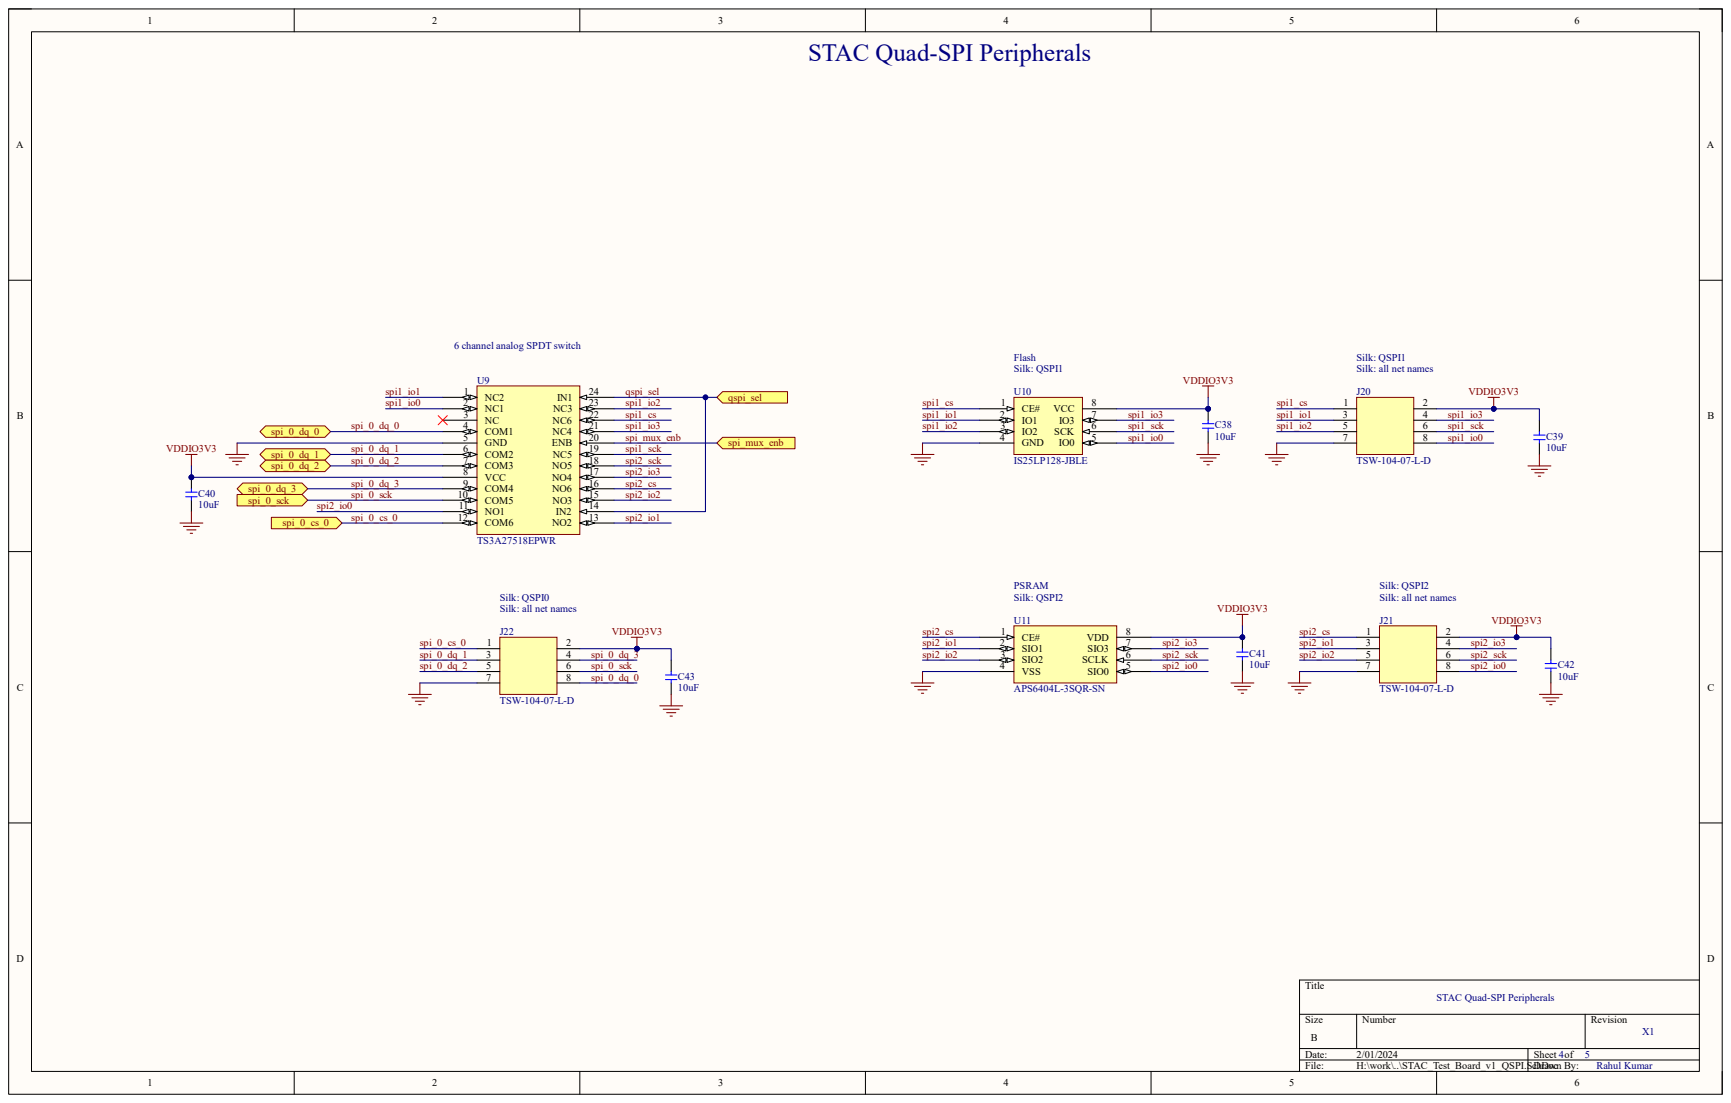
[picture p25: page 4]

6 channel analog SPDT switch

Silk: QSPI1
Silk: all net names

Silk: QSPI2

Silk: QSPI0

STAC Quad-SPI Peripherals

# STAC User Switches and Buttons

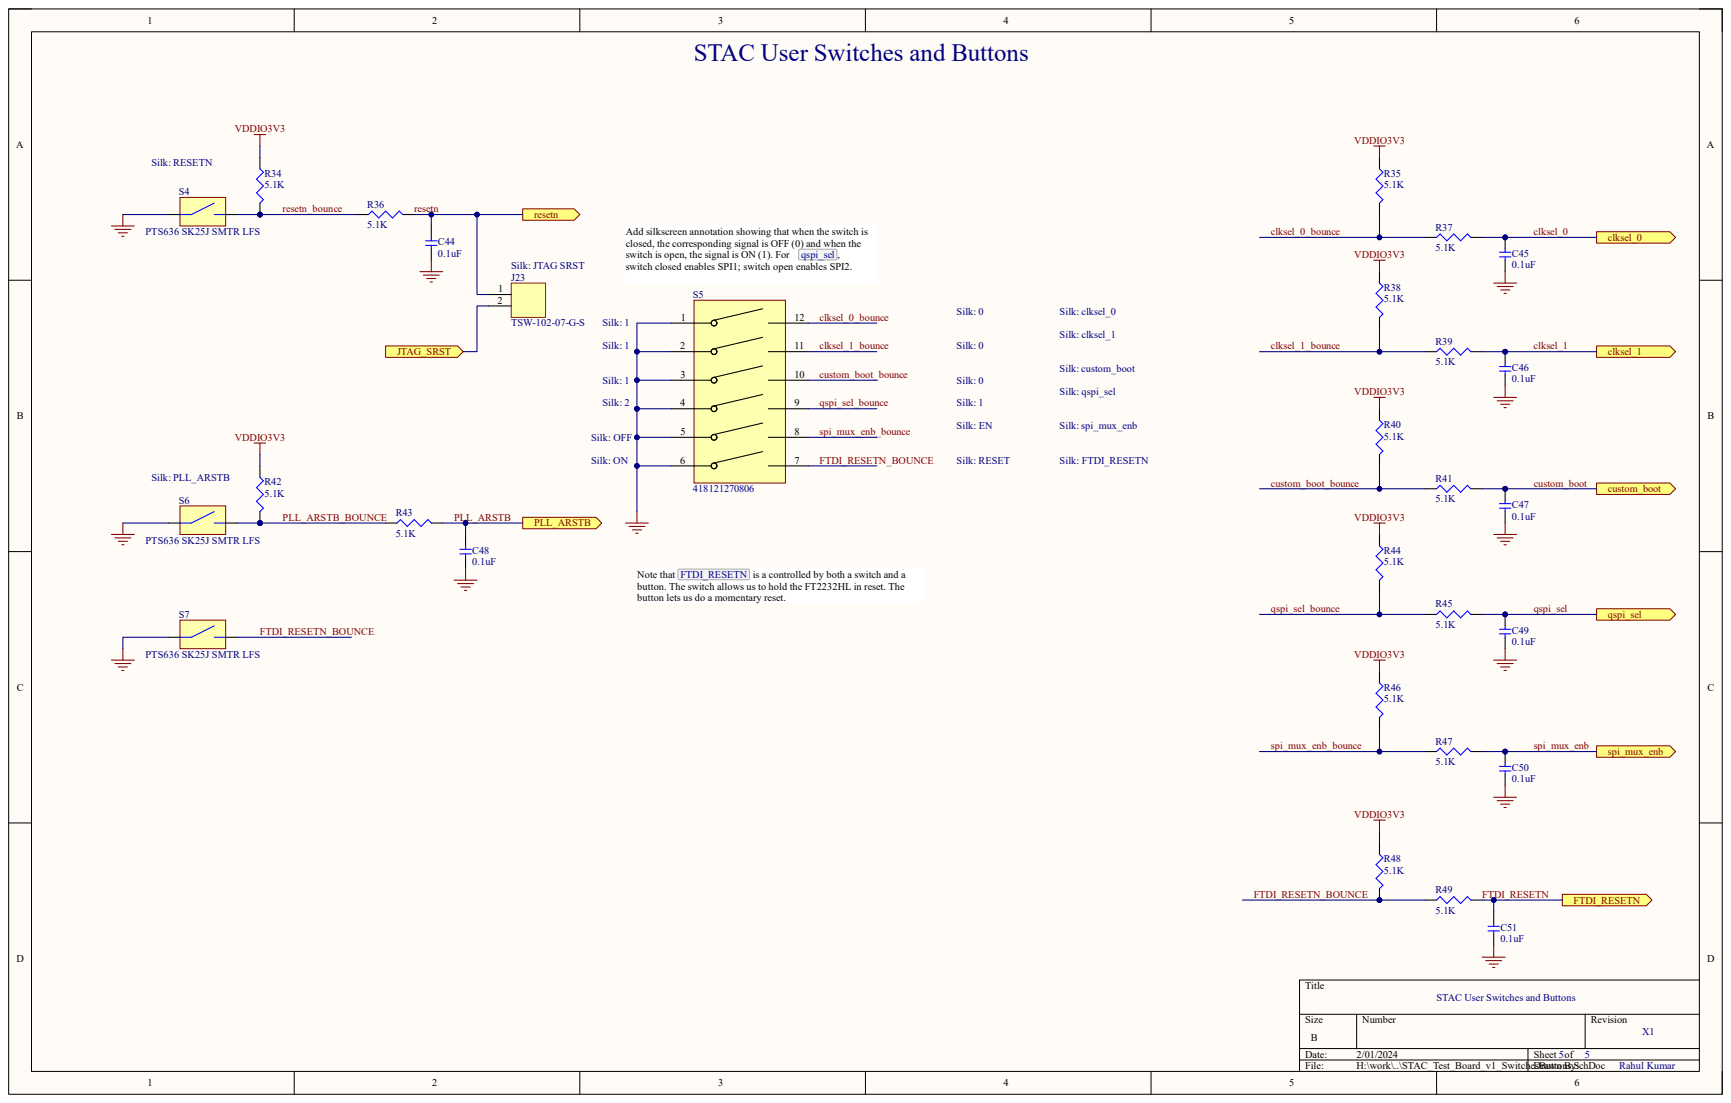
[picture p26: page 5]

Add silkscreen annotation showing that when the switch is
closed, the corresponding signal is OFF (0) and when the
switch is open, the signal is ON (1). For qspi_sel ,
switch closed enables SPI1; switch open enables SPI2.

Note that FTDI_RESETN is a controlled by both a switch and a
button. The switch allows us to hold the FT2232HL in reset. The
button lets us do a momentary reset.

STAC User Switches and Buttons

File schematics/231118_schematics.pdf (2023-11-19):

# 0 clock_clock clock_clock_isolated

# SRAM Timing Analysis Chip (STAC) Test Board

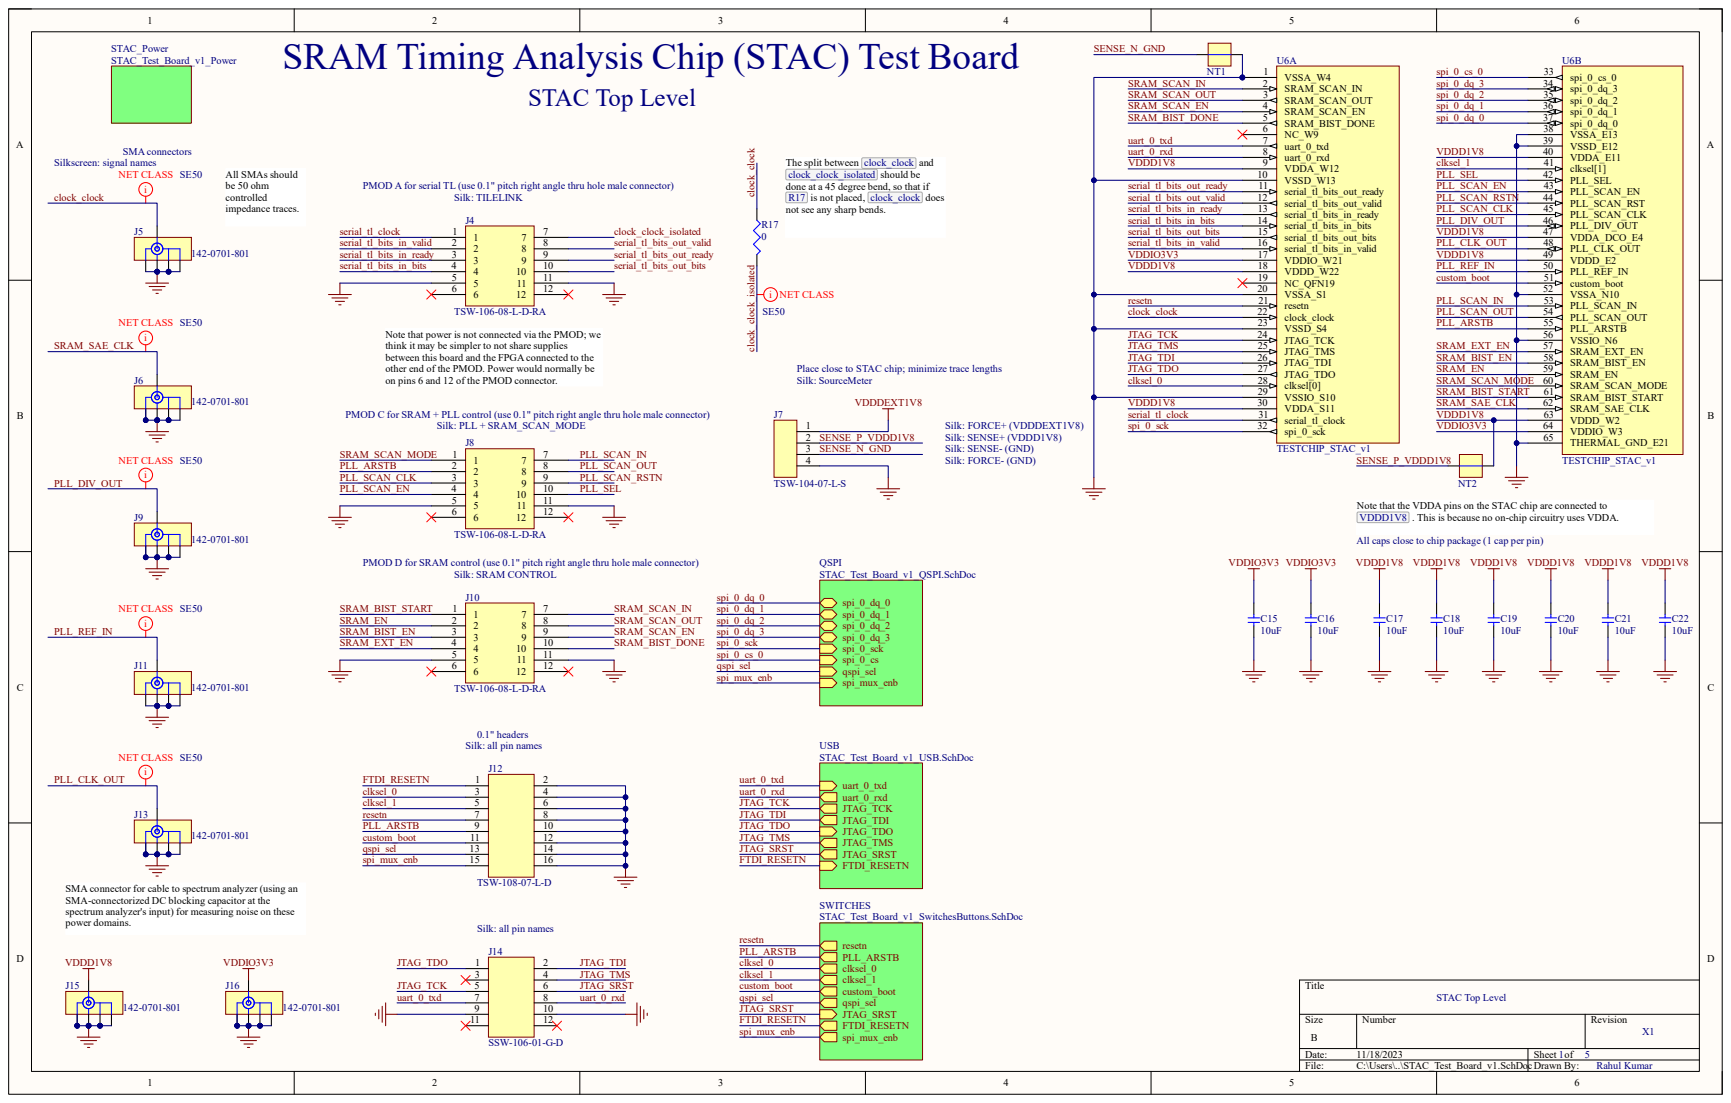
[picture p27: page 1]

The split between clock_clock and
clock_clock_isolated should be
done at a 45 degree bend, so that if
R17 is not placed, clock_clock does
not see any sharp bends.

PMOD A for serial TL (use 0.1" pitch right angle thru hole male connector)

Note that power is not connected via the PMOD; we
think it may be simpler to not share supplies
between this board and the FPGA connected to the
other end of the PMOD. Power would normally be
on pins 6 and 12 of the PMOD connector.

Place close to STAC chip; minimize trace lengths
Silk: SourceMeter

PMOD C for SRAM + PLL control (use 0.1" pitch right angle thru hole male connector)

Note that the VDDA pins on the STAC chip are connected to
VDDD1V8 . This is because no on-chip circuitry uses VDDA.

All caps close to chip package (1 cap per pin)

0.1" headers
Silk: all pin names

SMA connector for cable to spectrum analyzer (using an
SMA-connectorized DC blocking capacitor at the
spectrum analyzer's input) for measuring noise on these
power domains.

## 1st stage LDO (6V->5V)

Silk: VSUPPLYPROT6V | Silk: 5V

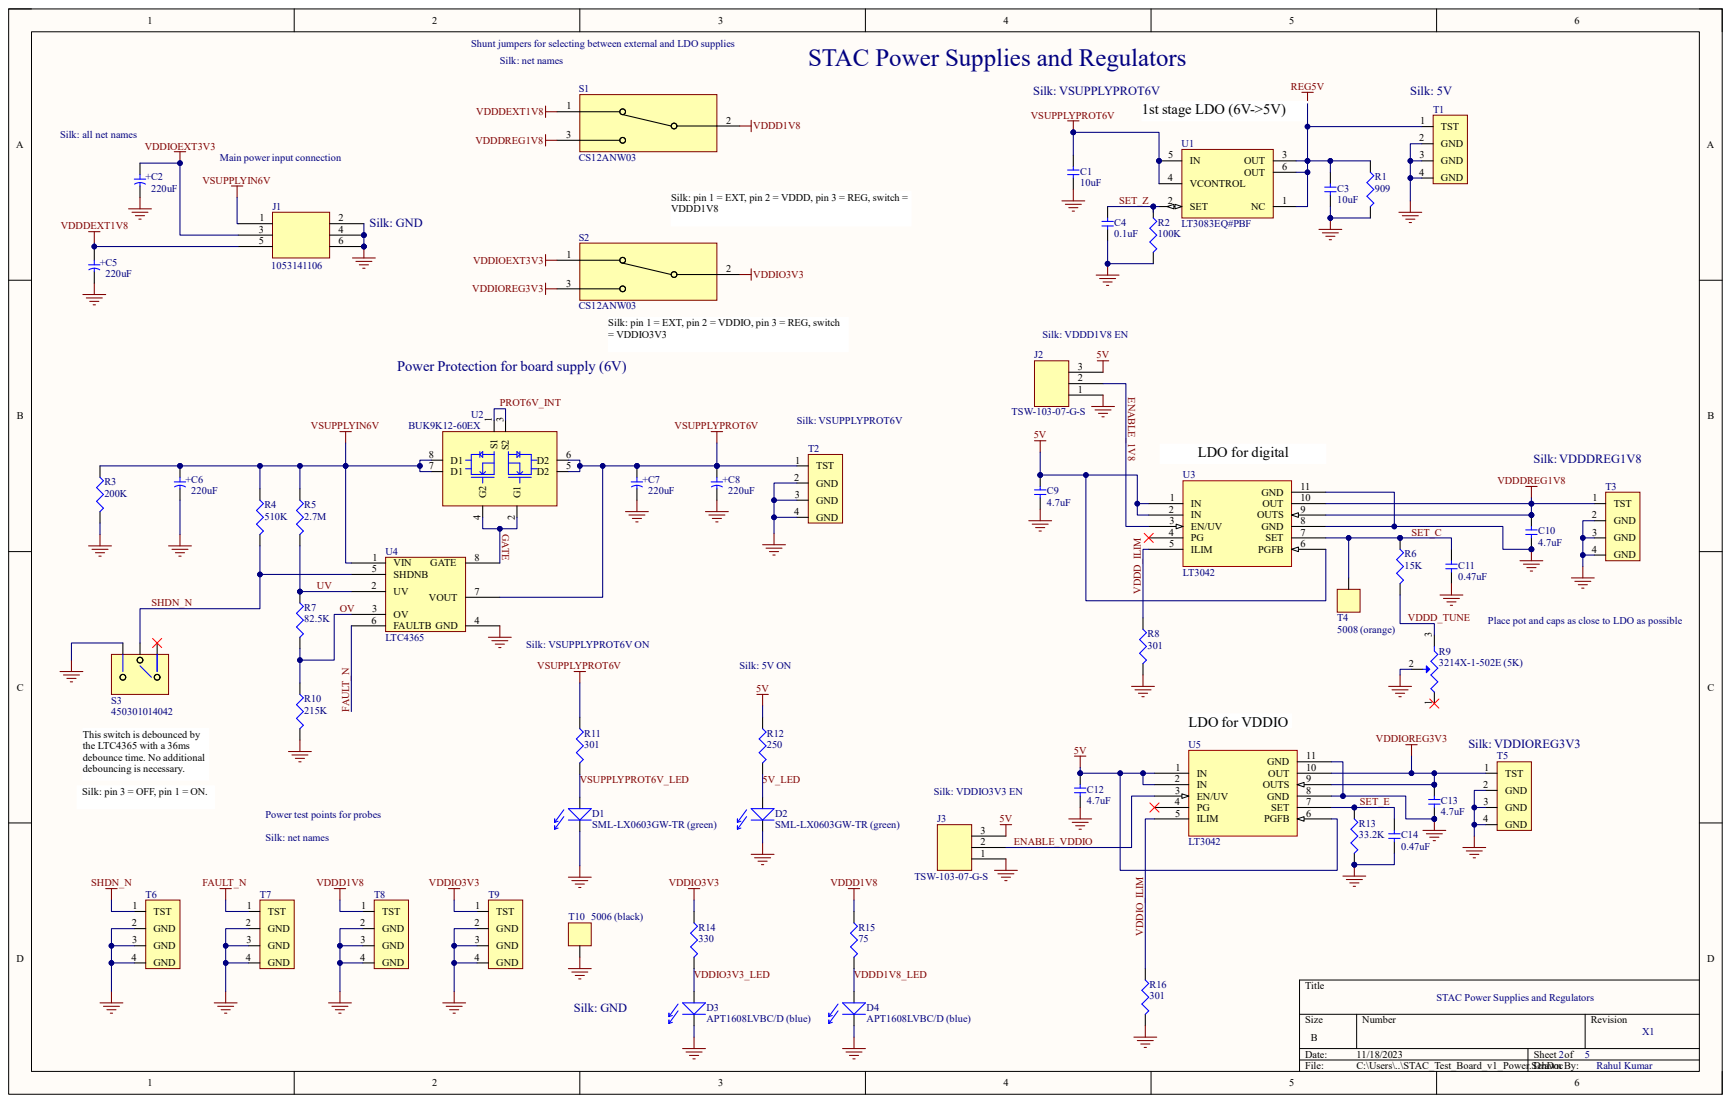
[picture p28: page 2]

Shunt jumpers for selecting between external and LDO supplies
Silk: net names

STAC Power Supplies and Regulators

Silk: all net names

Silk: pin 1 = EXT, pin 2 = VDDD, pin 3 = REG, switch =
VDDD1V8

CS12ANW03
Silk: pin 1 = EXT, pin 2 = VDDIO, pin 3 = REG, switch
= VDDIO3V3

Power Protection for board supply (6V)

Place pot and caps as close to LDO as possible

This switch is debounced by
the LTC4365 with a 36ms
debounce time. No additional
debouncing is necessary.

Silk: pin 3 = OFF, pin 1 = ON.

Power test points for probes

# VDDIO3V3 TXLED

# VDDIO3V3 RXLED

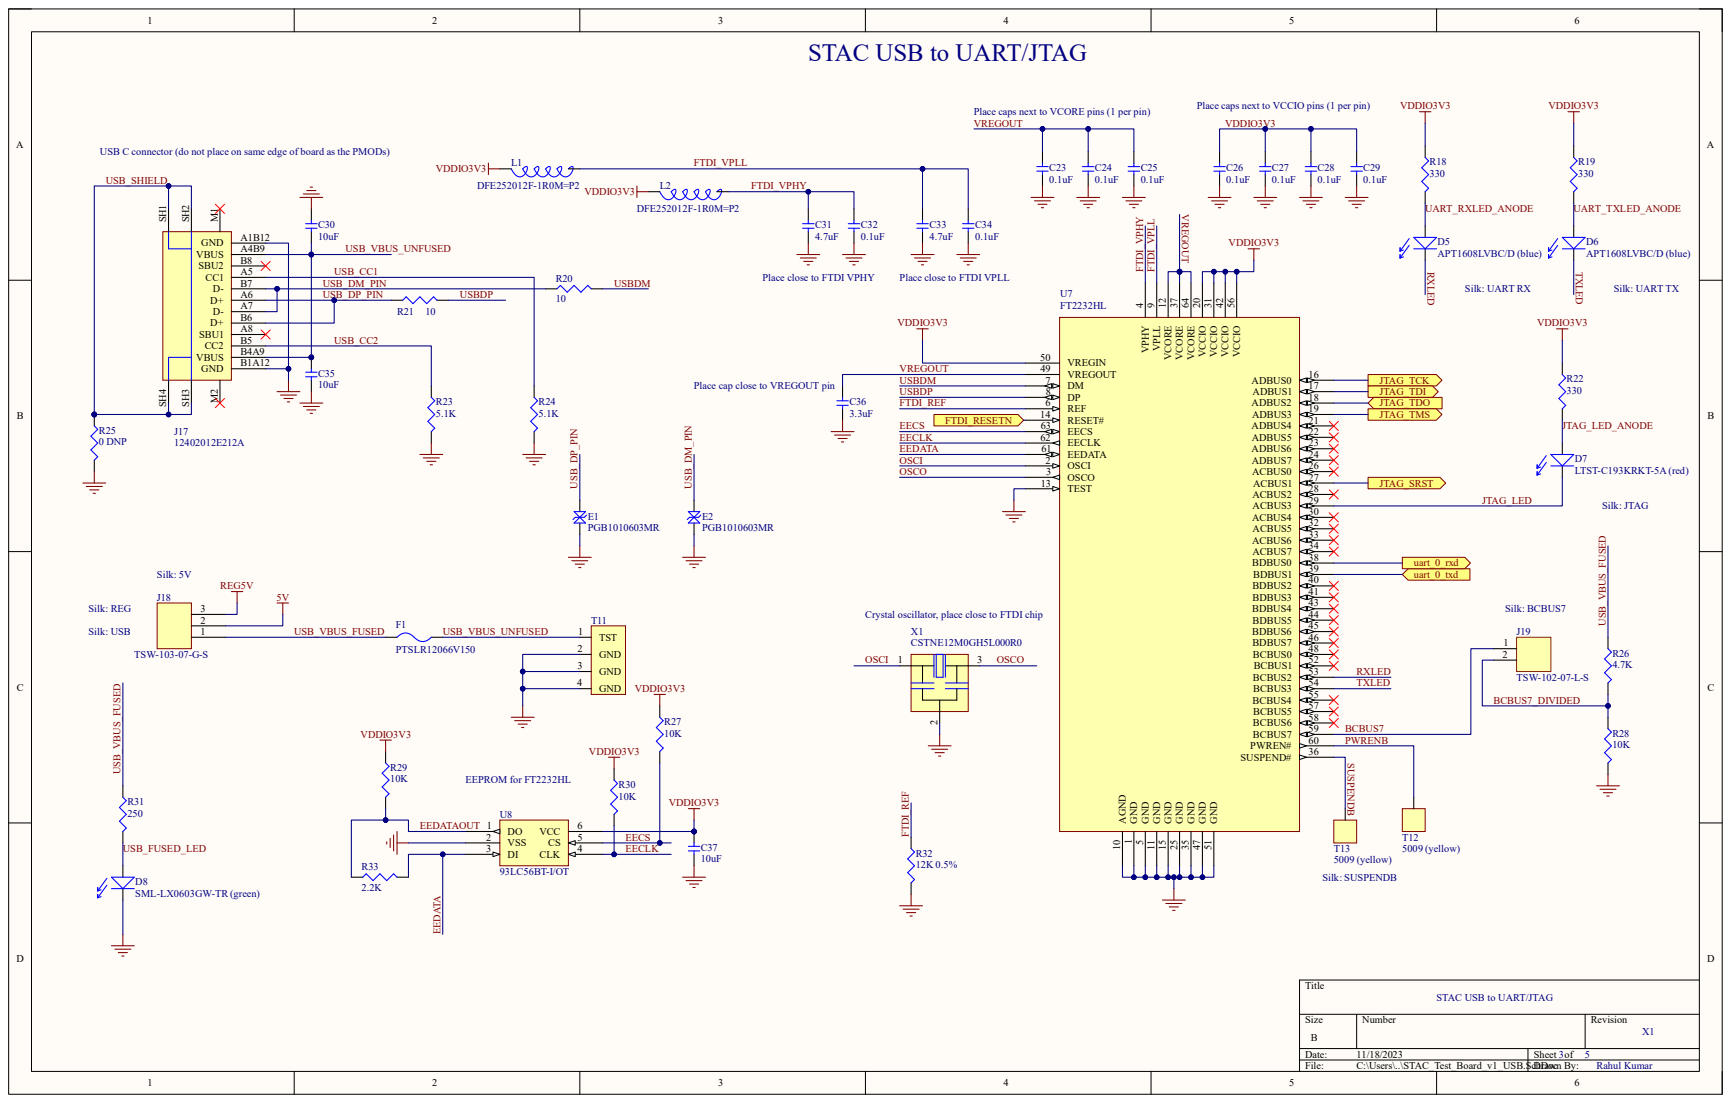
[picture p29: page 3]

STAC USB to UART/JTAG

Place caps next to VCORE pins (1 per pin)
VREGOUT

Place caps next to VCCIO pins (1 per pin)
VDDIO3V3

USB C connector (do not place on same edge of board as the PMODs)

Place cap close to VREGOUT pin

Crystal oscillator, place close to FTDI chip

5 GND 11 GND 15 GND 25 GND 35 GND 47 GND 51

# STAC Quad-SPI Peripherals

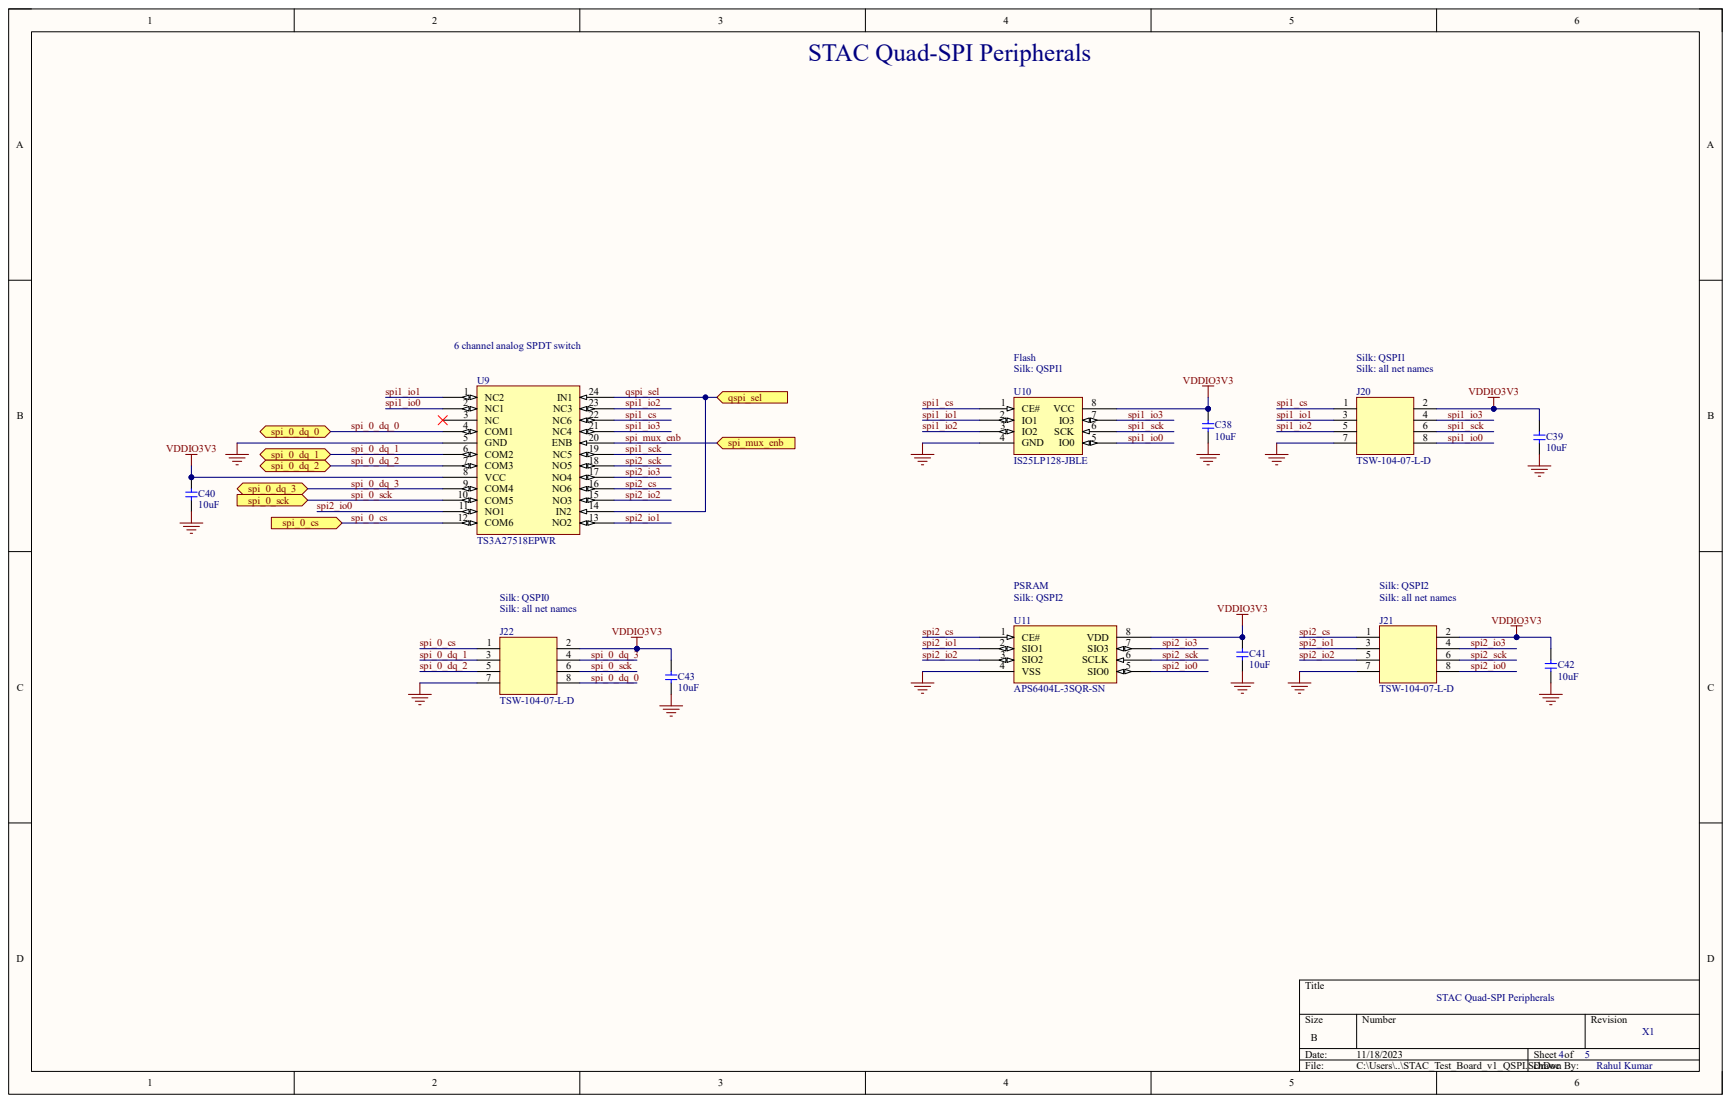
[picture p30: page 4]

6 channel analog SPDT switch

Silk: QSPI1
Silk: all net names

Silk: QSPI2

Silk: QSPI0

STAC Quad-SPI Peripherals

# STAC User Switches and Buttons

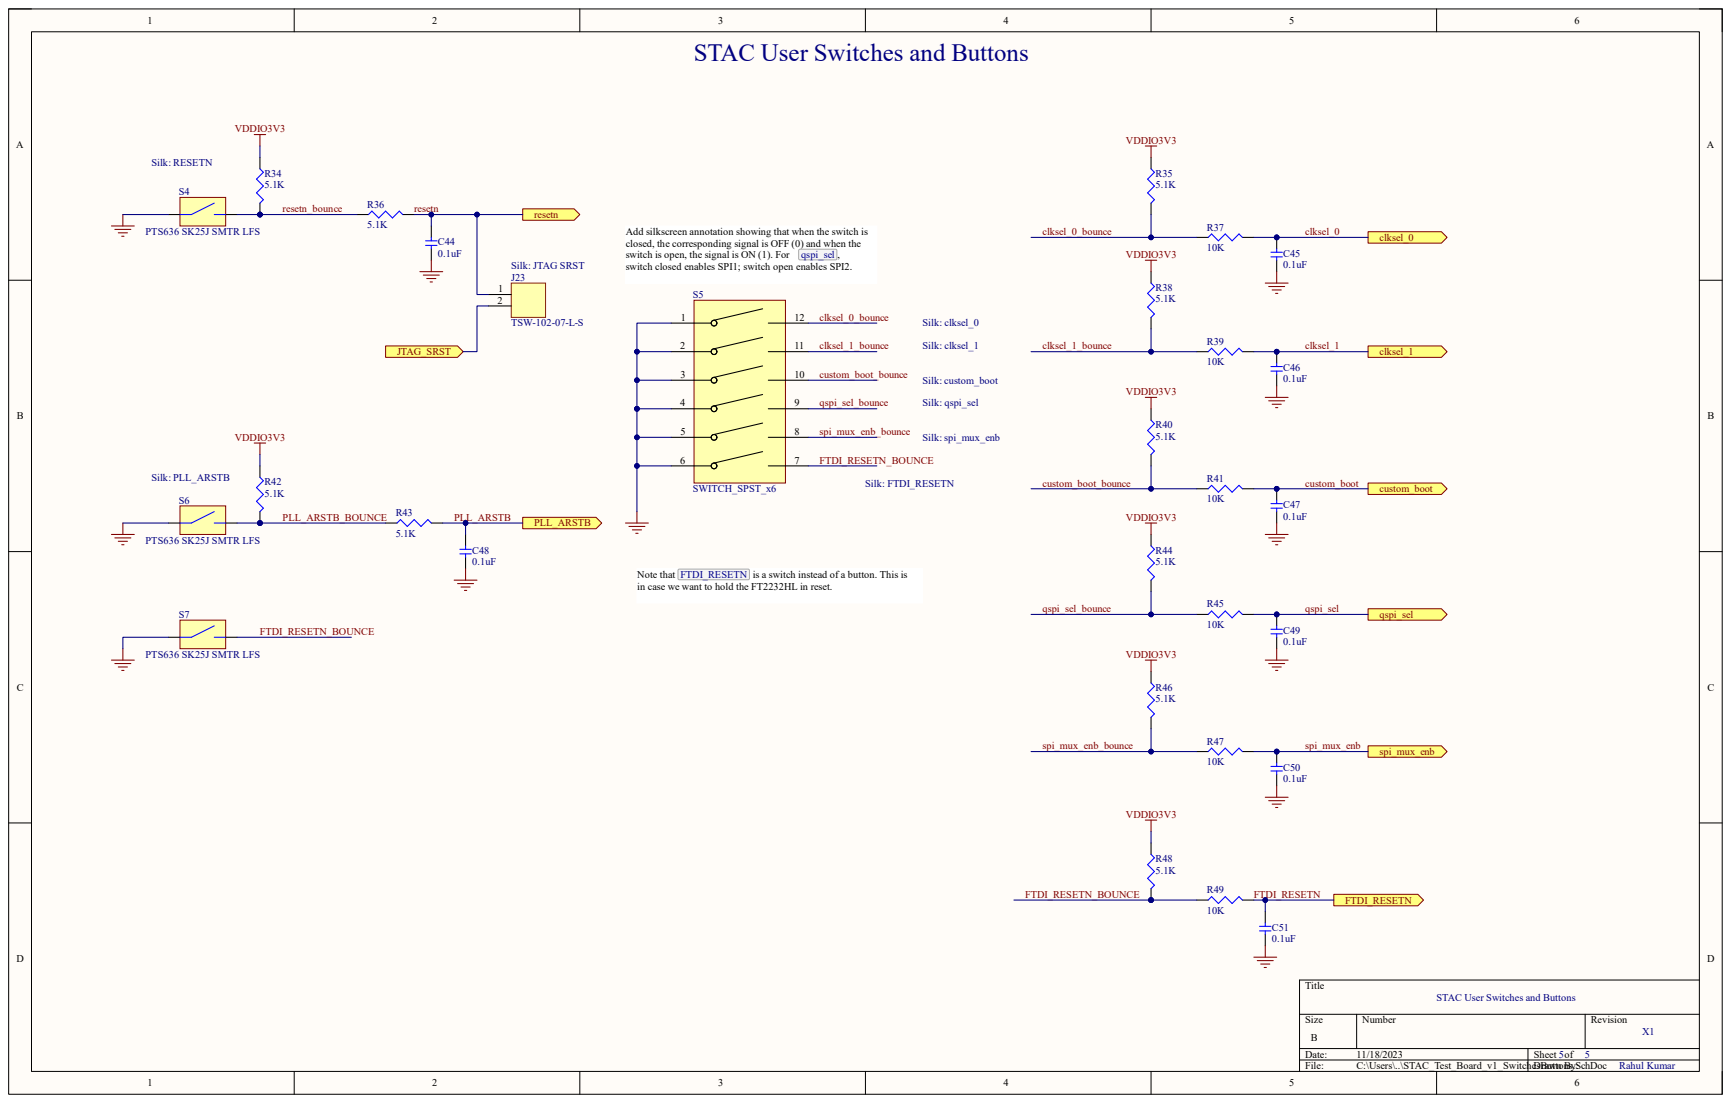
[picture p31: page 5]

Add silkscreen annotation showing that when the switch is
closed, the corresponding signal is OFF (0) and when the
switch is open, the signal is ON (1). For qspi_sel ,
switch closed enables SPI1; switch open enables SPI2.

Note that FTDI_RESETN is a switch instead of a button. This is
in case we want to hold the FT2232HL in reset.

STAC User Switches and Buttons

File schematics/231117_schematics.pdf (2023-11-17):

# 0 clock_clock clock_clock_isolated

# SRAM Timing Analysis Chip (STAC) Test Board

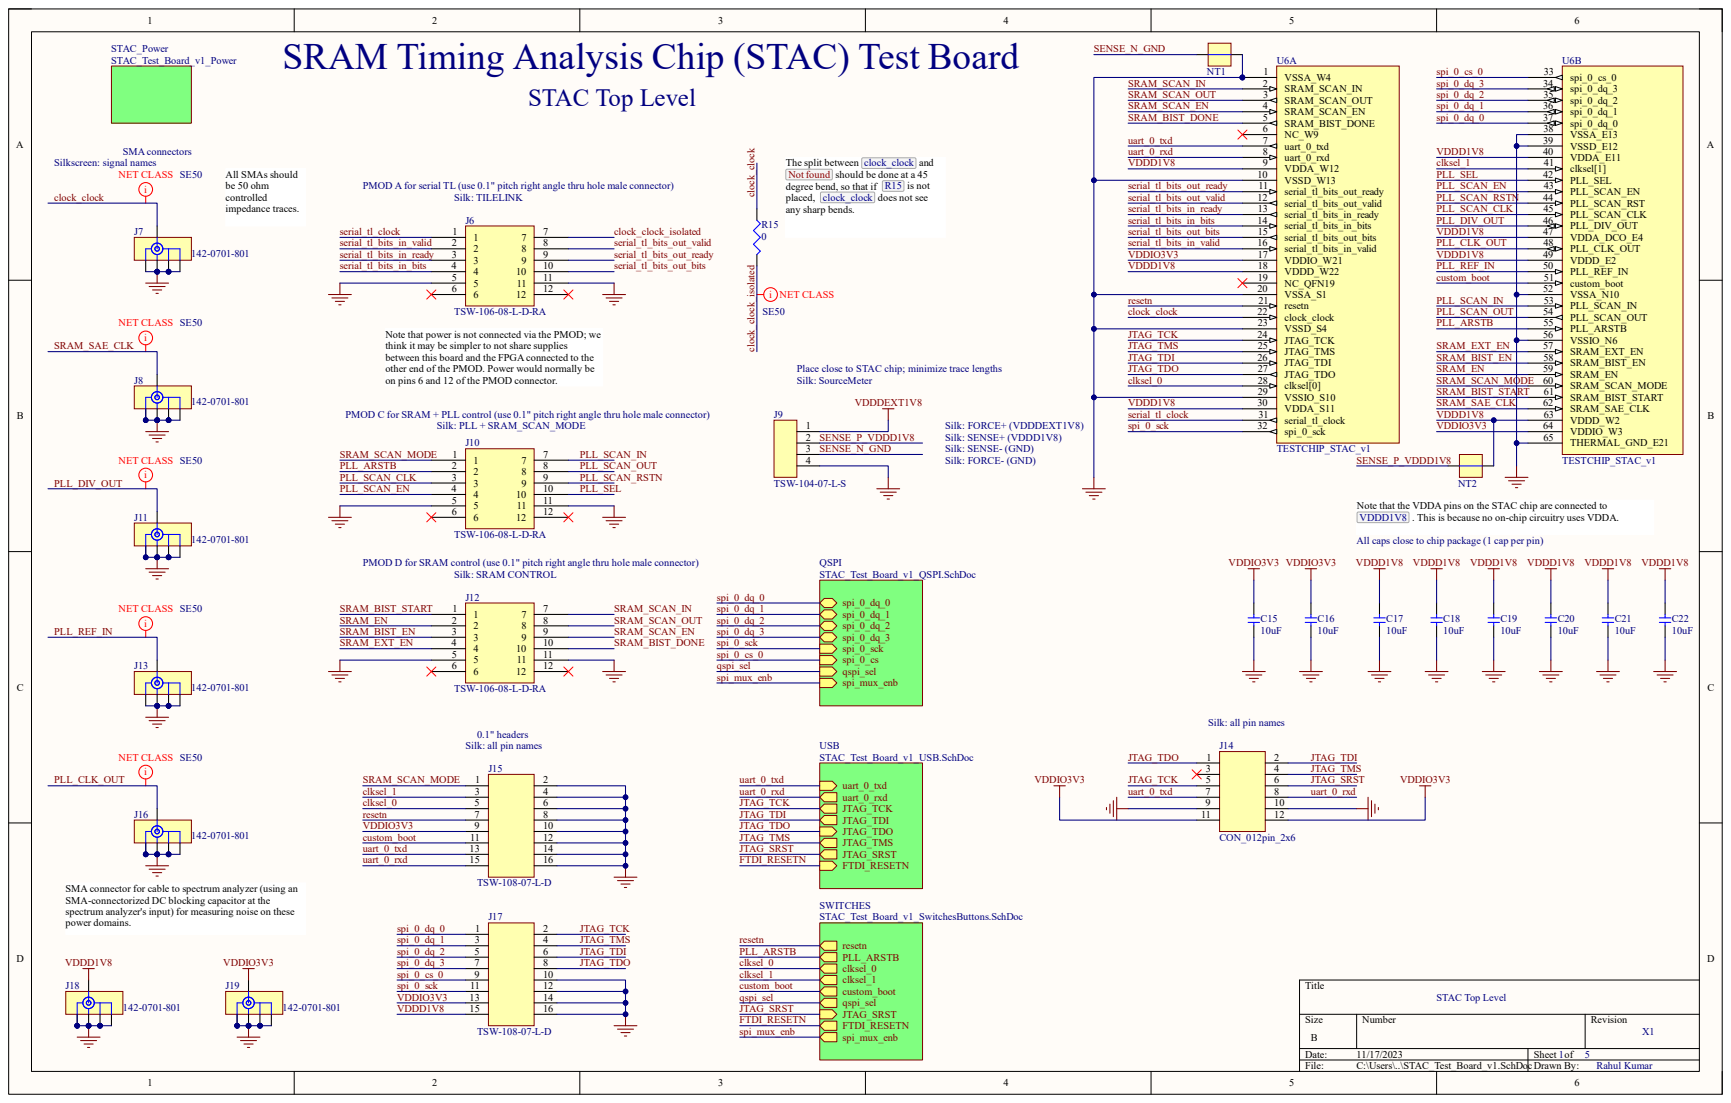
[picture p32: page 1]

The split between clock_clock and
Not found should be done at a 45
degree bend, so that if R15 is not
placed, clock_clock does not see
any sharp bends.

PMOD A for serial TL (use 0.1" pitch right angle thru hole male connector)

Note that power is not connected via the PMOD; we
think it may be simpler to not share supplies
between this board and the FPGA connected to the
other end of the PMOD. Power would normally be
on pins 6 and 12 of the PMOD connector.

Place close to STAC chip; minimize trace lengths
Silk: SourceMeter

PMOD C for SRAM + PLL control (use 0.1" pitch right angle thru hole male connector)

Note that the VDDA pins on the STAC chip are connected to
VDDD1V8 . This is because no on-chip circuitry uses VDDA.

All caps close to chip package (1 cap per pin)

0.1" headers
Silk: all pin names

SMA connector for cable to spectrum analyzer (using an
SMA-connectorized DC blocking capacitor at the
spectrum analyzer's input) for measuring noise on these
power domains.

## 1st stage LDO (6V->5V)

Silk: VSUPPLYPROT6V | Silk: 5V

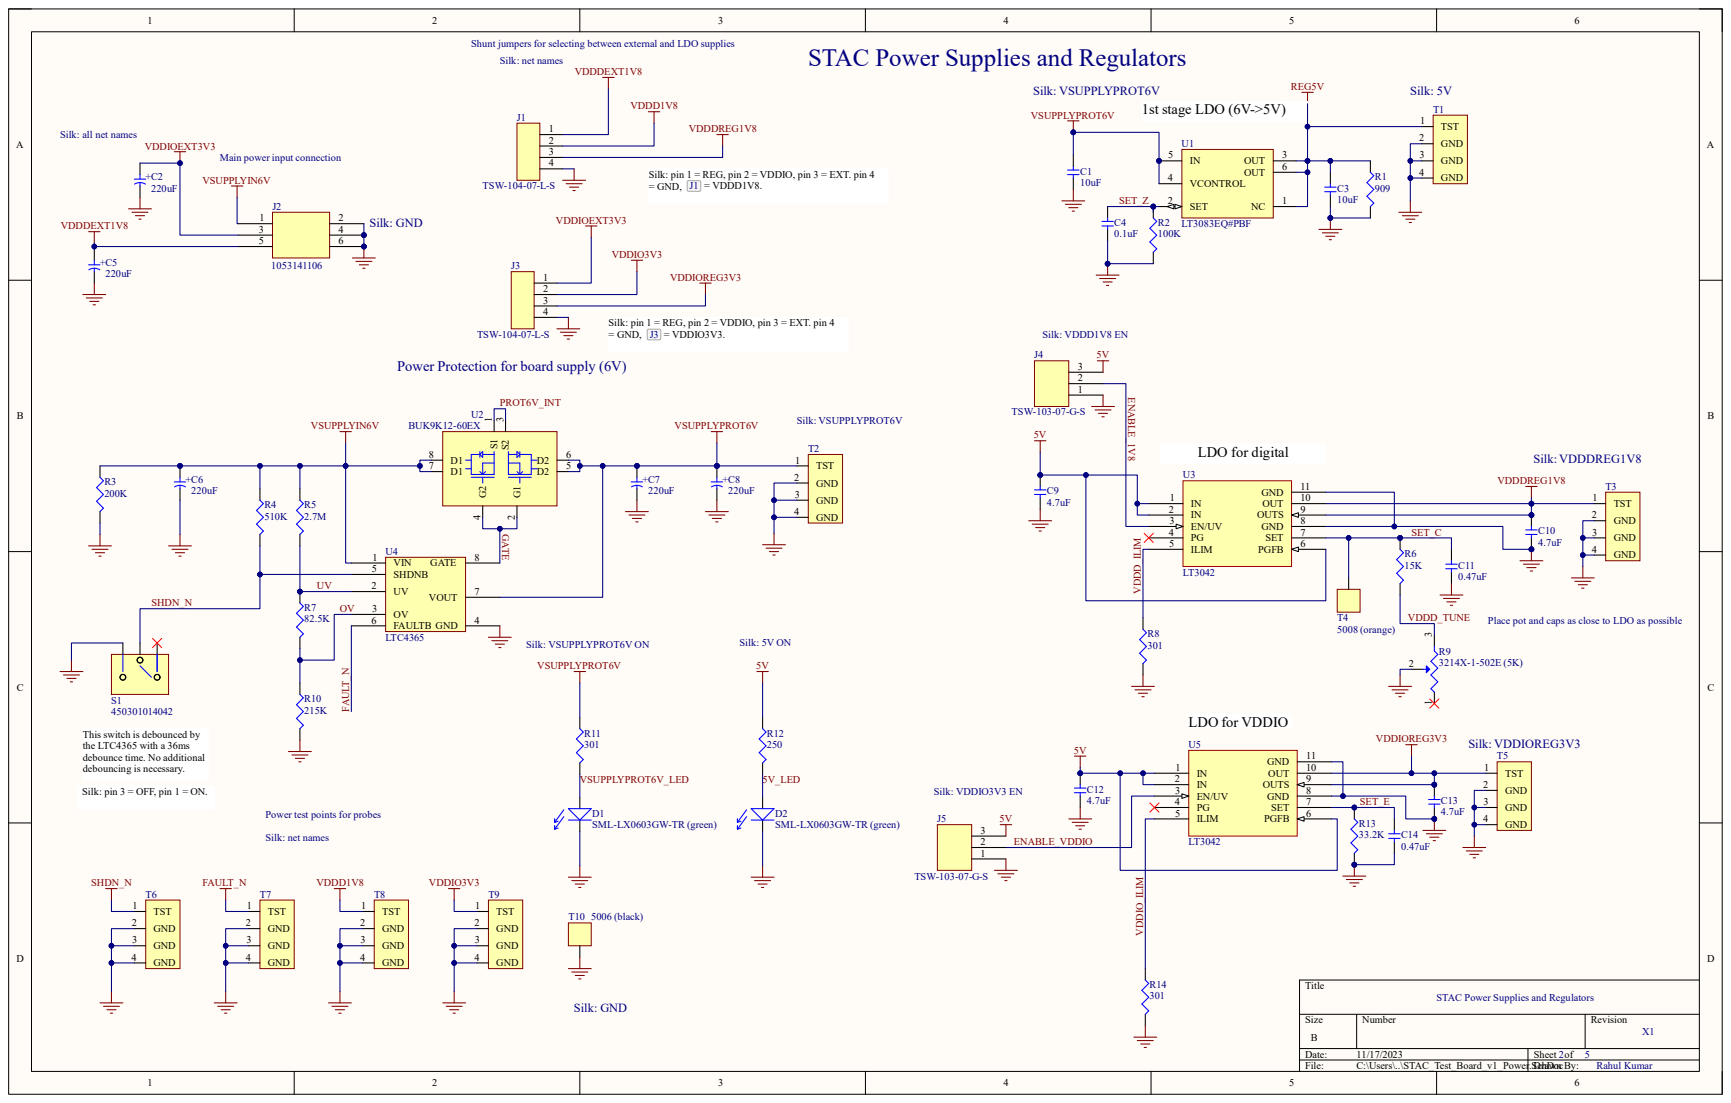
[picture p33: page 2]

Shunt jumpers for selecting between external and LDO supplies
Silk: net names

STAC Power Supplies and Regulators

Silk: all net names

Silk: pin 1 = REG, pin 2 = VDDIO, pin 3 = EXT. pin 4
= GND, J1 = VDDD1V8.

= GND, J3 = VDDIO3V3.

Power Protection for board supply (6V)

Place pot and caps as close to LDO as possible

This switch is debounced by
the LTC4365 with a 36ms
debounce time. No additional
debouncing is necessary.

Silk: pin 3 = OFF, pin 1 = ON.

Power test points for probes

# VDDIO3V3 TXLED

# VDDIO3V3 RXLED


STAC USB to UART/JTAG

Place caps next to VCORE pins (1 per pin)
VREGOUT

Place caps next to VCCIO pins (1 per pin)
VDDIO3V3

USB C connector (do not place on same edge of board as the PMODs)

Place cap close to VREGOUT pin

Crystal oscillator, place close to FTDI chip

5 GND 11 GND 15 GND 25 GND 35 GND 47 GND 51

# STAC Quad-SPI Peripherals


6 channel analog SPDT switch

Silk: QSPI1
Silk: all net names

Silk: QSPI0

Silk: QSPI2

STAC Quad-SPI Peripherals

# STAC User Switches and Buttons


Add silkscreen annotation showing that when the switch is
closed, the corresponding signal is OFF (0) and when the
switch is open, the signal is ON (1). For qspi_sel ,
switch closed enables SPI1; switch open enables SPI2.

STAC User Switches and Buttons

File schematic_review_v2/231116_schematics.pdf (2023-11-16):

# 0 clock_clock clock_clock_isolated

# SRAM Timing Analysis Chip (STAC) Test Board


The split between clock_clock and
clock_clock_isolated should be
done at a 45 degree bend, so that if
R14 is not placed, clock_clock does
not see any sharp bends.

PMOD A for serial TL (use 0.1" pitch right angle thru hole male connector)

Note that power is not connected via the PMOD; we
think it may be simpler to not share supplies
between this board and the FPGA connected to the
other end of the PMOD. Power would normally be
on pins 6 and 12 of the PMOD connector.

Place close to STAC chip; minimize trace lengths
Silk: SourceMeter

PMOD C for SRAM + PLL control (use 0.1" pitch right angle thru hole male connector)

Note that the VDDA pins on the STAC chip are connected to
VDDD1V8 . This is because no on-chip circuitry uses VDDA.

All caps close to chip package (1 cap per pin)

0.1" headers
Silk: all pin names

SMA connector for cable to spectrum analyzer (using an
SMA-connectorized DC blocking capacitor at the
spectrum analyzer's input) for measuring noise on these
power domains.

## 1st stage LDO (6V->4.66V)

Silk: VSUPPLYPROT6V | Silk: 4V66


Shunt jumpers for selecting between external and LDO supplies
Silk: net names

STAC Power Supplies and Regulators

Silk: all net names

Silk: pin 1 = REG, pin 2 = VDDIO, pin 3 = EXT. pin 4
= GND, J1 = VDDD1V8.

= GND, J3 = VDDIO3V3.

Power Protection for board supply (6V)

Place pot and caps as close to LDO as possible

This switch is debounced by
the LTC4365 with a 36ms
debounce time. No additional
debouncing is necessary.

Silk: pin 3 = OFF, pin 1 = ON.

Power test points for probes

# VDDIO3V3 TXLED

# VDDIO3V3 RXLED


STAC USB to UART/JTAG

Place caps next to VCORE pins (1 per pin)
VREGOUT

Place caps next to VCCIO pins (1 per pin)
VDDIO3V3

USB C connector (do not place on same edge of board as the PMODs)

Place cap close to VREGOUT pin

Crystal oscillator, place close to FTDI chip

5 GND 11 GND 15 GND 25 GND 35 GND 47 GND 51

# STAC Quad-SPI Peripherals

Title; Size; Number; Revision; Date:; Sheet of; File:; C:\Users\..\STAC_Test_Board_v1_QSPI.SchDoc Drawn By:; NC2 1 NC1 2 NC 3 COM1 4 GND 5 COM2 6 COM3 7 VCC 8 COM4 9 COM5 10 NO1 11; COM6 12; 19 ENB; TS3A27518EPWR; VDDIO_3V3; spi1_io1 spi1_io0; spi2_io0; qspi_sel spi1_io2 spi1_cs spi1_io3 spi_mux_enb spi1_sck spi2_sck spi2_io3 spi2_cs spi2_io2; spi2_io1; CE# 1 IO1 2 IO2 3 GND 4; SCK; VCC; IS25LP128-JBLE; spi1_cs spi1_io1 spi1_io2; spi1_io3 spi1_sck spi1_io0; CE# 1 SIO1 2 SIO2 3 VSS 4; SIO0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

6 channel analog SPDT switch

STAC Quad-SPI Peripherals

# STAC User Switches and Buttons


Add silkscreen annotation showing that when the switch is
closed, the corresponding signal is OFF (0) and when the
switch is open, the signal is ON (1). For qspi_sel ,
switch closed enables SPI1; switch open enables SPI2.

STAC User Switches and Buttons

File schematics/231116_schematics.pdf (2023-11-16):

# 0 clock_clock clock_clock_isolated

# SRAM Timing Analysis Chip (STAC) Test Board


The split between clock_clock and
clock_clock_isolated should be
done at a 45 degree bend, so that if
R14 is not placed, clock_clock does
not see any sharp bends.

PMOD A for serial TL (use 0.1" pitch right angle thru hole male connector)

Note that power is not connected via the PMOD; we
think it may be simpler to not share supplies
between this board and the FPGA connected to the
other end of the PMOD. Power would normally be
on pins 6 and 12 of the PMOD connector.

Place close to STAC chip; minimize trace lengths
Silk: SourceMeter

PMOD C for SRAM + PLL control (use 0.1" pitch right angle thru hole male connector)

Note that the VDDA pins on the STAC chip are connected to
VDDD1V8 . This is because no on-chip circuitry uses VDDA.

All caps close to chip package (1 cap per pin)

0.1" headers
Silk: all pin names

SMA connector for cable to spectrum analyzer (using an
SMA-connectorized DC blocking capacitor at the
spectrum analyzer's input) for measuring noise on these
power domains.

## 1st stage LDO (6V->4.66V)

Silk: VSUPPLYPROT6V | Silk: 4V66


Shunt jumpers for selecting between external and LDO supplies
Silk: net names

STAC Power Supplies and Regulators

Silk: all net names

Silk: pin 1 = REG, pin 2 = VDDIO, pin 3 = EXT. pin 4
= GND, J1 = VDDD1V8.

= GND, J3 = VDDIO3V3.

Power Protection for board supply (6V)

Place pot and caps as close to LDO as possible

This switch is debounced by
the LTC4365 with a 36ms
debounce time. No additional
debouncing is necessary.

Silk: pin 3 = OFF, pin 1 = ON.

Power test points for probes

# VDDIO3V3 TXLED

# VDDIO3V3 RXLED


STAC USB to UART/JTAG

Place caps next to VCORE pins (1 per pin)
VREGOUT

Place caps next to VCCIO pins (1 per pin)
VDDIO3V3

USB C connector (do not place on same edge of board as the PMODs)

Place cap close to VREGOUT pin

Crystal oscillator, place close to FTDI chip

5 GND 11 GND 15 GND 25 GND 35 GND 47 GND 51

# STAC Quad-SPI Peripherals

Title; Size; Number; Revision; Date:; Sheet of; File:; C:\Users\..\STAC_Test_Board_v1_QSPI.SchDoc Drawn By:; NC2 1 NC1 2 NC 3 COM1 4 GND 5 COM2 6 COM3 7 VCC 8 COM4 9 COM5 10 NO1 11; COM6 12; 19 ENB; TS3A27518EPWR; VDDIO_3V3; spi1_io1 spi1_io0; spi2_io0; qspi_sel spi1_io2 spi1_cs spi1_io3 spi_mux_enb spi1_sck spi2_sck spi2_io3 spi2_cs spi2_io2; spi2_io1; CE# 1 IO1 2 IO2 3 GND 4; SCK; VCC; IS25LP128-JBLE; spi1_cs spi1_io1 spi1_io2; spi1_io3 spi1_sck spi1_io0; CE# 1 SIO1 2 SIO2 3 VSS 4; SIO0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

6 channel analog SPDT switch

STAC Quad-SPI Peripherals

# STAC User Switches and Buttons


Add silkscreen annotation showing that when the switch is
closed, the corresponding signal is OFF (0) and when the
switch is open, the signal is ON (1). For qspi_sel ,
switch closed enables SPI1; switch open enables SPI2.

STAC User Switches and Buttons

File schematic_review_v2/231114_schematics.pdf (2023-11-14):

# 0 clock_clock clock_clock_isolated

# SRAM Timing Analysis Chip (STAC) Test Board


The split between clock_clock and
clock_clock_isolated should be
done at a 45 degree bend, so that if
R14 is not placed, clock_clock does
not see any sharp bends.

PMOD A for serial TL (use 0.1" pitch right angle thru hole male connector)

Note that power is not connected via the PMOD; we
think it may be simpler to not share supplies
between this board and the FPGA connected to the
other end of the PMOD. Power would normally be
on pins 6 and 12 of the PMOD connector.

Place close to STAC chip; minimize trace lengths
Silk: SourceMeter

PMOD C for SRAM + PLL control (use 0.1" pitch right angle thru hole male connector)

Note that the VDDA pins on the STAC chip are connected to
VDDD1V8 . This is because no on-chip circuitry uses VDDA.

All caps close to chip package (1 cap per pin)

0.1" headers
Silk: all pin names

SMA connector for cable to spectrum analyzer (using an
SMA-connectorized DC blocking capacitor at the
spectrum analyzer's input) for measuring noise on these
power domains.

## 1st stage LDO (6V->4.66V)

Silk: VSUPPLYPROT6V | Silk: 4V66


Shunt jumpers for selecting between external and LDO supplies
Silk: net names

STAC Power Supplies and Regulators

Silk: all net names

Silk: pin 1 = REG, pin 2 = VDDIO, pin 3 = EXT. pin 4
= GND, J1 = VDDD1V8.

= GND, J3 = VDDIO3V3.

Power Protection for board supply (6V)

Place pot and caps as close to LDO as possible

This switch is debounced by
the LTC4365 with a 36ms
debounce time. No additional
debouncing is necessary.

Silk: pin 3 = OFF, pin 1 = ON.

Power test points for probes

# VDDIO3V3 TXLED

# VDDIO3V3 RXLED


STAC USB to UART/JTAG

Place caps next to VCORE pins (1 per pin)
VREGOUT

Place caps next to VCCIO pins (1 per pin)
VDDIO3V3

USB C connector (do not place on same edge of board as the PMODs)

Place cap close to VREGOUT pin

Crystal oscillator, place close to FTDI chip

5 GND 11 GND 15 GND 25 GND 35 GND 47 GND 51 THERMAL 65

# STAC Quad-SPI Peripherals

Title; Size; Number; Revision; Date:; Sheet of; File:; C:\Users\..\STAC_Test_Board_v1_QSPI.SchDoc Drawn By:; NC2 1 NC1 2 NC 3 COM1 4 GND 5 COM2 6 COM3 7 VCC 8 COM4 9 COM5 10 NO1 11; COM6 12; 19 ENB; TS3A27518EPWR; VDDIO_3V3; spi1_io1 spi1_io0; spi2_io0; qspi_sel spi1_io2 spi1_cs spi1_io3 spi_mux_enb spi1_sck spi2_sck spi2_io3 spi2_cs spi2_io2; spi2_io1; CE# 1 IO1 2 IO2 3 GND 4; SCK; VCC; IS25LP128-JBLE; spi1_cs spi1_io1 spi1_io2; spi1_io3 spi1_sck spi1_io0; CE# 1 SIO1 2 SIO2 3 VSS 4; SIO0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

6 channel analog SPDT switch

STAC Quad-SPI Peripherals

# STAC User Switches and Buttons


Add silkscreen annotation showing that when the switch is
closed, the corresponding signal is OFF (0) and when the
switch is open, the signal is ON (1). For qspi_sel ,
switch closed enables SPI1; switch open enables SPI2.

STAC User Switches and Buttons

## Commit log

2023-10-05 add digital headers, power LEDs
    [STAC_Test_Board_v1.SchDoc, STAC_Test_Board_v1_Power.SchDoc]
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2023-10-10 add PLL headers, power headers, minor revisions
    [STAC_Test_Board_v1.SchDoc, STAC_Test_Board_v1_Power.SchDoc]
2023-10-18 update power circuitry, simplify LEDs
    [STAC_PCB.PrjPcb, STAC_Test_Board_v1.SchDoc, STAC_Test_Board_v1_Power.SchDoc]
2023-10-18 add supply caps adjacent to stac chip package
    [STAC_Test_Board_v1.SchDoc]
2023-10-21 sch changes morris 1020
    [STAC_PCB.PrjPcb, STAC_Test_Board_v1.SchDoc, STAC_Test_Board_v1_Power.SchDoc]
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2023-10-25 add component numbers; fix power connections
    [STAC_Test_Board_v1.SchDoc, STAC_Test_Board_v1_Power.SchDoc]
2023-10-25 update silk, remove power switches, clean up schematic
    [STAC_Test_Board_v1.SchDoc, STAC_Test_Board_v1_Power.SchDoc]
2023-10-25 use testpoints instead of headers to be compatible with passive probes with springy ground clips
    [STAC_Test_Board_v1.SchDoc, STAC_Test_Board_v1_Power.SchDoc]
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2023-10-26 updates to schematic, layout & Board Physical Plan
    [STAC_PCB.PrjPcb, STAC_Test_Board_v1.SchDoc, STAC_Test_Board_v1_Power.SchDoc]
2023-10-26 Update STAC schematic symbol, reorder signal pins
    [STAC_Test_Board_v1.SchDoc, STAC_Test_Board_v1_Power.SchDoc]
2023-10-26 label unnamed net GATE
    [STAC_Test_Board_v1_Power.SchDoc]
2023-10-26 Assigned footprint to new version of STAC chpi on schematic, updated pcb side
    [STAC_Test_Board_v1.SchDoc]
2023-10-26 exported schematic pdf and copied it to Schematics_pdf folder
    [STAC-v1-pcb.PcbDoc]
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2023-11-08 updates to stac pcb: 3 pmods, debounced switches/rst button, 0 ohm R isolated clock, uart/jtag ftdi controller chip
    [STAC_Breakout_PCB.PcbDoc, STAC_Breakout_PCB.SchDoc, STAC_Test_Board_v1.SchDoc]
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2023-11-08 update designators in all sheets
    [STAC_PCB.PrjPcb, STAC_Test_Board_v1.SchDoc]
2023-11-08 use female headers for flash board, use spst wurth switch
    [STAC_Test_Board_v1.SchDoc]
2023-11-09 add breakout pcb for is25lp128
    [IS25LP128_Breakout_PCB.PcbDoc, IS25LP128_Breakout_PCB.PrjPcb, IS25LP128_Breakout_PCB.SchDoc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]
2023-11-09 make clearer which caps correspond to which pins
    [IS25LP128_Breakout_PCB.PrjPcb, STAC_Test_Board_v1.SchDoc]
2023-11-09 change to general 12K 0.5% resistor, change FT2232H to FT2232HL
    [STAC_Test_Board_v1.SchDoc]
2023-11-09 reannotate schematics, add footprints, change 5K resistors to 5.1K
    [STAC_Test_Board_v1.SchDoc, STAC_Test_Board_v1_Power.SchDoc]
2023-11-09 fix annotations, add comment on qspi breakout board
    [STAC_Test_Board_v1.SchDoc, STAC_Test_Board_v1_Power.SchDoc]
2023-11-10 fix usb c schematic symbol, use samtec vertical connector for sqspi
    [STAC_Test_Board_v1.SchDoc, STAC_Test_Board_v1_Power.SchDoc]
2023-11-10 reposition usb conn, resistor designators/part numbers, increase usb vbus decap, use updated mec2 connector symbol, label clock_clock_isolated as SE50
    [STAC_Test_Board_v1.SchDoc]
2023-11-10 fix enable vddd1v8 label, add PLL_ARSTB reset button
    [STAC_Test_Board_v1.SchDoc, STAC_Test_Board_v1_Power.SchDoc]
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2023-11-10 Increase number of power headers
    [STAC_Test_Board_v1.SchDoc, STAC_Test_Board_v1_Power.SchDoc]
2023-11-12 Add VDDD1V8 sense wire headers
    [STAC_Test_Board_v1.SchDoc, STAC_Test_Board_v1_Power.SchDoc]
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2023-11-12 use analog mux for qspi/flash, bring source meter connections close to chip on their own header pins
    [STAC_Test_Board_v1.SchDoc, STAC_Test_Board_v1_Power.SchDoc]
2023-11-13 Organize schematics across multiple size B sheets
    [STAC_PCB.PrjPcb, STAC_Test_Board_v1.SchDoc, STAC_Test_Board_v1_Power.SchDoc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]
2023-11-13 Fix net tie locations, edit Keithley sense header, add footprints, populate title blocks
    [STAC_Test_Board_v1.SchDoc, STAC_Test_Board_v1_Power.SchDoc, STAC_Test_Board_v1_QSPI.SchDoc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]
2023-11-13 add 4 wire header for Keithley source meter connection
    [STAC_Test_Board_v1.SchDoc, STAC_Test_Board_v1_Power.SchDoc, STAC_Test_Board_v1_QSPI.SchDoc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]
2023-11-13 fix off grid pins/ports/labels
    [STAC_Test_Board_v1_QSPI.SchDoc, STAC_Test_Board_v1_SwitchesButtons.SchDoc, STAC_Test_Board_v1_USB.SchDoc]
2023-11-13 push schematic changes to layout
    [STAC-v1-pcb.PcbDoc, STAC_Test_Board_v1_USB.SchDoc]
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2023-11-14 add ftdi reset btn, srst shunt jumper, jtag led
    [STAC_Test_Board_v1.SchDoc, STAC_Test_Board_v1_Power.SchDoc, STAC_Test_Board_v1_QSPI.SchDoc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]
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2023-11-15 update usb-c footprint from BWRC.PcbLib
    [STAC-v1-pcb.PcbDoc]
2023-11-15 coalesce component values, push to layout
    [STAC-v1-pcb.PcbDoc, STAC_Test_Board_v1_QSPI.SchDoc, STAC_Test_Board_v1_SwitchesButtons.SchDoc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]
2023-11-15 separate overlapping components in layout
    [STAC-v1-pcb.PcbDoc]
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2023-11-17 ft2232hl supply cm choke, add eeprom, power board off of usb, spi headers
    [STAC_Test_Board_v1.SchDoc, STAC_Test_Board_v1_Power.SchDoc, STAC_Test_Board_v1_QSPI.SchDoc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]
2023-11-17 post-review 2 schematic changes
    [STAC_Test_Board_v1.SchDoc, STAC_Test_Board_v1_Power.SchDoc, STAC_Test_Board_v1_QSPI.SchDoc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]
2023-11-19 add leds, use switches instead of jumpers for power selection, update resistor values
    [STAC_PCB.PrjPcb, STAC_Test_Board_v1.SchDoc, STAC_Test_Board_v1_Power.SchDoc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]
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2023-11-20 use alt schematic symbol for power connector, switches
    [STAC_PCB.PrjPcb, STAC_Test_Board_v1.SchDoc, STAC_Test_Board_v1_Power.SchDoc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]
2023-11-20 update resistor values, fix rxled/txled pin assignments, use low Vf led for 1.8V
    [STAC_Test_Board_v1.SchDoc, STAC_Test_Board_v1_Power.SchDoc, STAC_Test_Board_v1_QSPI.SchDoc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]
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2023-11-21 label 1uH inductors, push schematic to layout with rooms
    [STAC-v1-pcb.PcbDoc, STAC_PCB.PrjPcb, STAC_Test_Board_v1_QSPI.SchDoc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]
2023-11-21 update footprints from BWRC.PcbLib to STAC PcbDoc
    [STAC-v1-pcb.PcbDoc]
2023-11-21 use spi_0_cs_0 consistently; remove references to spi_0_cs
    [STAC_Test_Board_v1.SchDoc, STAC_Test_Board_v1_QSPI.SchDoc]
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2023-11-22 fix inductor footprint (should be 1008), push to layout
    [STAC-v1-pcb.PcbDoc, STAC_Test_Board_v1_USB.SchDoc]
2023-11-22 match to parts in PartSync; push to layout
    [STAC-v1-pcb.PcbDoc, STAC_Test_Board_v1.SchDoc, STAC_Test_Board_v1_SwitchesButtons.SchDoc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]
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2023-11-25 fix schematic bug, more layout
    [STAC_Test_Board_v1_USB.SchDoc]
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2023-11-26 fix order of SMAs; route SMA signals with 7.01 mil traces
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2023-12-01 fix silkscreen typos, clean up some routes
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2023-12-14 update lt3083 footprint, net tie footprint, regenerate files for RFQ
    [STAC_Test_Board_v1_Power.SchDoc]
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
